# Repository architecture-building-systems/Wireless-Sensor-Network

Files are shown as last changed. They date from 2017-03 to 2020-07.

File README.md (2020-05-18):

# Wireless Sensor Network

## Introduction
This repository contains all files needed to reproduce the Wireless Sensor Network (WSN) used for the Data-Driven Building Retrofit Research of the [A/S Chair](http://www.systems.arch.ethz.ch/). 
The WSN is intended to be deployed in residential buildings to collect sensor data for building model calibration. The microcontroller boards are based on the Arduino framework. For wireless communication, XBee radio modules are used.

See the [Wiki](https://github.com/architecture-building-systems/Wireless-Sensor-Network/wiki) for documentation, instructions, and other resources.

## Structure of the WSN
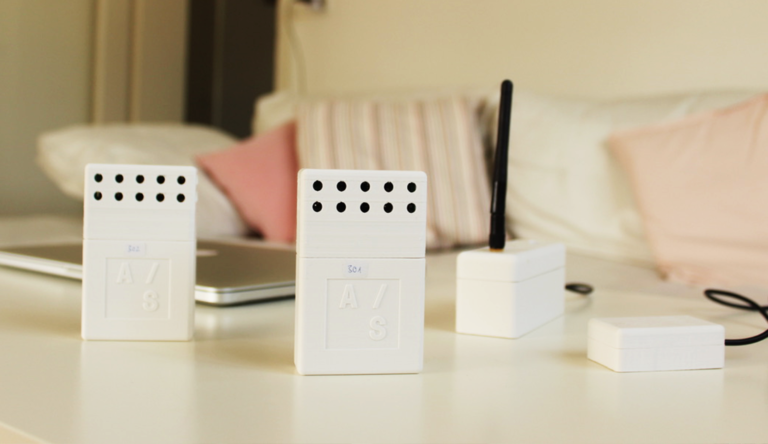
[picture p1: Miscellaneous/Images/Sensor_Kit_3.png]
Sensor-Kit
  
Sensor-Kit: (from left to right) two sensor nodes, gateway and router node

The WSN has a modular structure. The main components are the following:
* Gateway
* Router Node
* Sensor Node

On the sensor node, the sensor readings are performed and the data is relayed over router nodes to the gateway using the XBee network. The gateway forwards the data over cellular network to a web server, where the data is stored in a MySQL database. It is also possible to use a sensor node as data logger without any radio communication.

### Sensor Node
Sensor nodes consist of two parts: the main module and the sensor module. The sensor module interfaces the actual sensor(s). It reads out the sensor reading and transmits the result via the serial bus in a unified format to the main module. The main module interfaces the sensor module, radio transceiver, and the battery. It forwards the readings from the sensor module to the gateway. Both, the main module and the sensor module, can be programmed using the Arduino IDE.

#### Main Module
The main module is the same on all sensor nodes. It entails the following:
* Microcontroller (ATmega328p)
* Real-time clock (DS3231)
* Battery (2000mAh LiPo)
* SD-card socket
* XBee radio module (XB24CZ7WIT-004)
* Slide switch and LEDs for debugging
* Power jack for external power
* Connectors to sensor module

The tasks of the main module are:
* Scheduling (RTC or interrupt from sensor module)
* Interfacing the sensor module
* Interfacing XBee
* Interfacing SD-card
* Reading the charge state of the battery
* Switching between normal operation and debugging mode

#### Sensor Module
The sensor module interfaces the actual sensor(s). Each sensor or sensor configuration needs its own sensor module design.
The following sensor modules are available:
* Temperature and Humidity (SHT31)
* Luminosity (TSL2561)
* Pulse
* CO2 (S8)
* Heat Flux (gSKIN XO)
* Dual Temperature (DS18B20)
* Prototyping

There are two kinds of sensor modules: sensor modules for periodic measurements (fixed time interval) and sensor modules for event based measurements (interrupt driven). On the first power-up of the main module, the type of the sensor module is requested, in order to set the mode to periodic measurements or event based measurements. For periodic measurements, the main module is woken up by the RTC on the main module. It then turns on the power to the sensor module. After power-up of the sensor module, it reads out the sensor(s) and transmits the readings over the serial bus. Then the power to the sensor module is cut by the main module and the data is written to the SD-card and/or sent to the gateway via radio.
For event based measurements the sensor module is always powered on. The main module is woken up by an interrupt signal from the sensor module instead of the RTC. The data transfer is the same as for the periodic measurements. 

### Gateway
The gateway receives the data from the sensor nodes and relays the data to a web server via 3G cellular network. The gateway consists of Adafruit Feather 32u4 FONA and a XBee radio-module. The Adafruit Feather 32u4 FONA can be programmed using the Arduino framework. The gateway is powered via USB power supply and needs to be always powered on.

### Router Node
A router node consists of XBee-radio module and SparkFun XBee Explorer Regulated Board. The router node is powered by a wall adapter power supply. It always needs to be powered on.

## Publications
 * [Wireless sensor network for estimating building performance](https://sciencedirect.com/science/article/pii/S0926580519307472)
 * [An easily-deployable wireless sensor network for building energy performance assessment](https://www.sciencedirect.com/science/article/pii/S1876610217329077)
 
 ## Cite us


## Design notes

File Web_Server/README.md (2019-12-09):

# Webserver
Two tasks are assigned to the webserver: 
1. Inserting the measurement data into the database and 
2. Displaying the measured data. All scripts are written in PHP.

## Storing Measured Data
All the files for storing the measured data in the database are in the [/gateway2mysql/ directory](PHP/gateway2mysql/). The main file is [gateway2mysql.php](PHP/gateway2mysql/gateway2mysql.php), which is also called by the gateway. The data is attached as an URL-parameter.
Currently, battery warning messages and data from the heat flux sensors need to be treated separately, since these messages do not yet adhere to the standard formatting. 

## Displaying Data
Files for these tasks can be found in the [/vis/](PHP/vis/) directory. The main file is [isituprightnow_v4.php](PHP/vis/isituprightnow_v4.php). The site shows tables. The left hand side table gives an overview of the gateway activity. The gateway number is clickable and leads to an overview of the sensor nodes. The right hand side table gives an overview of all the sensor nodes of one gateway. The node id is clickable and links to a graph of the respective measured data.

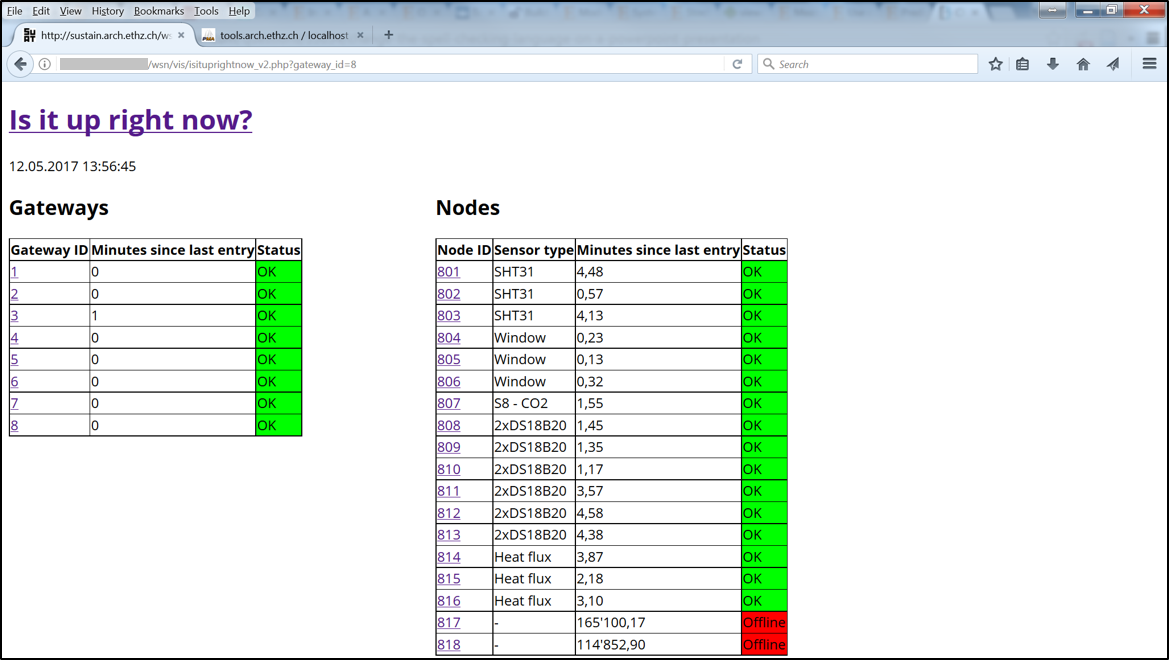
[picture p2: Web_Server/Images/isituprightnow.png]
Table
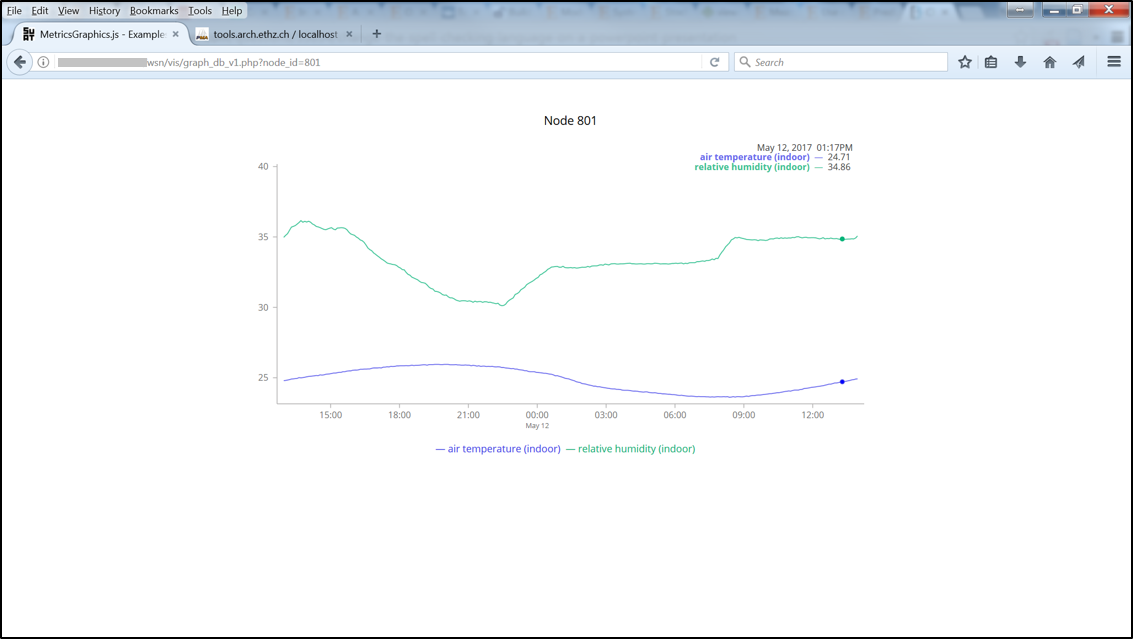
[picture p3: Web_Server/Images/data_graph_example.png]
Graph
 

## Setup
In order to setup the webserver the following needs to be done: 
* Import the MySQL database structure in phpMyAdmin using the SQL file in the [MySQL directory](MySQL).
* Copy the files from the folder [PHP](PHP) into the root directory of your webserver.
* Add the login credentials for the database to the [config file](PHP/config.php).
* Add the e-mail address of the admin to the [config file](PHP/config.php).
* Add the URL of your webserver to the Arduino [script for the gateway](../Gateway/Arduino). The URL should look something like this: yourdomainname.com/gateway2mysql/gateway2mysql.php

There are two main PHP scripts:
* [PHP/vis/isituprightnow_v4.php](PHP/vis/isituprightnow_v4.php) gives an overview of the status of sensor nodes.
* [PHP/gateway2mysql/gateway2mysql.php](PHP/gateway2mysql/gateway2mysql.php) is called by the gateways. It takes the payload message with the measured data, disaggregates it and inserts it in the database.

## A word of Caution
Some inputs might be properly sanitized. And database quere do not use prepared statements. Hence, there is some risk of cross-site scripting vulnerability. Thus, we strongly suggest to not expose the web-interface to the public and to only share it with trusted parties. Otherwise, one might risk damage or loss of all contents of the database.

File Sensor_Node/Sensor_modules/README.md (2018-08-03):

# Sensor Modules

We are currently revising all sensor modules.

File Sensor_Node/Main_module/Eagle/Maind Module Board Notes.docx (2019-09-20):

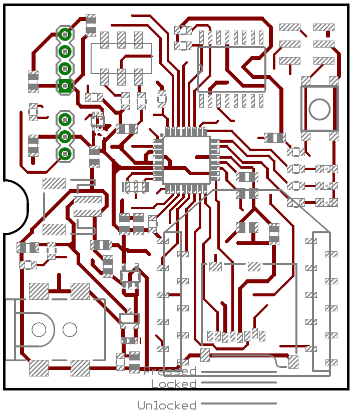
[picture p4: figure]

Board Notes

TOP

BOTTOM

Arduino ISP Connector:

MISO | | Top Right | VIN (3.3V)
SCK | | | GND
MOSI | Bot. Left | | RESET

Parts Assembly:

- Y1: Oscillator, orientation does not matter
- LEDs L1, L2, L3: Green marking towards East

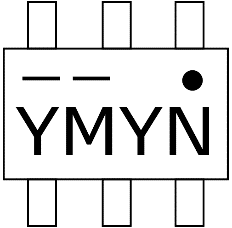
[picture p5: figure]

- U3: IC markings look like this when looking closely:
- D1: Diode, marking towards East

Sensor Module Connectors:

GND
to SM’s RXI
to SM’s TXO
Controlled SM Supply Voltage
Continuous supply voltage from SM
Continuous supply voltage towards SM
Wakeup interrupt from SM

DO NOT PLUG IN SUPPLY VOLTAGE JACK OF COMM. MODULE WHILE 3 PIN SENSOR MODULE CONNECTOR IS USED! (Because if sensor module is also externally powered, then there is a short between the two supply voltages through the “Continuous V from SM” or “Continuous V towards SM” pin)

For a periodic sensor module, only the 4 pin connector is needed. For an interrupting sensor module, the three pin connector is needed as well. Then the “Controlled SM Supply Voltage” pin does not have to be connected on the sensor module anymore, but it can be supplied through “Continuous supply voltage towards SM”, or if the sensor module has a constant power source, then the communication module can be supplied through “Continuous supply voltage from SM”.

Setup

- Program via Arduino ISP. In the Arduino IDE, the programmer that is selected must be “Arduino as ISP” and the program then upload using Sketch > Upload Using Programmer
- After assembling communication module: Burn bootloader via Arduino ISP (Tools > Burn Bootloader)
- If a XBee module is not found in XCTU, it is probably because it has been configured to be in sleep mode (SM = 1). To add the module in XCTU, you need to pull the sleep pin (= pin 9) to GND (= pin 10) while adding it and reading the parameters in XCTU.

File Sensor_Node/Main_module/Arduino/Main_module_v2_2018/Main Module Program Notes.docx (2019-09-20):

Program Notes

General

For periodic sensor modules, the communication module takes the first measurement 5 seconds after having been started.

The SD card is optional and can be inserted or left out without any additional configuration. The SD card can also be inserted when the communication module is already running. The SD card can be removed from a running communication module, however the tasks will draw a bit more energy from then on (reason unknown, seems to be something in the SD card library for Arduino) and the SD card cannot be reinserted (Unless the communication module is reset using the reset button).

Startup LED Indicators

At the start, the LEDs indicate successful initialization:

- LED 1 (bottom, red) turns on when the RTC has been initialized successfully
- LED 2 (middle, green) flashing while XBee is trying to join network, stays turned on when network successfully joined
- LED 3 (top, orange) turns on when SD card successfully initialized. (Or if no SD card is inserted the LED also just turns on)

After two seconds all the LEDs turn off.
After two more seconds, the sensor module is checked. LED 1 (bottom, red) lights up when the sensor module is asked for a measurement. Then either of the other two LEDs will light up for 1 second:

- LED 2 (middle, green) if the sensor module is an interrupting one, meaning we will not ask it periodically but it will interrupt the communication module when an event happens
- LED 3 (top, orange) if the sensor module is one that we wake up periodically to take a measurement.

If no LED lights up after LED 1 (bottom, red), then something with the sensor module or the communication is not ok.

Debug Mode

To enter debug mode, the slide switch must be on the east position when the communication module is started. Debug mode cannot be entered while the communication module is already running. Debug mode can be disabled while the communication module is running by putting it into the west position. In the debug mode, the LEDs indicate the status as follows:

For Periodic Sensor:
In the Debug mode, a measurement is taken, transmitted via XBee and written to the SD card (if inserted) every 10 seconds (actually every 10 seconds plus time it takes for the task). When exiting the debug mode, the configured parameters for “measurement every x minute” and “transmit/SD write every x times” will be applied.

- LED 1 (bottom, red) turns on when the RTC interrupt occurs
- LED 2 (middle, green) turns on when all data has been received from the sensor module
- LED 3 (top, orange) turns on when the data has been transmitted via XBee
- The LEDs turn off after 2 second when the SD card write has been successful (or if no SD card is inserted the LEDs will also just turn off after 1 second). If the SD write has caused an error, the LEDs will just stay turned on.

For Interrupting Sensor:

- LED 1 (bottom, red) turns on when the sensor module’s interrupt has woken up the communication module
- LED 2 (middle, green) turns on when all data has been received from the sensor module
- LED 3 (top, orange) turns on when the data has been transmitted via XBee
- The LEDs turn off after 2 second when the SD card write has been successful (or if no SD card is inserted the LEDs will also just turn off after 1 second). If the SD write has caused an error, the LEDs will just stay turned on.

Low Battery

When the configured low battery voltage is reached, one warning message is sent via XBee and then the module stays in sleep mode; it does not wake up or take measurements anymore to save battery.

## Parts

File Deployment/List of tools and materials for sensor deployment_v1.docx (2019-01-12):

List of Materials and Tools for Sensor Deployment

- Adhesives and fastener
  - Uhu Pattafix Deco adhesive pad
  - Tesa Power Strips, small
  - Tesa Power Strips, large
  - White electrical tape, narrow
  - White electrical tape, wide
  - Painters tape
  - Double sided tape, strong/outdoor
  - Universal duct tape
  - Heat conducting double sided tape
  - Cable ties, velcro ties
- Cleaning
  - Tesa adhesive removal
  - Acetone
  - Ajax windows cleaner
  - Glass scraper
  - Sand paper
  - Paper towels
  - Latex gloves
  - Rugs
  - Dusting brush & pan
  - Trash bag
- Tools
  - Knife
  - Screw drivers
  - Multimeter
- Electronics
  - Arduino ISP-Programmer
  - FTDI Programmer
  - Xbee Programmer
  - Camera
  - Thermal camera
  - Extension cords
  - Multi-plugs
  - Spare parts
- Documents
  - Information sheet for building owners
  - List of sensor location
  - Questionnaire
  - Pen
  - Clipboard
- Other
  - Trolley
  - Pipe insulation
- ____________________________________
- ____________________________________
- ____________________________________

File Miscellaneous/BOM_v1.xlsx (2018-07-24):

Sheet: Main Module - Xbee
Main Module - Xbee
Description | Pcs | Price | Total |  |  | Link | Remarks
Battery 2000mAh | 1 | 25.40 | 25.40 | USD | 35.36117121% | http://www.play-zone.ch/de/elektronik-kit-zubehoer/netzteile/akkus-charger-booster/polymer-lithium-ion-lipo-akku-2000mah.html
Xbee Series 2 | 1 | 18.19 | 18.19 | USD | 25.3236104% | https://www.digikey.ch/short/39m8w1
RTC DS3231 | 1 | 6.22 | 6.22 | USD | 8.659310429% | https://www.digikey.ch/short/39mzrv
microSD Socket | 1 | 3.95 | 3.95 | USD | 5.499079774% | https://www.sparkfun.com/products/127
Microcontroller ATmega328p | 1 | 3.58 | 3.58 | USD | 4.983976099% | https://www.digikey.ch/short/39mzf8
Female Pin Header Xbee | 2 | 1.48 | 2.96 | USD | 4.1208294% | https://www.digikey.ch/short/39m8d0
PCB | 1 | 2.00 | 2.00 | USD | 2.784344189% | https://www.jlcpcb.com
Power Jack | 1 | 1.84 | 1.84 | USD | 2.561596654% | https://www.digikey.ch/short/39mzfr
Molex 3 pin header | 1 | 1.03 | 1.03 | USD | 1.440898118% | http://www.digikey.ch/short/39m432
Molex 4 pin header | 1 | 0.84 | 0.84 | USD | 1.172208904% | http://www.digikey.ch/short/39m43r
Voltage Regulator | 1 | 0.77 | 0.77 | USD | 1.074756857% | https://www.digikey.ch/short/39mz1n
Capacitor 10uF | 8 | 0.09 | 0.76 | USD | 1.051368366% | https://www.digikey.ch/short/39m4c7
Battery Connector | 1 | 0.58 | 0.58 | USD | 0.807459815% | https://www.digikey.ch/short/3bwfbw
Debug Switch | 1 | 0.43 | 0.43 | USD | 0.6008614761% | https://www.digikey.ch/short/39mzvc
High side switch IC | 1 | 0.40 | 0.40 | USD | 0.5518570184% | https://www.digikey.ch/short/39mzvn
LED yellow | 1 | 0.39 | 0.39 | USD | 0.5415549449% | https://www.digikey.ch/short/39mz24
Resonator | 1 | 0.38 | 0.38 | USD | 0.5345940844% | https://www.digikey.ch/short/39mz18 | End of Life
LED red | 1 | 0.38 | 0.38 | USD | 0.5332019123% | https://www.digikey.ch/short/39mzvh
Mosfet | 1 | 0.33 | 0.33 | USD | 0.4622011355% | https://www.digikey.ch/short/39mmtz
LED green | 1 | 0.33 | 0.33 | USD | 0.4566324471% | https://www.digikey.ch/short/39mzvj
SPI Pin Header | 1 | 0.30 | 0.30 | USD | 0.4148672842% | https://www.digikey.ch/short/39mz0t
Schottky Diode | 1 | 0.27 | 0.27 | USD | 0.3758864656% | https://www.digikey.ch/short/39mzwn
Capacitor 0.1uF | 9 | 0.02 | 0.19 | USD | 0.2606146161% | https://www.digikey.ch/short/39mzwv
Reset Switch | 1 | 0.14 | 0.14 | USD | 0.1971315686% | https://www.digikey.ch/short/39mz1b
Resistor 10k | 5 | 0.01 | 0.05 | USD | 0.06403991636% | https://www.digikey.ch/short/jmv2r2
Resistor 4.7k | 2 | 0.01 | 0.03 | USD | 0.04176516284% | https://www.digikey.ch/short/39m4cz
Resistor 330 | 3 | 0.01 | 0.03 | USD | 0.03842394981% | https://www.digikey.ch/short/39m470
Resistor 10M | 2 | 0.01 | 0.02 | USD | 0.02561596654% | https://www.digikey.ch/short/39mzd2
Resistor 100k | 1 | 0.02 | 0.02 | USD | 0.02116101584% | https://www.digikey.ch/short/39mznv
Resistor 1M | 1 | 0.02 | 0.02 | USD | 0.02116101584% | https://www.digikey.ch/short/39mzd8
Resistor 2M | 1 | 0.01 | 0.01 | USD | 0.01781980281% | https://www.digikey.ch/short/39mzd9
Housing | 1 |  |  |  |  |  | 3D printed
Total |  |  | 71.83 | USD

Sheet: Sensor Module - Base
Sensor Module - Base
Description | Pcs | Price | Total |  |  | Link | Remarks
PCB | 1 | 2.00 | 2.00 | USD | 20.67371503% | https://www.jlcpcb.com
Microcontroller ATmega328p | 1 | 3.58 | 3.58 | USD | 37.0059499% | https://www.digikey.ch/short/39mzf8
Resonator | 1 | 0.38 | 0.38 | USD | 3.969353285% | https://www.digikey.ch/short/39mz18
LED red | 1 | 0.38 | 0.38 | USD | 3.959016427% | https://www.digikey.ch/short/39mzvh
LED yellow | 0 | 0.39 | 0.00 | USD | 0% | https://www.digikey.ch/short/39mz24 | Not populated
LED green | 0 | 0.33 | 0.00 | USD | 0% | https://www.digikey.ch/short/39mzvj | Not populated
Capacitor 0.1uF | 2 | 0.02 | 0.04 | USD | 0.4300132725% | https://www.digikey.ch/short/39mzwv
Resistor 330 | 1 | 0.01 | 0.01 | USD | 0.09509908912% | https://www.digikey.ch/short/39m470
Resistor 10k | 2 | 0.01 | 0.02 | USD | 0.1901981782% | https://www.digikey.ch/short/jmv2r2
SPI Pin Header | 1 | 0.30 | 0.30 | USD | 3.080383539% | https://www.digikey.ch/short/39mz0t
Debug Switch | 1 | 0.43 | 0.43 | USD | 4.461387702% | https://www.digikey.ch/short/39mzvc
Reset Switch | 1 | 0.14 | 0.14 | USD | 1.463699024% | https://www.digikey.ch/short/39mz1b
Molex Housing 3 pin | 1 | 0.36 | 0.36 | USD | 3.671651788% | https://www.digikey.ch/short/39m4f2
Molex Housing 4 pin | 1 | 0.37 | 0.37 | USD | 3.820502537% | https://www.digikey.ch/short/39m4fm
Cable pre-crimp | 4 | 0.42 | 1.66 | USD | 17.17903024% | https://www.digikey.ch/short/39m429
Total |  |  | 9.67 | USD

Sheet: Sensor Module - Heat Flux
Sensor Module - Heat Flux
Description | Pcs | Price | Total |  |  | Link
Heat flux sensor gSKIN-XO | 1 | 615.00 | 615.00 | USD | 98.45331917% | https://shop.greenteg.com/shop/building/robust-heat-flux-sensor-gskin-xo/
PCB | 1 | 2.00 | 2.00 | USD | 0.3201733957% | https://www.jlcpcb.com
Microcontroller PIC16F1825-I/ST | 1 | 1.37 | 1.37 | USD | 0.219318776% | https://www.digikey.ch/short/jmv210
Analog front end MCP3911 | 1 | 2.00 | 2.00 | USD | 0.3201733957% | https://www.digikey.ch/short/jmvf78
IC Switch TI 4066 | 1 | 0.47 | 0.47 | USD | 0.07524074798% | https://www.digikey.ch/short/jmvf1w
Diode Array BAV99 | 3 | 0.26 | 0.78 | USD | 0.1248676243% | https://www.digikey.ch/short/jmv2qq
Resistor 10k | 1 | 0.01 | 0.01 | USD | 0.001600866978% | https://www.digikey.ch/short/jmv2r2
Capacitor 100n | 6 | 0.02 | 0.12 | USD | 0.01921040374% | https://www.digikey.ch/short/39mzwv
Capacitor 1u | 2 | 0.13 | 0.26 | USD | 0.04162254144% | https://www.digikey.ch/short/jmv2z9
Resistor 0k | 1 | 0.10 | 0.10 | USD | 0.01600866978% | https://www.digikey.ch/short/jmv2w7
Ferrite Bead | 1 | 0.32 | 0.32 | USD | 0.05122774331% | https://www.digikey.ch/short/jmv2w5
Molex Housing 4 pin | 1 | 0.37 | 0.37 | USD | 0.05916804352% | https://www.digikey.ch/short/39m4fm
Cable pre-crimp | 4 | 0.42 | 1.66 | USD | 0.2660512849% | https://www.digikey.ch/short/39m429
Pin header, male, 5-pin | 1 | 0.20 | 0.20 | USD | 0.03201733957% | https://www.digikey.ch/short/jmvwjh
Total |  |  | 624.66 | USD

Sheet: Sensor Module - SHT31
Sensor Module - SHT31
Description | Pcs | Price | Total |  |  | Link
Sensor module base | 1 | 9.67 | 9.67 | USD | 38.69010387% | https://www.adafruit.com/product/2857
Temperature and humidity sensor SHT31 | 1 | 13.95 | 13.95 | USD | 55.79080568% | https://www.adafruit.com/product/2857
Pin header, female, 7-pin | 1 | 1.35 | 1.35 | USD | 5.399110227% | https://www.digikey.ch/short/jmvwb5
Resistor 10k | 1 | 0.01 | 0.01 | USD | 0.03679393636% | https://www.digikey.ch/short/jmv2r2
Capacitor 100n | 1 | 0.02 | 0.02 | USD | 0.0831862909% | https://www.digikey.ch/short/39mzwv
Total |  |  | 25.00 | USD

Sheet: Sensor Module - TSL2561
Sensor Module - TSL2561
Description | Pcs | Price | Total |  |  | Link | Remarks
Sensor module base | 1 | 9.67 | 9.67 | USD | 56.8928001% | https://www.adafruit.com/product/2857
Luminosity sensor TSL2561 | 1 | 5.95 | 5.95 | USD | 34.9915197% | https://www.adafruit.com/product/439 | End of life
Pin header, female, 6-pin | 1 | 1.35 | 1.35 | USD | 7.939252369% | https://www.digikey.ch/short/jmvwv2
Resistor 10k | 1 | 0.01 | 0.01 | USD | 0.05410453467% | https://www.digikey.ch/short/jmv2r2
Capacitor 100n | 1 | 0.02 | 0.02 | USD | 0.1223232958% | https://www.digikey.ch/short/39mzwv
Total |  |  | 17.00 | USD

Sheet: Sensor Module - DS18B20
Sensor Module - DS18B20
Description | Pcs | Price | Total |  |  | Link
Sensor module base | 1 | 9.67 | 9.67 | USD | 32.67828937% | https://www.adafruit.com/product/2857
Temperature sensor DS18B20 | 2 | 9.95 | 19.90 | USD | 67.22037338% | https://www.adafruit.com/product/381
Resistor 4.7k | 2 | 0.01 | 0.03 | USD | 0.1013372463% | https://www.digikey.ch/short/39m4cz
Total |  |  | 29.60 | USD

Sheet: Sensor Module - Pulse
Sensor Module - Pulse
Description | Pcs | Price | Total |  |  | Link | Remarks
Sensor module base | 1 | 9.67 | 9.67 | USD | 22.35172125% | https://www.adafruit.com/product/2857
Debouncer | 2 | 9.95 | 19.90 | USD | 45.97826499% | https://www.adafruit.com/product/381
Capacitor 0.1uF | 9 | 0.02 | 0.19 | USD | 0.4325191561% | https://www.digikey.ch/short/39mzwv
Debouncer IC MAX6816EUS+T | 1 | 3.41 | 3.41 | USD | 7.878687619%
Reed Switch | 1 | 7.18 | 7.18 | USD | 16.58914284% | https://www.digikey.ch/short/jmvd74 | For windows opening times
Light to voltage converter TSL257 | 1 | 2.93 | 2.93 | USD | 6.769664141% | https://www.digikey.ch/short/jmvd3p | For light pulses
2 wired cable |  |  |  |  |  |  | For electric pulses
Total |  |  | 43.28 | USD

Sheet: Sensor Module - S8
Sensor Module - S8
Description | Pcs | Price | Total |  |  | Link
Sensor module base | 1 | 9.67 | 9.67 | USD | 10.19817139% | https://www.adafruit.com/product/2857
CO2 Sensor S8 | 1 | 85.00 | 85.00 | USD | 89.6044879% | http://www.co2meter.com/collections/co2-sensors/products/s8-miniature-co2-sensor-1
Capacitor 0.1uF | 9 | 0.02 | 0.19 | USD | 0.1973407075% | https://www.digikey.ch/short/39mzwv
Total |  |  | 94.86 | USD

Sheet: Gateway
Gateway
Description | Pcs | Price | Total |  |  | Link | Remarks
PCB | 1 | 2.00 | 2.00 | USD | 1.7860715% | https://www.jlcpcb.com
Adafruit 32u4 FONA | 1 | 44.95 | 44.95 | USD | 40.14195696% | https://www.adafruit.com/product/3027
LED red | 1 | 0.38 | 0.38 | USD | 0.3420326923% | https://www.digikey.ch/short/39mzvh
LED yellow | 1 | 0.39 | 0.39 | USD | 0.3473909068% | https://www.digikey.ch/short/39mz24
LED green | 1 | 0.33 | 0.33 | USD | 0.292915726% | https://www.digikey.ch/short/39mzvj
Resistor 330 | 3 | 0.01 | 0.03 | USD | 0.0246477867% | https://www.digikey.ch/short/39m470
Xbee Series 2 | 1 | 18.19 | 18.19 | USD | 16.24432029% | https://www.digikey.ch/short/39m8w1
Pin header, female, Xbee | 2 | 1.48 | 2.96 | USD | 2.64338582% | https://www.digikey.ch/short/39m8d0
Pin header, female, 12pin | 1 | 0.98 | 0.98 | USD | 0.875175035% | https://www.digikey.ch/short/39m80b
Pin header, female, 12pin | 1 | 1.22 | 1.22 | USD | 1.089503615% | https://www.digikey.ch/short/39m80p
Battery, LiPo, 1000mAh | 1 | 15.20 | 15.20 | USD | 13.5741434% | http://www.play-zone.ch/de/elektronik-kit-zubehoer/netzteile/akkus-charger-booster/polymer-lithium-ion-lipo-akku-1000mah.html
Antenna | 1 | 7.03 | 7.03 | USD | 6.278041323% | http://www.play-zone.ch/de/gsm-antenne-2-4-5-8ghz.html
Antenna cable SMA to u.Fl | 1 | 3.95 | 3.95 | USD | 3.527491213% | https://www.digikey.ch/short/39m8v4
Power Supply | 1 | 14.37 | 14.37 | USD | 12.83292373% | https://www.digitec.ch/de/s1/product/samsung-eta-u90-reiseladegeraet-2a-micro-usb-tablet-stromversorgung-434009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
Housing | 1 |  |  |  | 0% |  | 3D-printed
Total |  |  | 111.98 | USD

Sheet: Sheet9
Hop Node
Description | Pcs | Price | Total |  |  | Link | Remarks
Xbee explorer regulated | 1 | 2.00 | 2.00 | USD | 7.955449483% | http://www.digikey.ch/short/39h71v
Xbee Series 2 | 1 | 18.19 | 18.19 | USD | 72.35481305% | https://www.digikey.ch/short/39m8w1
Power Supply | 1 | 4.95 | 4.95 | USD | 19.68973747% | http://www.pearl.ch/ch-a-PX3372-1021.shtml?query=ladeger%C3%A4t
Housing | 1 |  |  |  | 0% |  | 3D-printed
Total |  |  | 25.14 | USD

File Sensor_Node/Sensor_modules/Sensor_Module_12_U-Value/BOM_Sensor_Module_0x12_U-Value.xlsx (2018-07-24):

BOM_Sensor_Board_0x07_Heat_Flux_v2
Name | Identifier | Pieces | Price/Piece | Total | Link
ATMEGA328
Microcontroller ATmega328p | U2 | 1 | CHF 2.07 | CHF 2.07 | https://www.digikey.ch/short/39mzf8
8 MHz Resonator | Y1 | 1 | CHF 0.48 | CHF 0.48 | https://www.digikey.ch/short/39mz18
Reset-Button | S1 | 1 | CHF 0.18 | CHF 0.18 | https://www.digikey.ch/short/39mz1b
100nF-Capacitor 0805 | C1, C2, C3 | 3 | CHF 0.10 | CHF 0.30 | https://www.digikey.ch/short/39mzwv
10k-Resistor 0805 | R2 | 1 | CHF 0.10 | CHF 0.10 | https://www.digikey.ch/short/jmv2r2
2x DS18B20
10k-Resistor 0805 | R1, R7 | 2 | CHF 0.10 | CHF 0.20 | https://www.digikey.ch/short/jmv2r2
MAX38144 THERMOCOUPLE
MAX31855TASA+-ND | IC4 | 1 | CHF 4.57 | CHF 4.57 | https://www.digikey.ch/short/j5mmww
100nF-Capacitor 0805 | C9, C10 | 2 | CHF 0.10 | CHF 0.20 | https://www.digikey.ch/short/39mzwv
10k-Resistor 0805 | R10 | 1 | CHF 0.10 | CHF 0.10 | https://www.digikey.ch/short/jmv2r2
Ferrite-Core | FB1, FB2 | 2 | CHF 0.25 | CHF 0.50 | https://www.digikey.ch/short/j5mmnt
MCP3911 24-BIT ADC
MCP3911A0T-E/SSCT-ND | IC1 | 1 | CHF 2.00 | CHF 2.00 | https://www.digikey.ch/short/jmvf78
100nF-Capacitor 0805 | C4, C5, C6, C7, C8 | 5 | CHF 0.10 | CHF 0.50 | https://www.digikey.ch/short/39mzwv
10k-Resistor 0805 | R4, R5 | 2 | CHF 0.10 | CHF 0.20 | https://www.digikey.ch/short/jmv2r2
Diode Array BAV99 | D1 | 0 | CHF 0.25 | CHF 0.00 | https://www.digikey.ch/short/jmv2qq
Dide array (second source) | D1 | 1 | CHF 0.14 | CHF 0.14 | https://www.digikey.ch/short/j5mmwt
IC Switch TI 4066 | IC2 | 1 | CHF 0.50 | CHF 0.50 | https://www.digikey.ch/short/jmvf1w
GND/VCC plane connection
Resistor 0k | R6 | 1 | CHF 0.10 | CHF 0.10 | https://www.digikey.ch/short/jmv2w7
Ferrite Bead | L1 | 1 | CHF 0.32 | CHF 0.32 | https://www.digikey.ch/short/jmv2w5
Communication Module connector
AMP 4pin connector | J1 | 1 | CHF 0.70 | CHF 0.70 | https://www.digikey.ch/short/j5mmnq
Programming Connector
SPI Pin Header | J4 | 1 | CHF 0.43 | CHF 0.93 | https://www.digikey.ch/short/39mz0t
Debug LED
LED rot | LED | 1 | CHF 0.38 | CHF 0.38 | https://www.digikey.ch/short/j5mmnw
Resistor 330 | R3 | 1 | CHF 0.10 | CHF 0.10 | https://www.digikey.ch/short/39m470
Total price: | CHF 14.57

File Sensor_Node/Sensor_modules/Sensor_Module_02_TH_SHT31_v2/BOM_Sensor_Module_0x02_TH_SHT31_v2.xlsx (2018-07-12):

BOM_Sensor_Board_0x02_Temperature_Humidity_SHT31_v2
Name | Identifier | Pieces | Price/Piece | Total | Link
ATMEGA328
Microcontroller ATmega328p | U2 | 1 | CHF 2.07 | CHF 2.07 | https://www.digikey.ch/short/39mzf8
8 MHz Resonator | Y1 | 1 | CHF 0.48 | CHF 0.48 | https://www.digikey.ch/short/39mz18
Reset-Button | S1 | 1 | CHF 0.18 | CHF 0.18 | https://www.digikey.ch/short/39mz1b
100nF-Capacitor 0805 | C1, C2, C3 | 3 | CHF 0.10 | CHF 0.30 | https://www.digikey.ch/short/39mzwv
10k-Resistor 0805 | R2 | 1 | CHF 0.10 | CHF 0.10 | https://www.digikey.ch/short/jmv2r2
Temperature Sensor SHT31
SHT31 | U1 | 1 | CHF 8.11 | CHF 8.11 | https://www.digikey.ch/product-detail/de/sensirion-ag/SHT31-DIS-B/1649-1011-1-ND/5872294
100nF-Capacitor 0805 | C4 | 1 | CHF 0.10 | CHF 0.10 | https://www.digikey.ch/short/39mzwv
10k-Resistor 0805 | R4 | 1 | CHF 0.10 | CHF 0.10 | https://www.digikey.ch/short/jmv2r2
100k-Resistor 0805 | R5 | 1 | CHF 0.10 | CHF 0.10 | https://www.digikey.ch/short/39mznv
Communication Module connector
AMP 4pin connector | J1 | 1 | CHF 0.70 | CHF 0.70 | https://www.digikey.ch/product-detail/en/te-connectivity-amp-connectors/147721-3/A108812CT-ND/4031444
Programming Connector
SPI Pin Header | J4 | 1 | CHF 0.43 | CHF 0.43 | https://www.digikey.ch/short/39mz0t
Debug Mode
LED rot | LED | 1 | CHF 0.38 | CHF 0.38 | https://www.digikey.ch/product-detail/de/lite-on-inc/LTST-C170CKT/160-1176-1-ND/269248
10k-Resistor 0805 | R1 | 1 | CHF 0.10 | CHF 0.10 | https://www.digikey.ch/short/jmv2r2
330-Resistor 0805 | R3 | 1 | CHF 0.10 | CHF 0.10 | https://www.digikey.ch/short/39m470
Debug Switch | S3 | 1 | CHF 0.48 | CHF 0.48 | https://www.digikey.ch/short/39mzvc
Total price: | CHF 13.73

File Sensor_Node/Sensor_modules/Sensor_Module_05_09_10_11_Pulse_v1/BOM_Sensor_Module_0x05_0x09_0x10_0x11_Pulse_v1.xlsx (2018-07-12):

BOM_Sensor_Board_0x05_0x09_0x10_0x11_Pulse_v1
Name | Identifier | Pieces | Price/Piece | Total | Link
ATMEGA328
Microcontroller ATmega328p | U2 | 1 | CHF 2.07 | CHF 2.07 | https://www.digikey.ch/short/39mzf8
8 MHz Resonator | Y1 | 1 | CHF 0.48 | CHF 0.48 | https://www.digikey.ch/short/39mz18
Reset-Button | S1 | 1 | CHF 0.18 | CHF 0.18 | https://www.digikey.ch/short/39mz1b
100nF-Capacitor 0805 | C1, C2, C3 | 3 | CHF 0.10 | CHF 0.30 | https://www.digikey.ch/short/39mzwv
10k-Resistor 0805 | R2 | 1 | CHF 0.10 | CHF 0.10 | https://www.digikey.ch/short/jmv2r2
Communication Module connector
AMP 4pin connector | SV3 | 1 | CHF 0.70 | CHF 0.70 | https://www.digikey.ch/product-detail/en/te-connectivity-amp-connectors/147721-3/A108812CT-ND/4031444
Programming Connector
SPI Pin Header | SV6 | 1 | CHF 0.43 | CHF 0.43 | https://www.digikey.ch/short/39mz0t
Interrupt to CommBoard connector
AMP 3pin connector | SV2 | 1 | CHF 0.79 | CHF 0.79 | https://www.digikey.ch/product-detail/en/harwin-inc/M20-7910342R/952-3196-1-ND/6559309
Digital Input 1
MAX6816 | U3 | 1 | CHF 3.41 | CHF 3.41 | https://www.digikey.ch/product-detail/de/maxim-integrated/MAX6816EUS-T/MAX6816EUS-TCT-ND/774155
100nF-Capacitor 0805 | C4 | 1 | CHF 0.10 | CHF 0.10 | https://www.digikey.ch/short/39mzwv
Digital Input 2
10k-Resistor 0805 | R4, R5 | 2 | CHF 0.10 | CHF 0.20 | https://www.digikey.ch/short/jmv2r2
Debug Mode
LED rot | LED | 1 | CHF 0.38 | CHF 0.38 | https://www.digikey.ch/product-detail/de/lite-on-inc/LTST-C170CKT/160-1176-1-ND/269248
10k-Resistor 0805 | R1 | 1 | CHF 0.10 | CHF 0.10 | https://www.digikey.ch/short/jmv2r2
330-Resistor 0805 | R3 | 1 | CHF 0.10 | CHF 0.10 | https://www.digikey.ch/short/39m470
Debug Switch | S3 | 1 | CHF 0.48 | CHF 0.48 | https://www.digikey.ch/short/39mzvc
Total price: | CHF 9.82

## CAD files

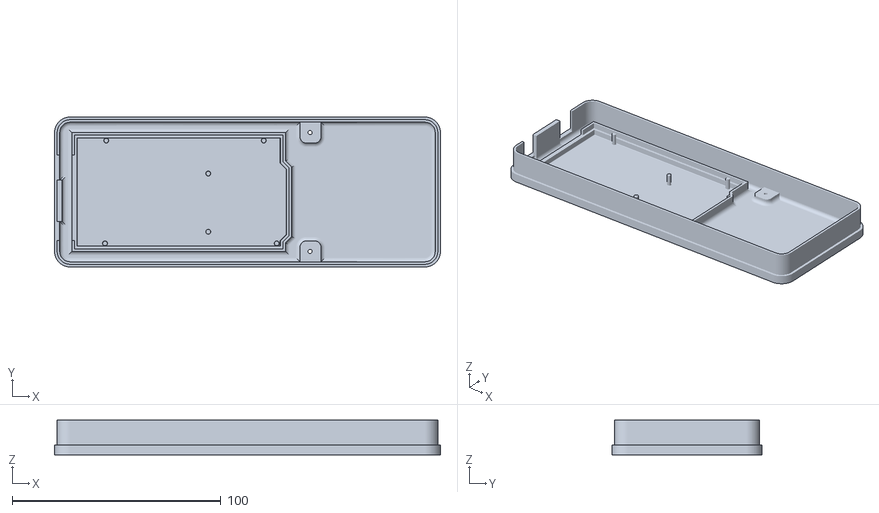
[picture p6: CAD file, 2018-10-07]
Gateway/CAD/Gateway_Mega/Gateway_Mega_Housing_v1.1_bottom.stl
185.0 x 71.9 x 16.6

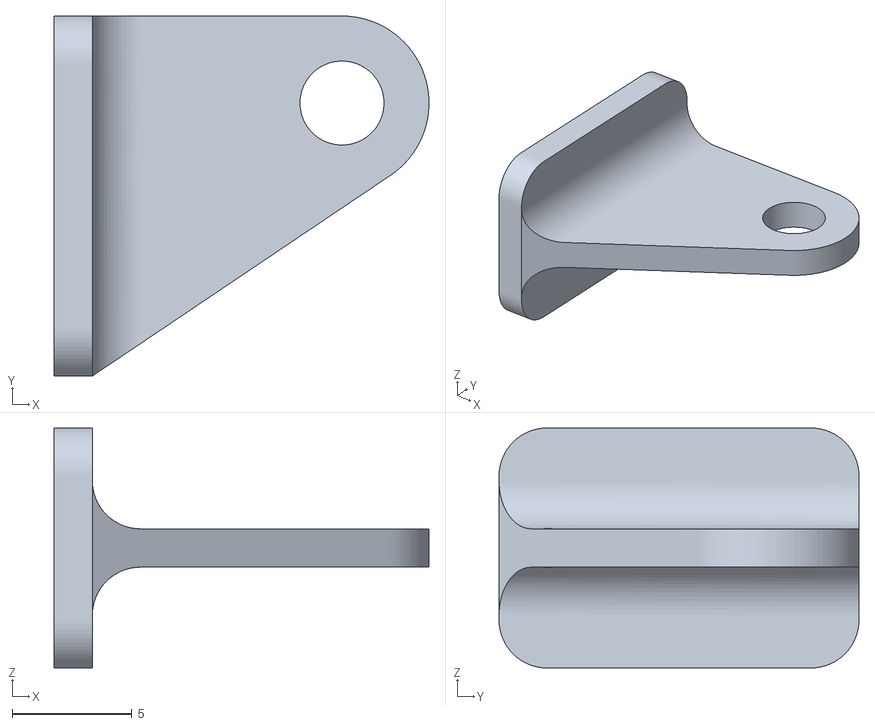
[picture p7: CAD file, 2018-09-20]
Gateway/Gateway_Feather/CAD/Gateway_housing_v7_antenna_holder.stl
15.6 x 15.0 x 10.0

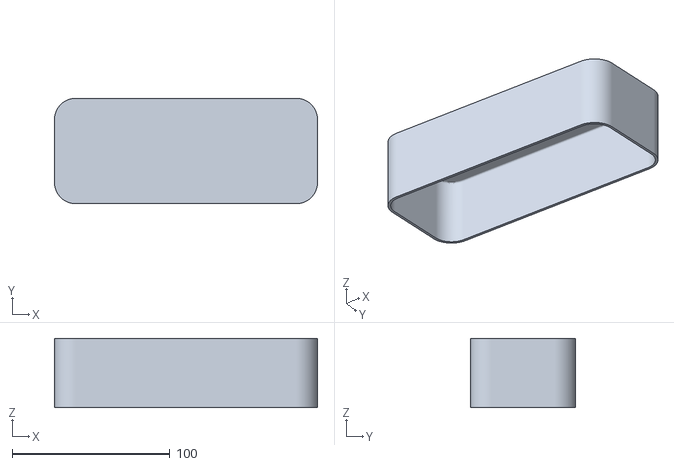
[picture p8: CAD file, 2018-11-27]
Gateway/Gateway_Mega/CAD/gateway_mega_housing_v2_top.prt.stl
166.8 x 66.8 x 44.0

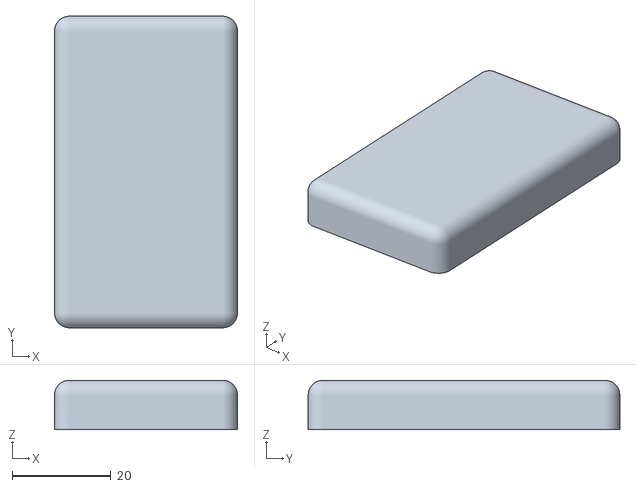
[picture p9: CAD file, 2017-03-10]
Router_Node/CAD/Router-Node_v4_top.stl
37.0 x 63.0 x 10.0

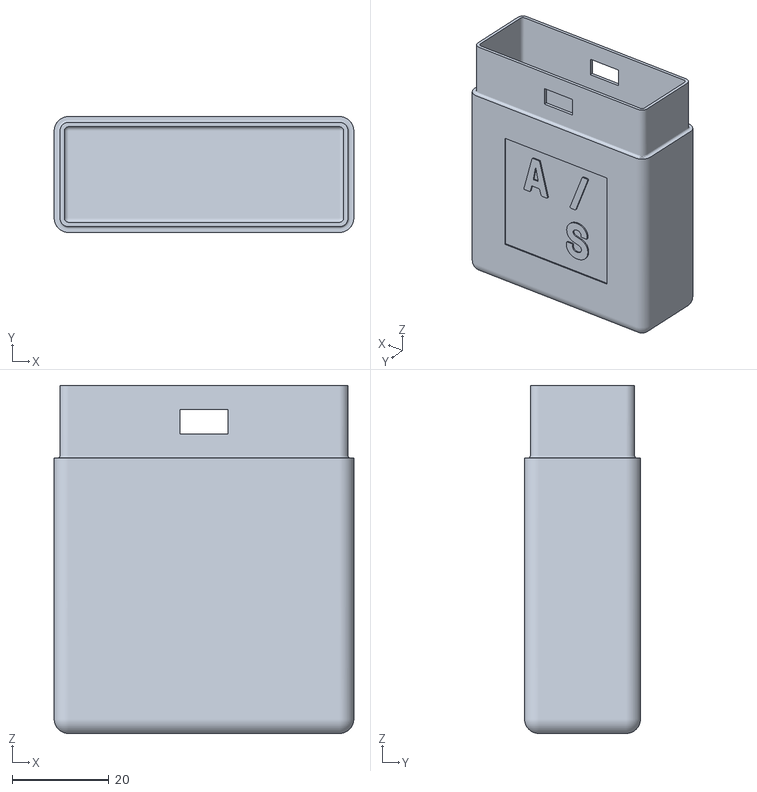
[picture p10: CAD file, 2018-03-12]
Sensor_Node/CAD/sensor_node_housing_v10.1_bottom.stl
62.0 x 24.0 x 72.0

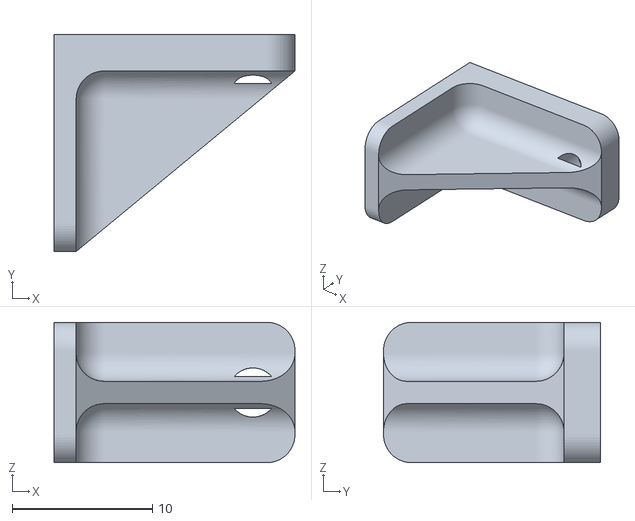
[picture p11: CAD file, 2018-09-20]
Gateway/Gateway_Feather/CAD/Gateway_housing_v7_magnet_holder_bottom.stl
17.2 x 15.5 x 10.0

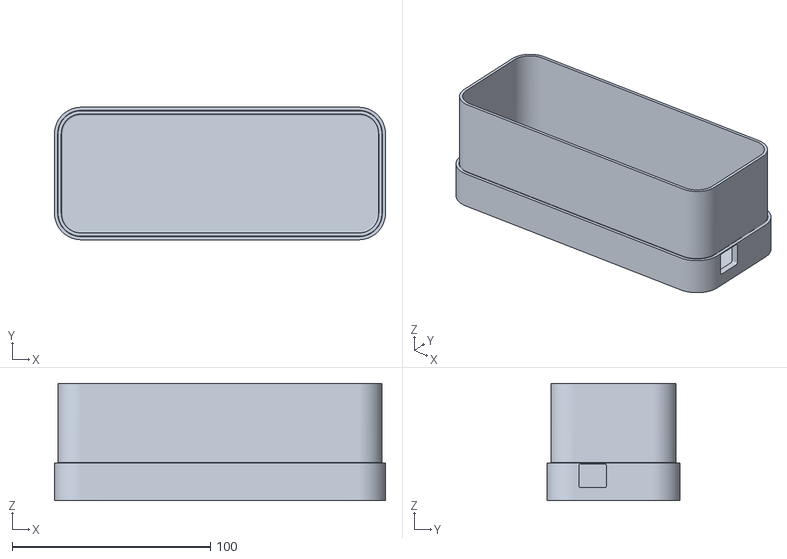
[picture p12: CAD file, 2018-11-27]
Gateway/Gateway_Mega/CAD/gateway_mega_housing_v2_bottom.prt.stl
166.8 x 66.8 x 59.0

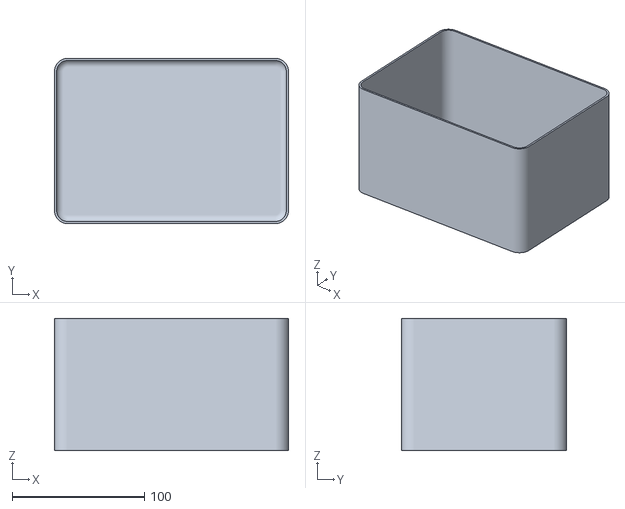
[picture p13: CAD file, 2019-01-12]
Miscellaneous/CAD/tape_container_v2.stl
177.0 x 125.0 x 100.0

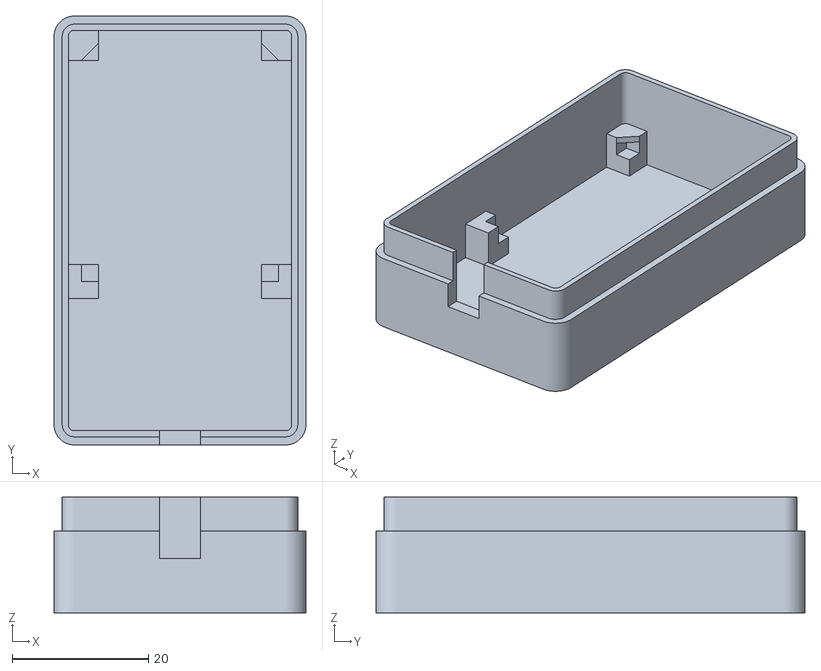
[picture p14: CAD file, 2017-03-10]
Router_Node/CAD/Router-Node_v4_bottom.stl
37.0 x 63.0 x 17.0

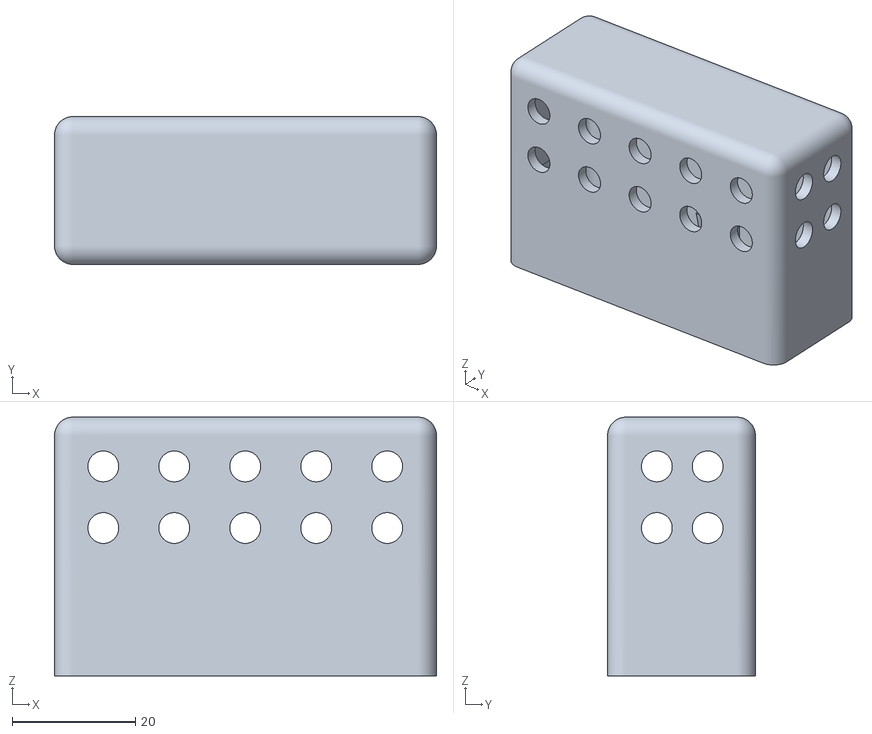
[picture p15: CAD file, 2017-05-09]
Sensor_Node/CAD/sensor_node_housing_v10_top_vent.stl
62.0 x 24.0 x 42.0

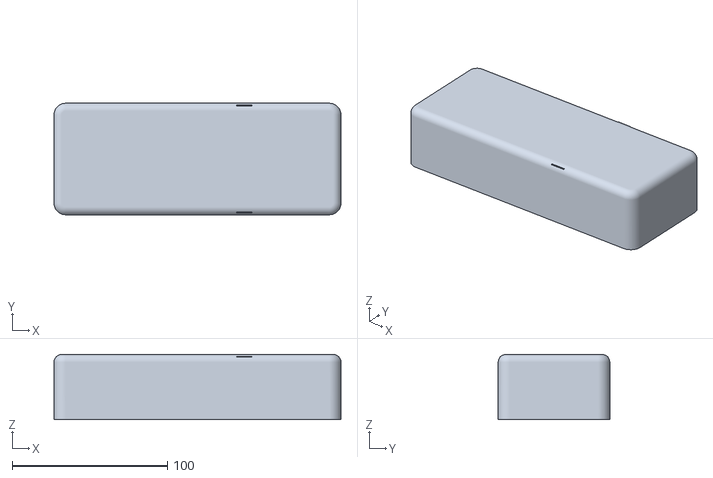
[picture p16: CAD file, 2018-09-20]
Gateway/CAD/Gateway_Mega/Gateway_Mega_Housing_v1.1_top.stl
185.0 x 71.9 x 42.0

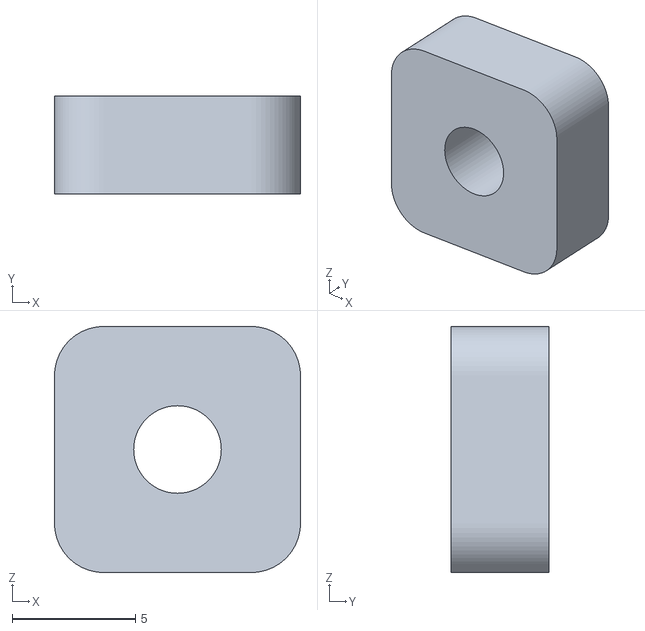
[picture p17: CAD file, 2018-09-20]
Gateway/Gateway_Feather/CAD/Gateway_housing_v7_magnet_holder_top.stl
10.0 x 4.00 x 10.0

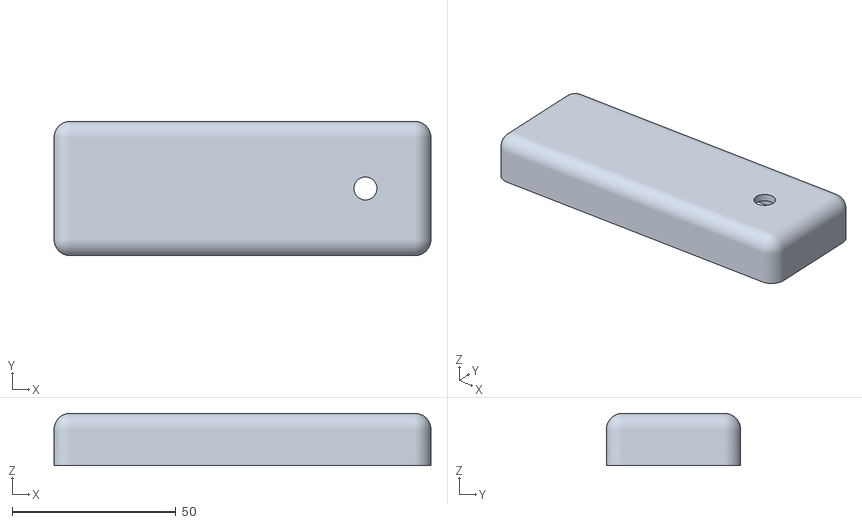
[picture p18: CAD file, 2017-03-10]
Gateway/Gateway_Feather/CAD/Gateway_housing_top_v6.stl
115.0 x 41.0 x 16.0

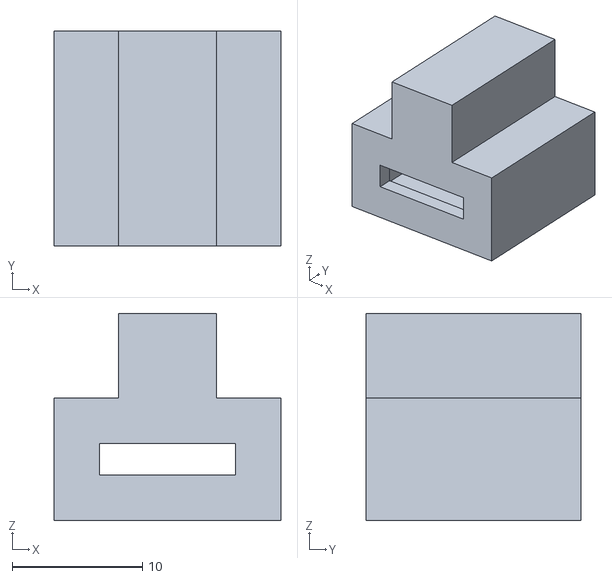
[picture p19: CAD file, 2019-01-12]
Miscellaneous/CAD/Reed_switch_transport_lock_v1.11.stl
17.4 x 16.5 x 15.9

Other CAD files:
Sensor_Node/CAD/sensor_node_housing_v10_top_cable_2v2.stl
Sensor_Node/CAD/sensor_node_housing_v10_top_cable_1.stl
Gateway/Gateway_Feather/CAD/Gateway_housing_bottom_v6.stl
Miscellaneous/CAD/cable_reel_v4.1_bottom.stl
Gateway/CAD/Gateway_Mega/Gateway_Mega_Housing_v1.prt
Gateway/CAD/Gateway_Mega/Gateway_Mega_Housing_v1_bottom.stl
Gateway/CAD/Gateway_Mega/Gateway_Mega_Housing_v1_top.stl
Gateway/Gateway_Feather/CAD/Gateway_housing_v6.prt
Gateway/Gateway_Feather/CAD/Gateway_housing_v7.prt
Gateway/Gateway_Mega/CAD/archive/Gateway_Mega_Housing_v1.prt
Gateway/Gateway_Mega/CAD/archive/Gateway_Mega_Housing_v1_bottom.stl
Gateway/Gateway_Mega/CAD/archive/Gateway_Mega_Housing_v1_top.stl
Gateway/Gateway_Mega/CAD/gateway_mega_housing_v2.prt
Miscellaneous/CAD/Reed_switch_transport_lock_v1.1.stl
Miscellaneous/CAD/Reed_switch_transport_lock_v1.10.stl
Miscellaneous/CAD/Reed_switch_transport_lock_v1.prt
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

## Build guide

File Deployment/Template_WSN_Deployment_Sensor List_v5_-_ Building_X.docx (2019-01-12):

WSN Deployment – Sensor List

Building Nr.

Date
Arrival time
Start house tour
Start installation
Finish installation
Departure time

Electricity meter reading
Electricity meter reading
Electricity meter reading
Electricity meter reading
Gas meter reading
Oil meter reading

Node ID | Type | Location

Comments

Check list

- Note arrival time
- Introduction to measurements with building owner
- Plug in gateway
- Sign data privacy statement
- Note house tour time
- Note start installation time
- Read Electricity Meter
- Read Gas Meter
- Read Oil Meter
- Check sensor data online (online status, sensor module type, validity of values)
- Note finish installation time
- Note Departure time

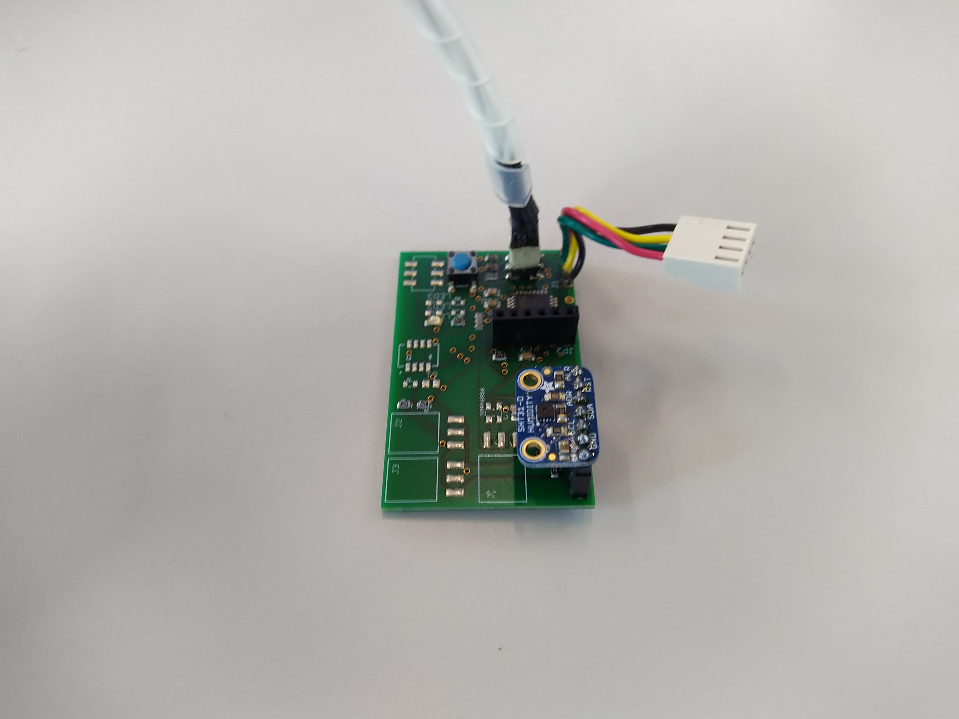
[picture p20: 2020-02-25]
Miscellaneous/Images/instructions/sensor_module_with_isp_programmer.jpg

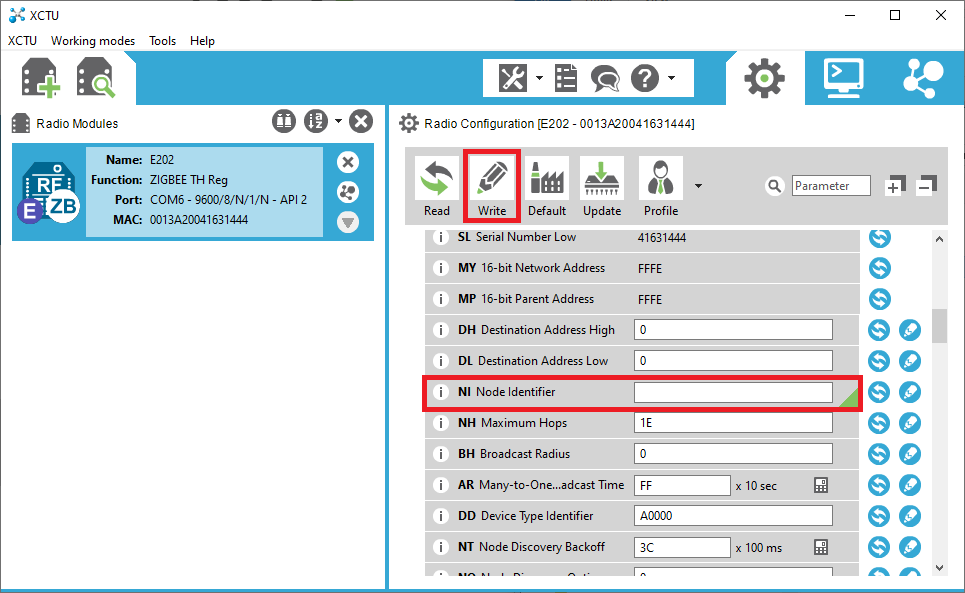
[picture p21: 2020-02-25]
Miscellaneous/Images/instructions/screenshot_x-ctu_add_node_identifier.png

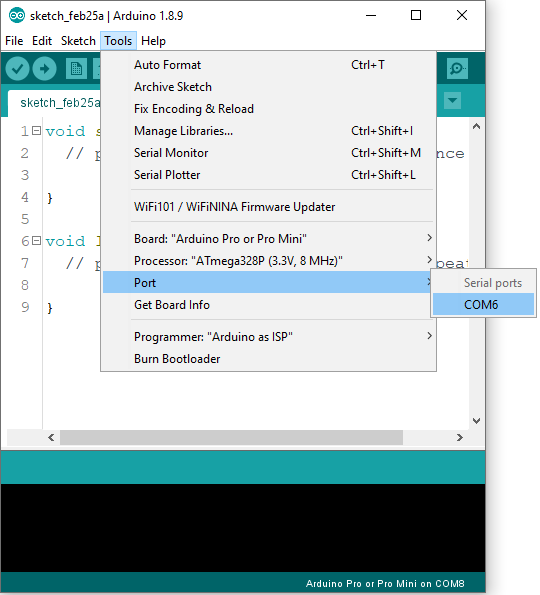
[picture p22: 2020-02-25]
Miscellaneous/Images/instructions/arduino_ide_select_port_arduino_pro_mini.png

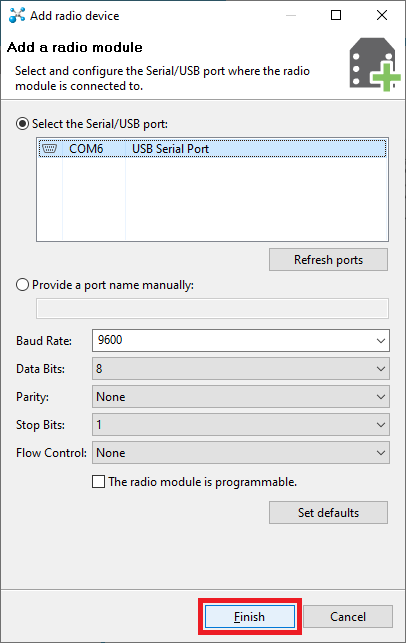
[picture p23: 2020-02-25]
Miscellaneous/Images/instructions/screenshot_x-ctu_add_radio_module.png

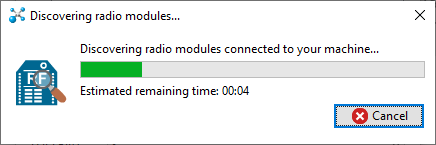
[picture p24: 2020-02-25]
Miscellaneous/Images/instructions/screenshot_x-ctu_add_radio_module_waiting.png

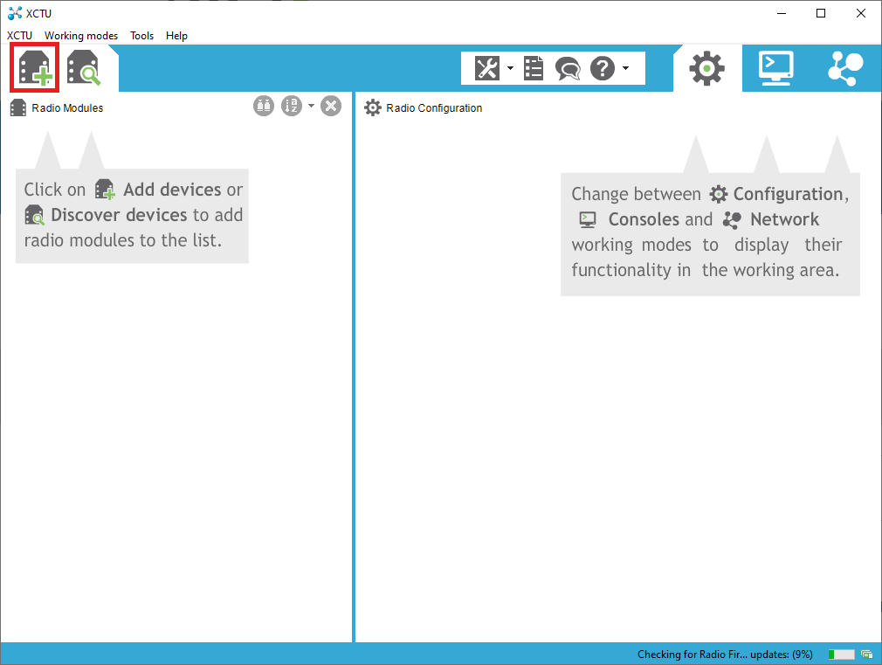
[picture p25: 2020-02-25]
Miscellaneous/Images/instructions/screenshot_x-ctu_start.png

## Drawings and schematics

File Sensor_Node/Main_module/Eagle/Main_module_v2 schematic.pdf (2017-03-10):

A

1 | 2 | 3 | 4 | 5 | 6 | 7 | 8

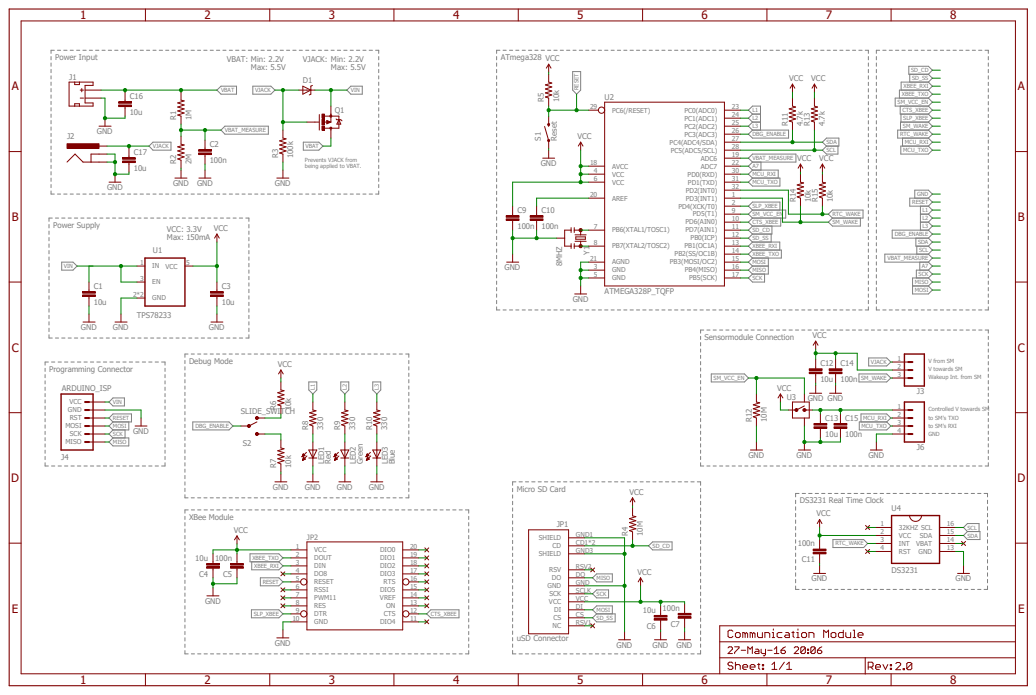
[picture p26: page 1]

VBAT_MEASURE
GND GND ¹⁰⁰k
Prevents VJACK from
being applied to VBAT.

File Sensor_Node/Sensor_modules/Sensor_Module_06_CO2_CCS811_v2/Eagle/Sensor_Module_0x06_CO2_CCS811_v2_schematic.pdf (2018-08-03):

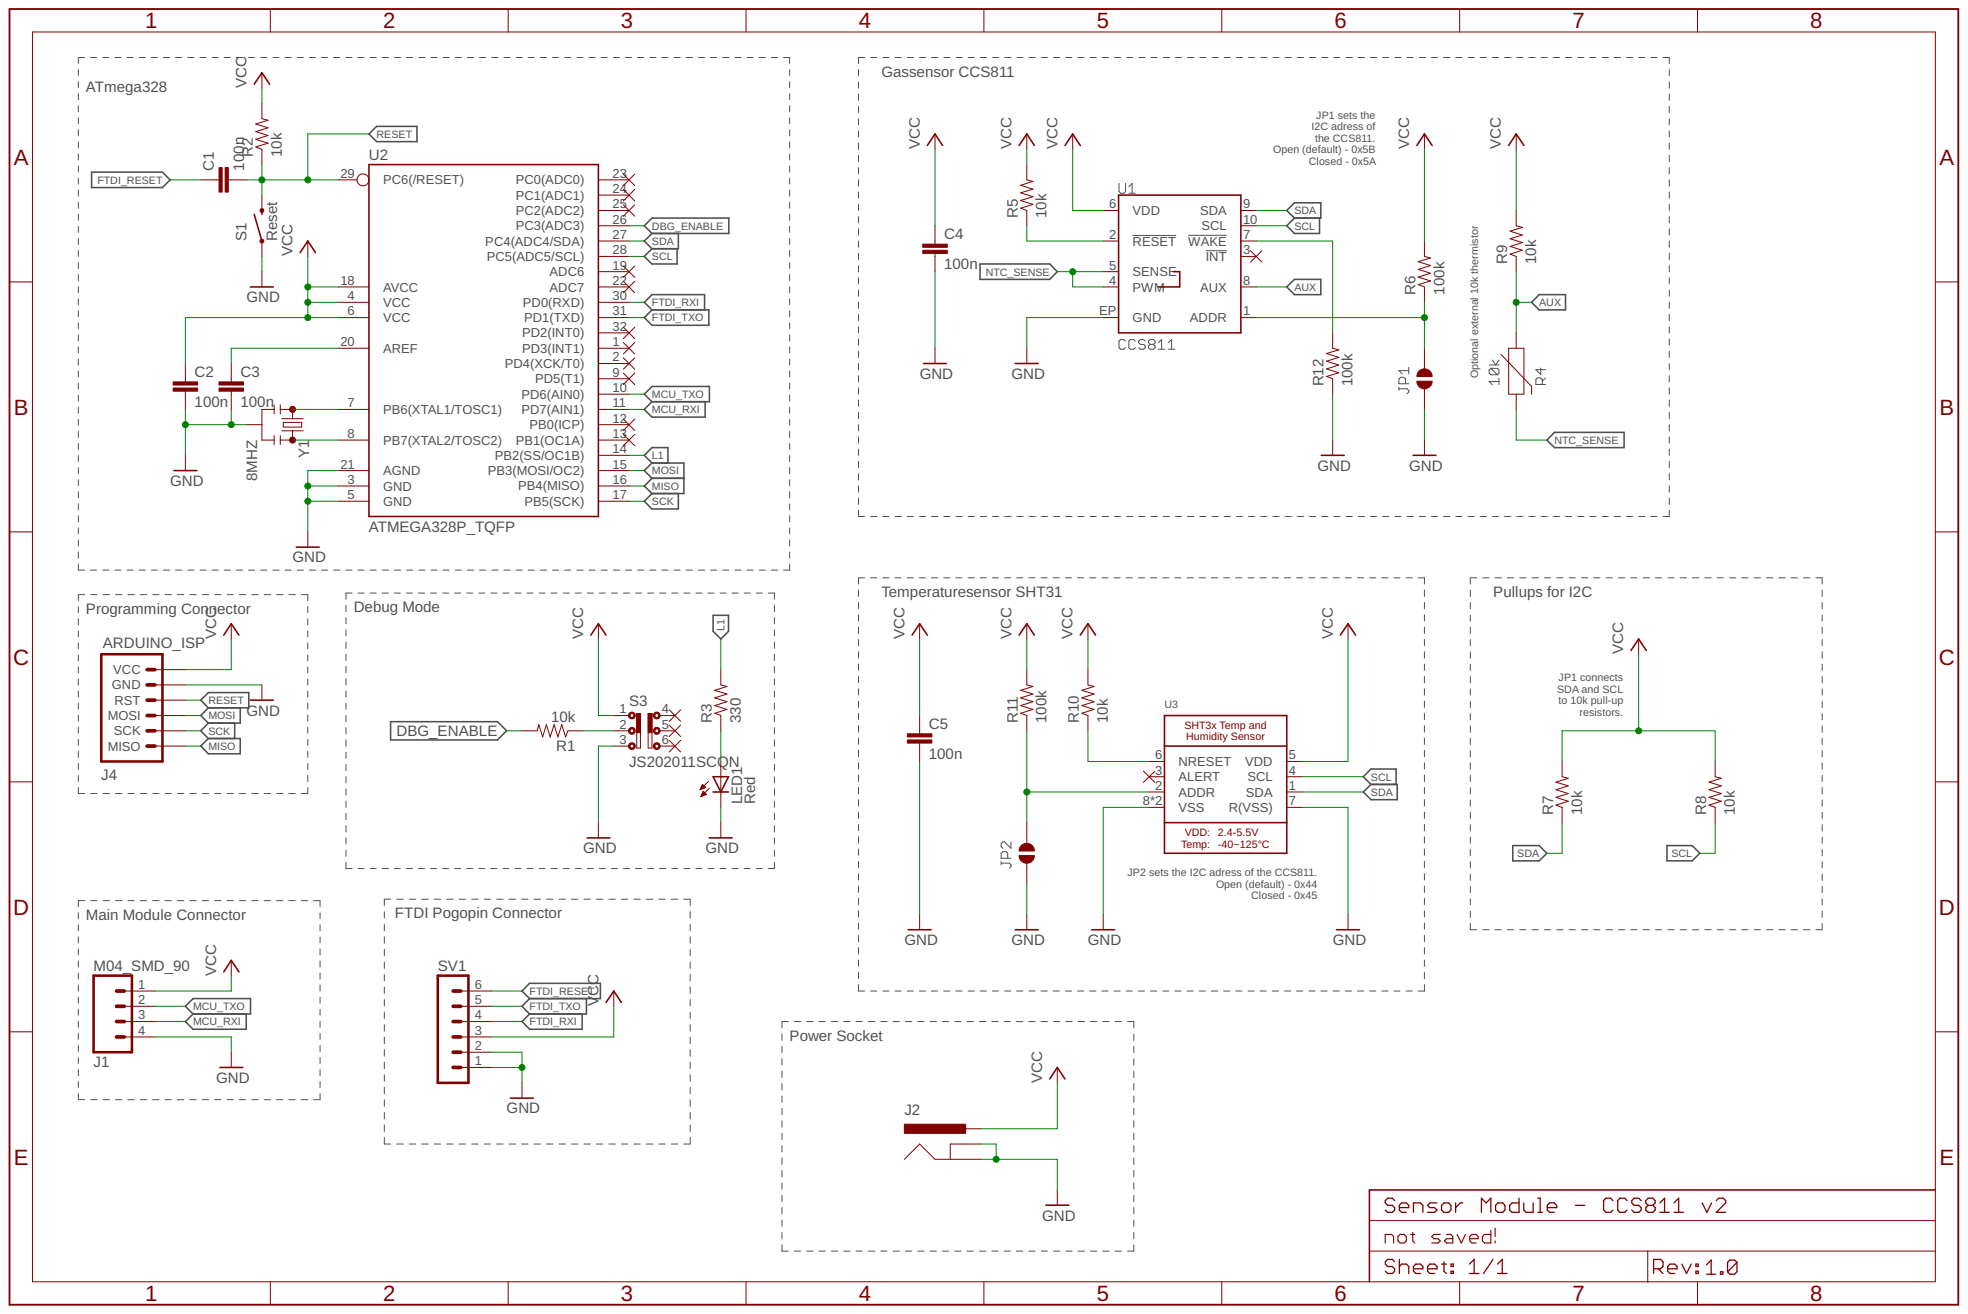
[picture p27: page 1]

the CCS811. Open (default) - 0x5B Closed - 0x5A

100k VCC GND GND GND

VCC
SCK MOSI RST GND

JP1 connects SDA and SCL

SHT3x Temp and Humidity Sensor

JP2 sets the I2C adress of the CCS811. Open (default) - 0x44 Closed - 0x45

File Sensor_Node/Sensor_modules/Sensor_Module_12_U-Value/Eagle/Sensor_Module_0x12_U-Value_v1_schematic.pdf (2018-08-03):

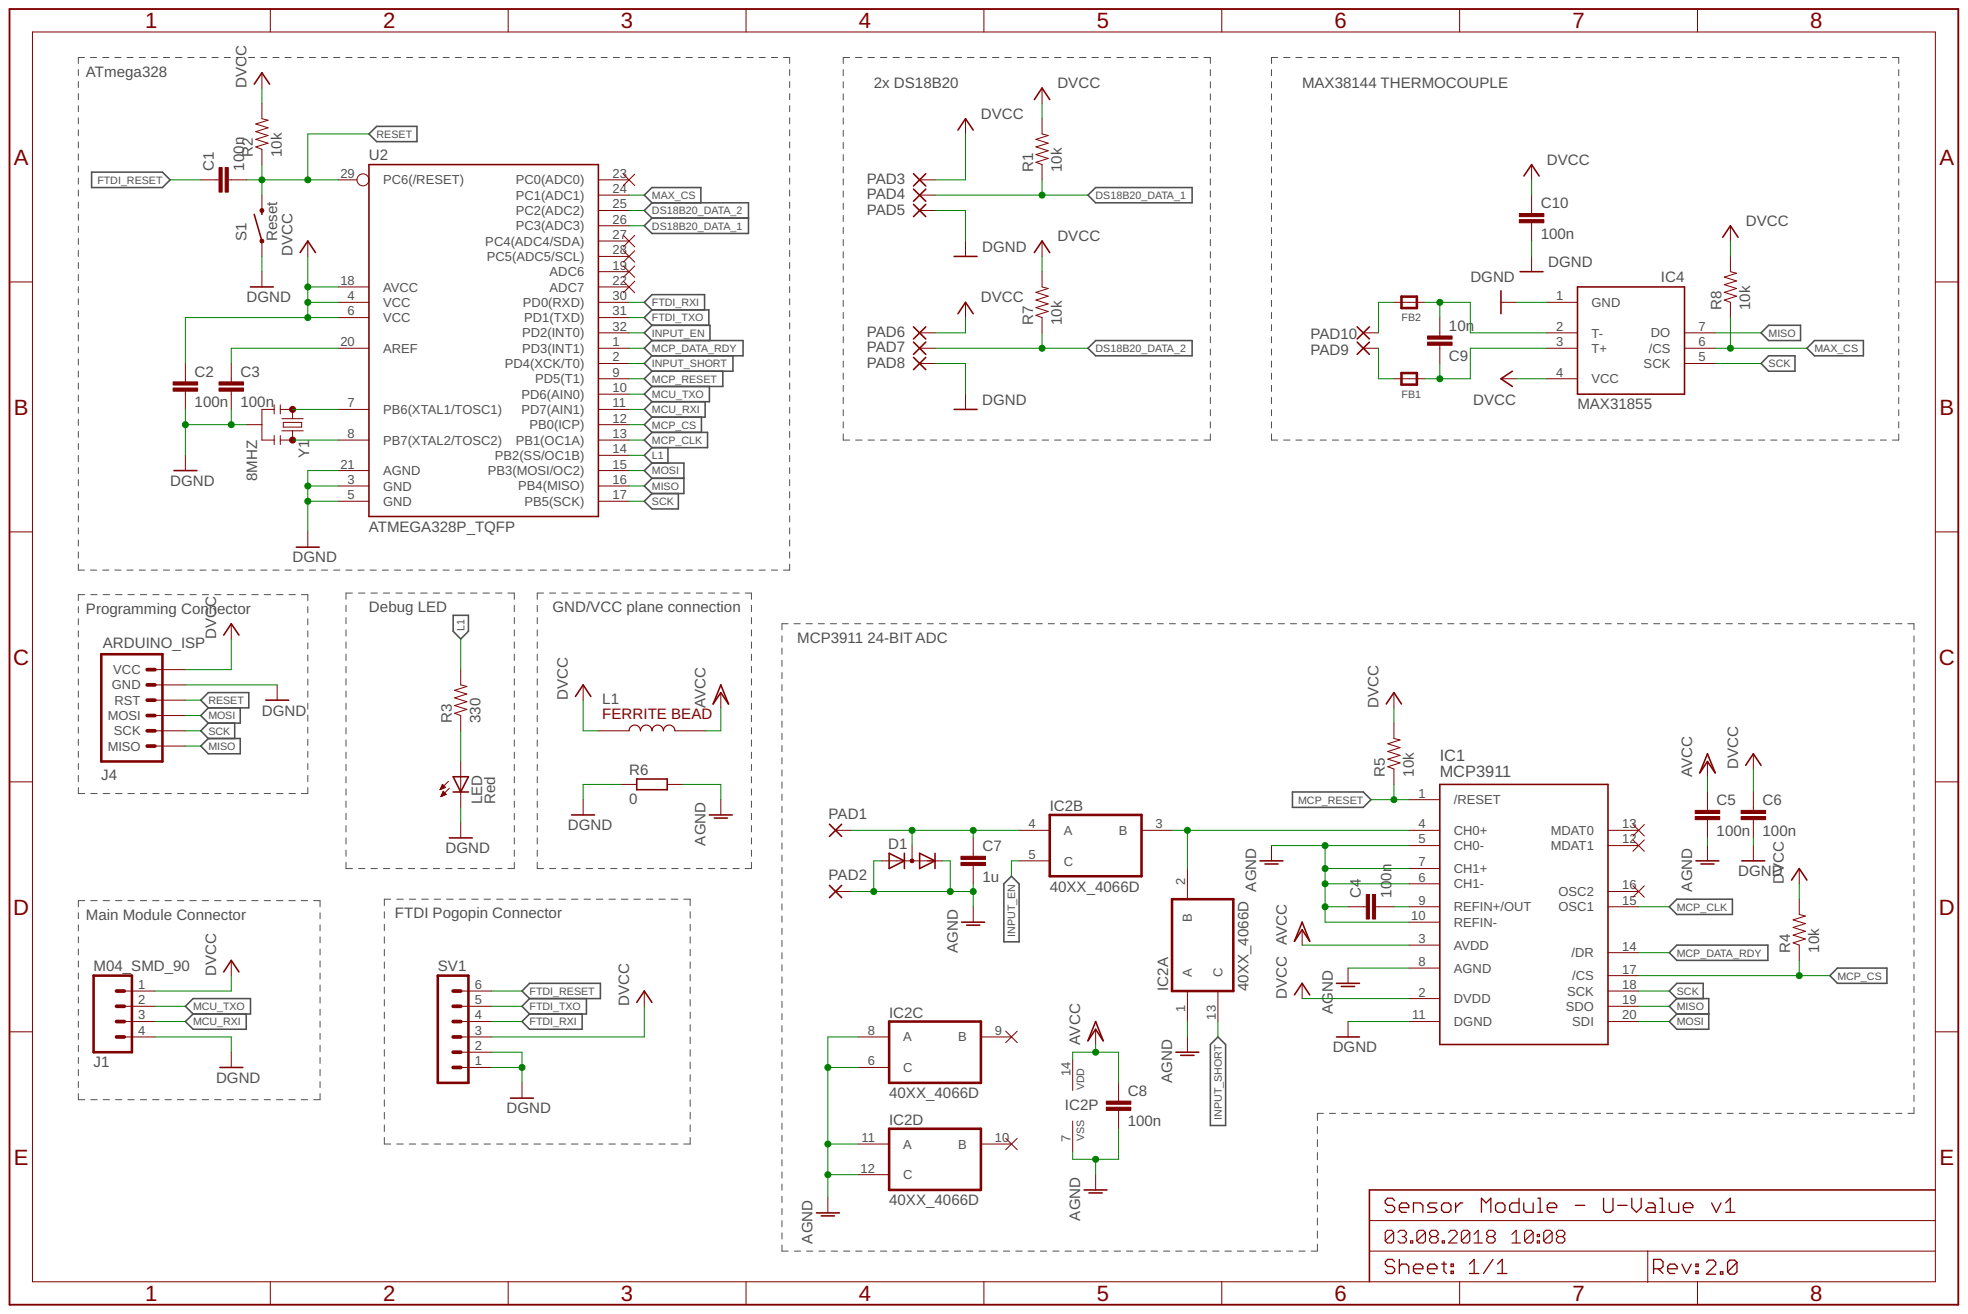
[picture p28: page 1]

VCC
SCK MOSI RST GND

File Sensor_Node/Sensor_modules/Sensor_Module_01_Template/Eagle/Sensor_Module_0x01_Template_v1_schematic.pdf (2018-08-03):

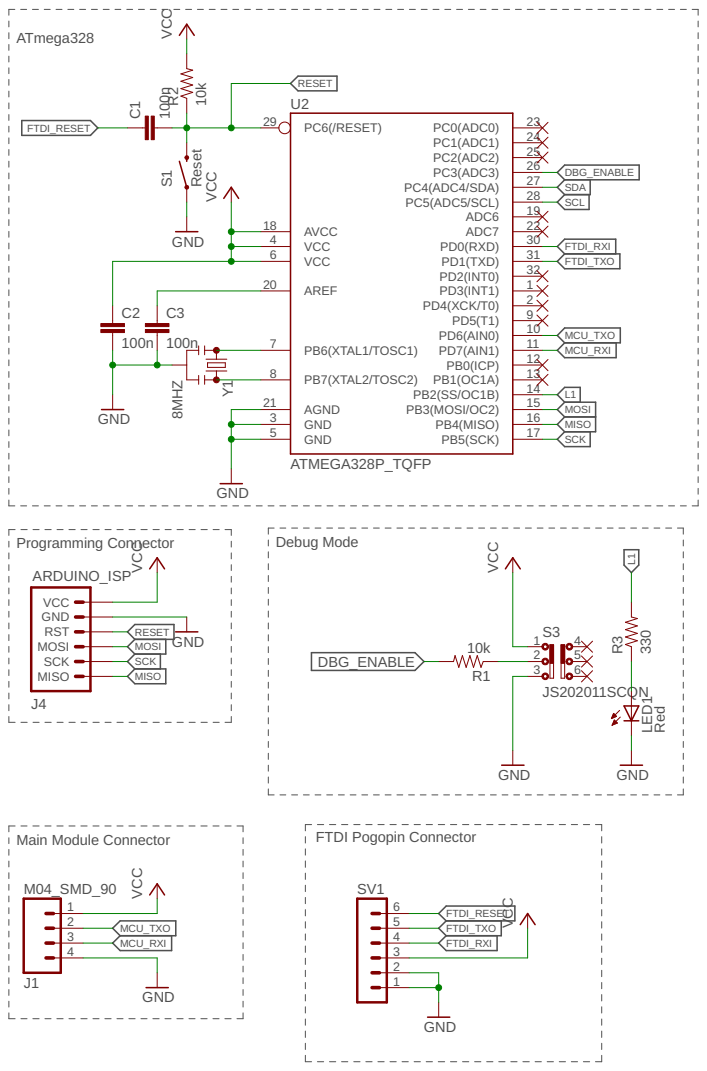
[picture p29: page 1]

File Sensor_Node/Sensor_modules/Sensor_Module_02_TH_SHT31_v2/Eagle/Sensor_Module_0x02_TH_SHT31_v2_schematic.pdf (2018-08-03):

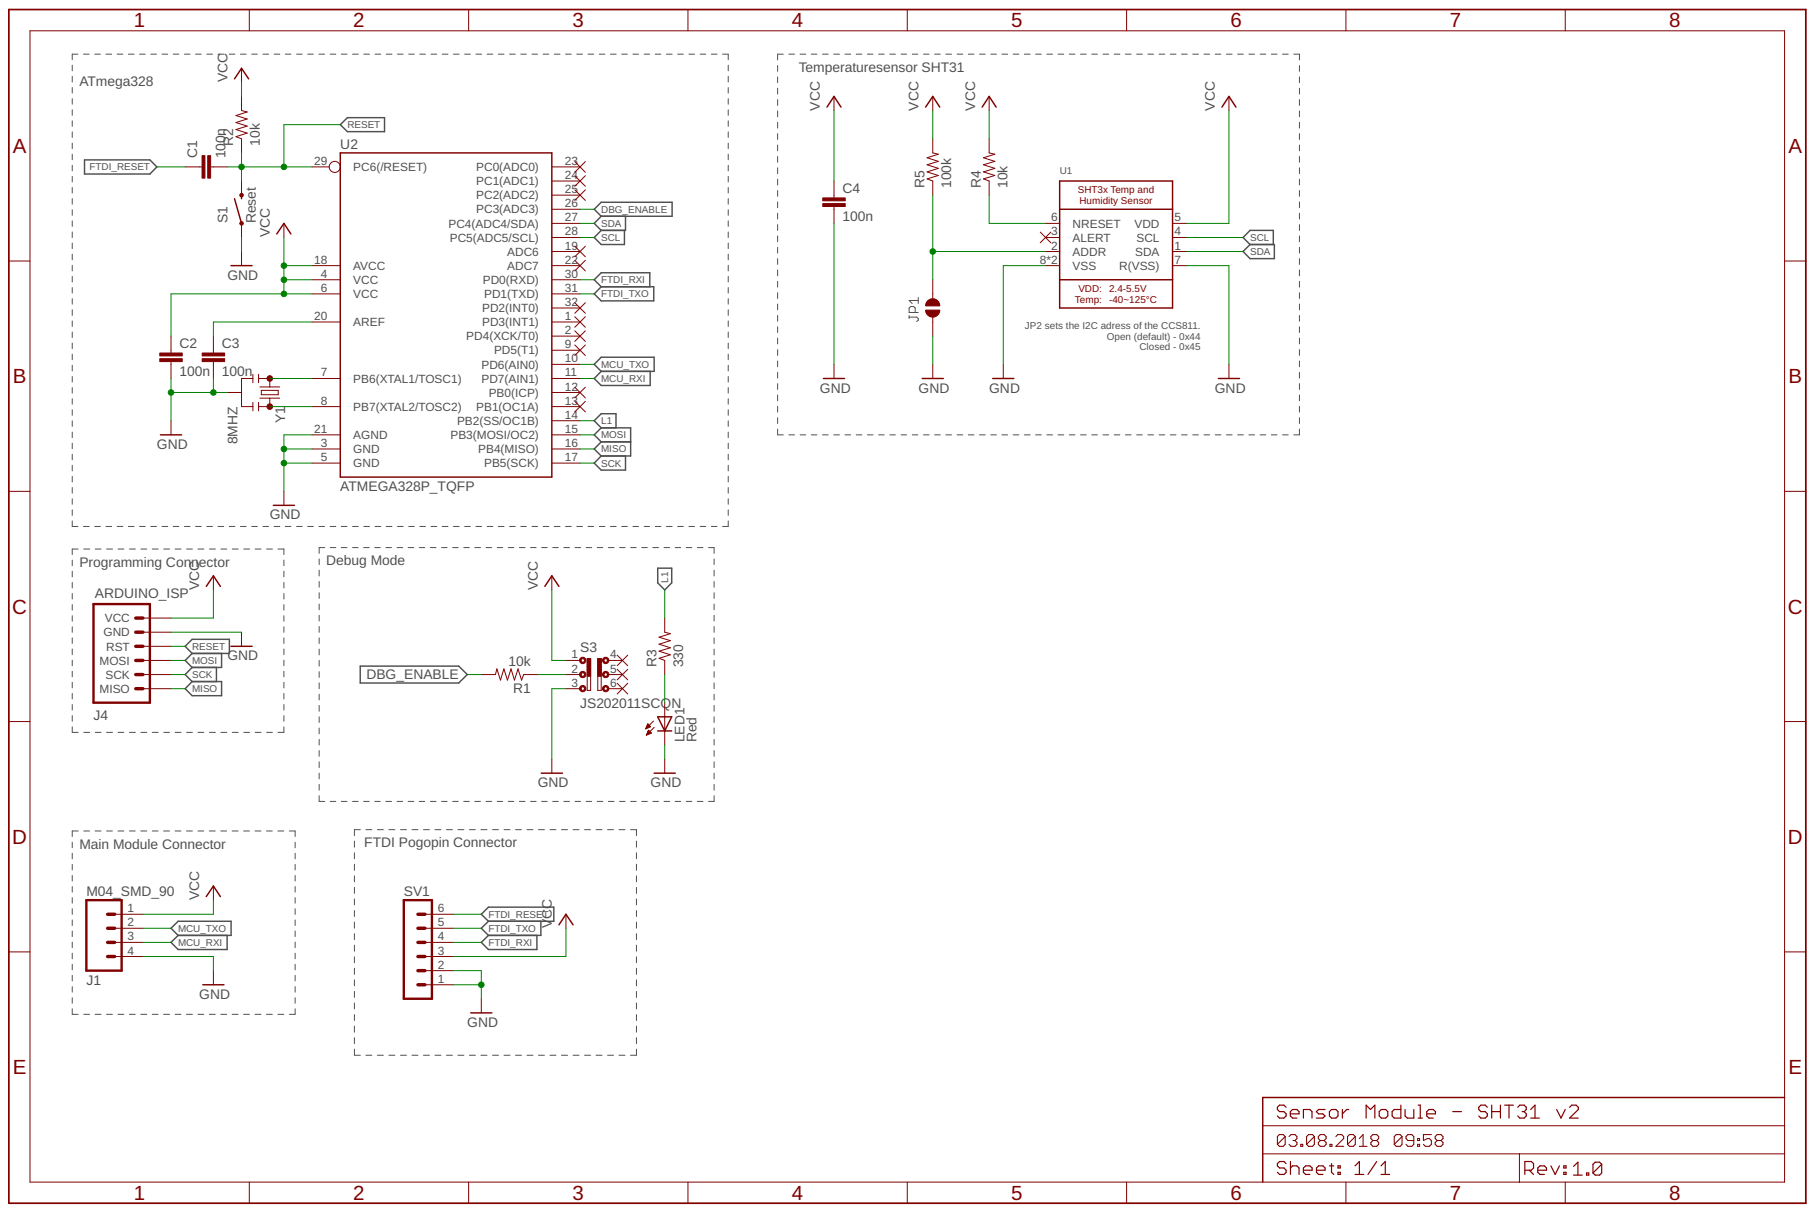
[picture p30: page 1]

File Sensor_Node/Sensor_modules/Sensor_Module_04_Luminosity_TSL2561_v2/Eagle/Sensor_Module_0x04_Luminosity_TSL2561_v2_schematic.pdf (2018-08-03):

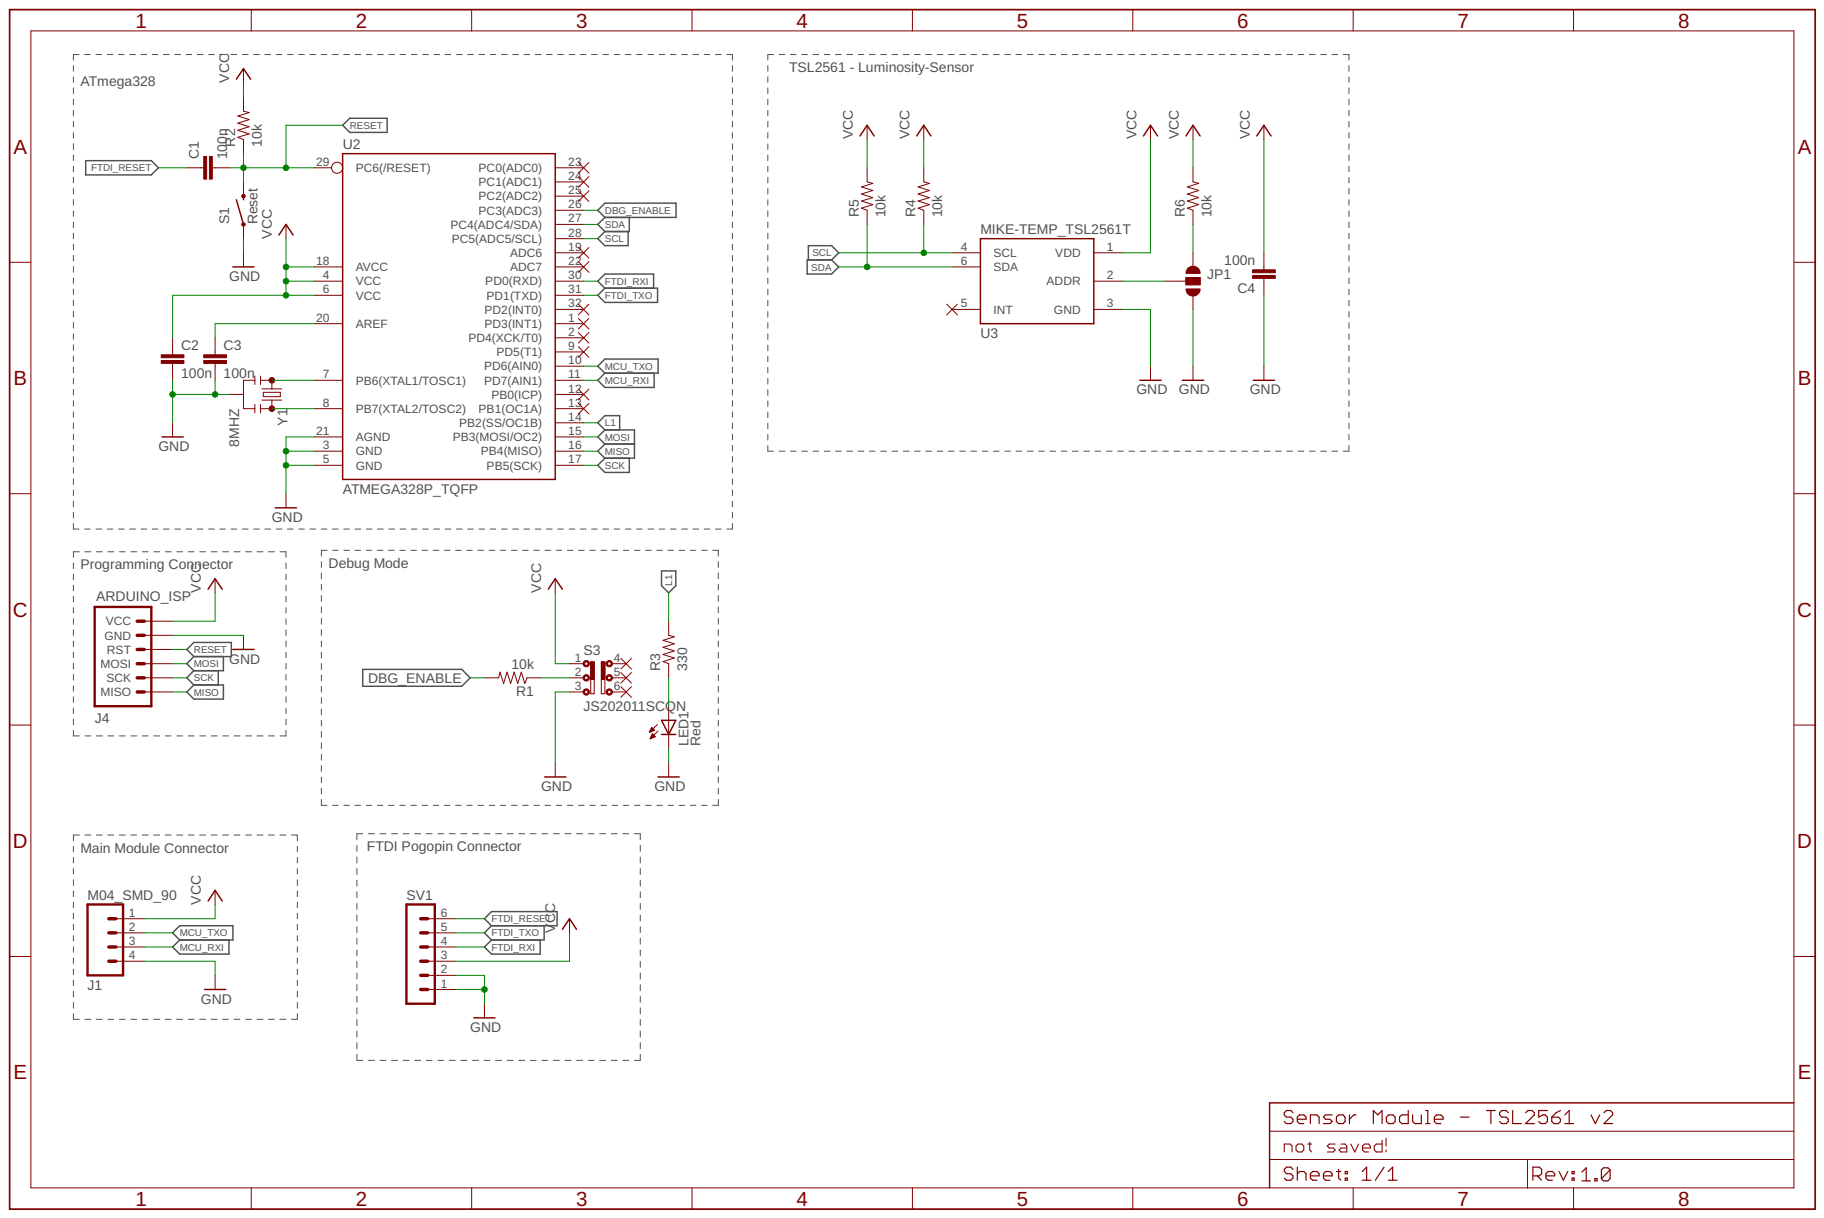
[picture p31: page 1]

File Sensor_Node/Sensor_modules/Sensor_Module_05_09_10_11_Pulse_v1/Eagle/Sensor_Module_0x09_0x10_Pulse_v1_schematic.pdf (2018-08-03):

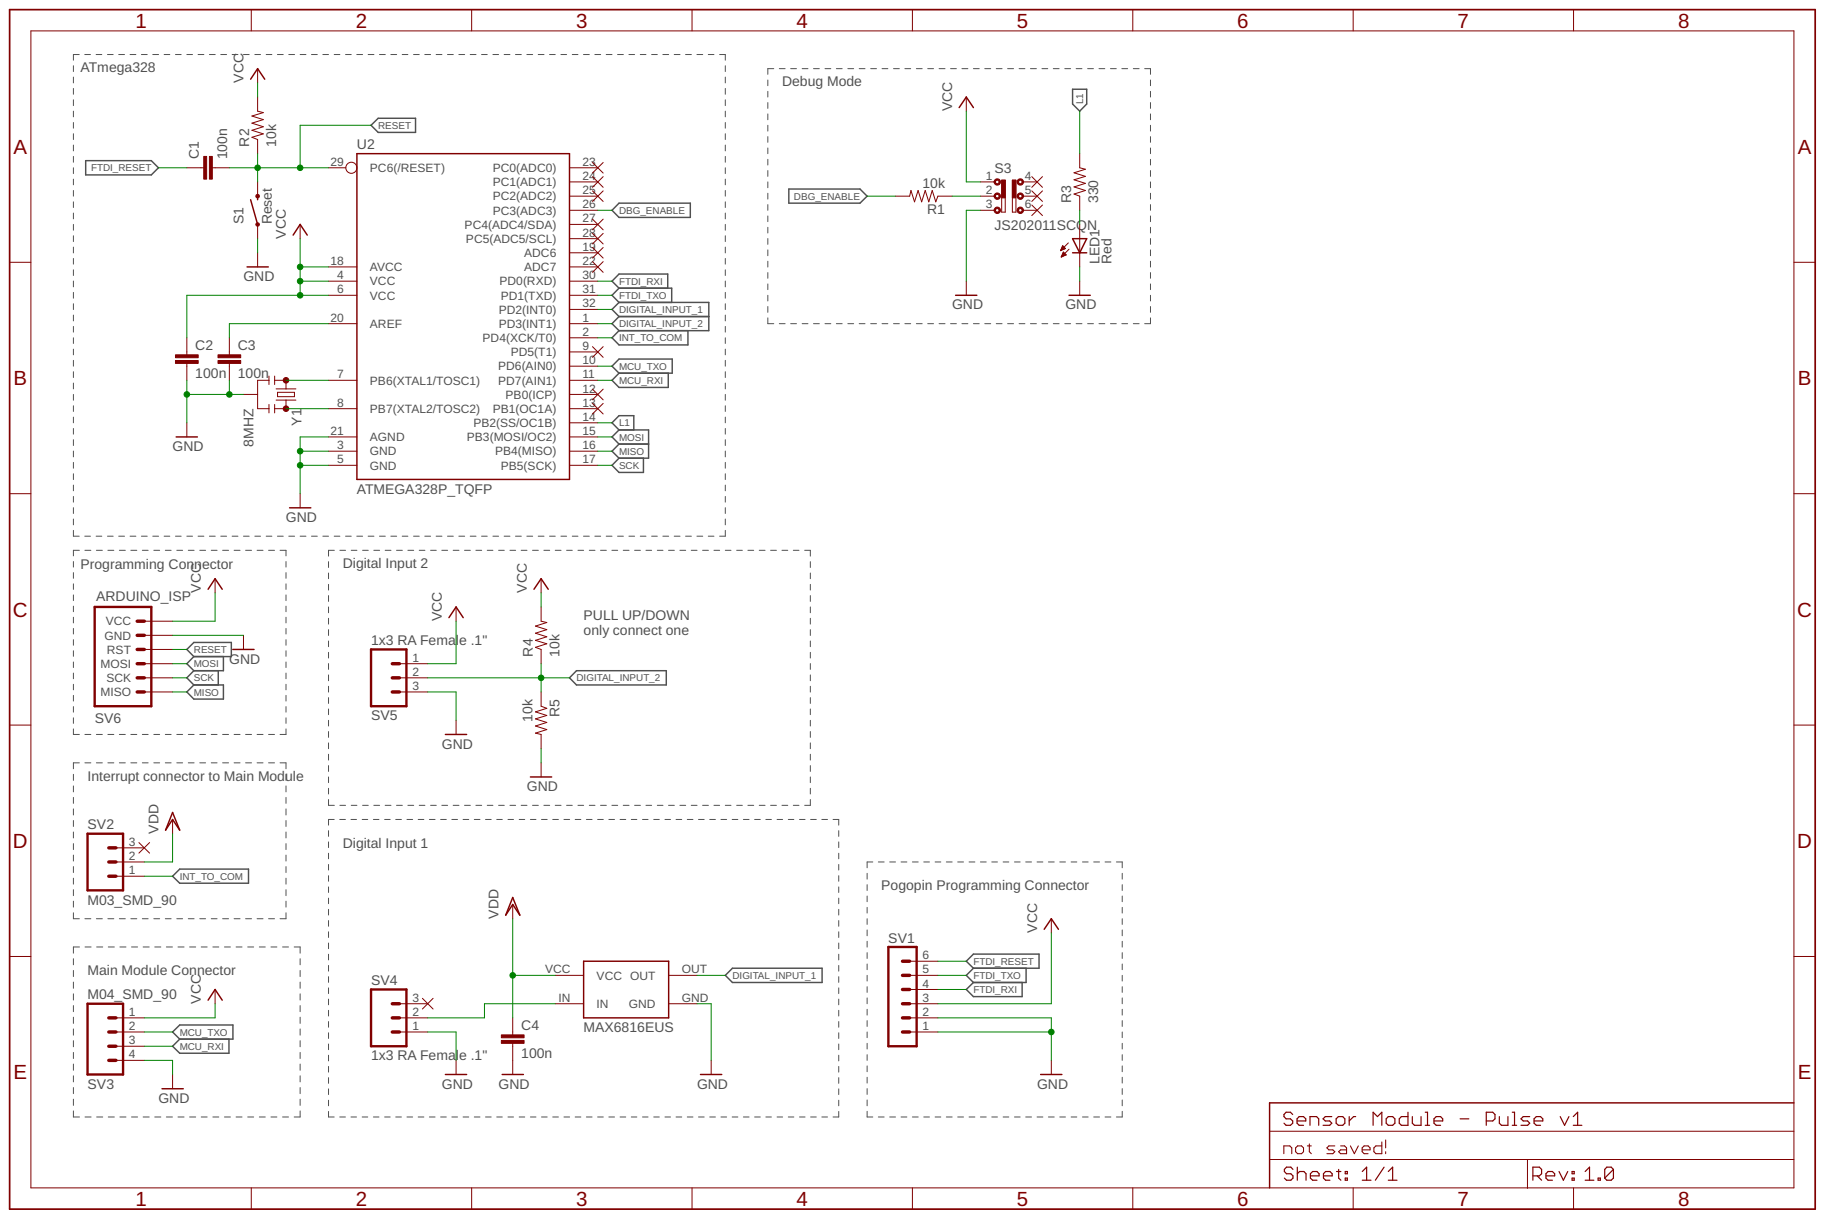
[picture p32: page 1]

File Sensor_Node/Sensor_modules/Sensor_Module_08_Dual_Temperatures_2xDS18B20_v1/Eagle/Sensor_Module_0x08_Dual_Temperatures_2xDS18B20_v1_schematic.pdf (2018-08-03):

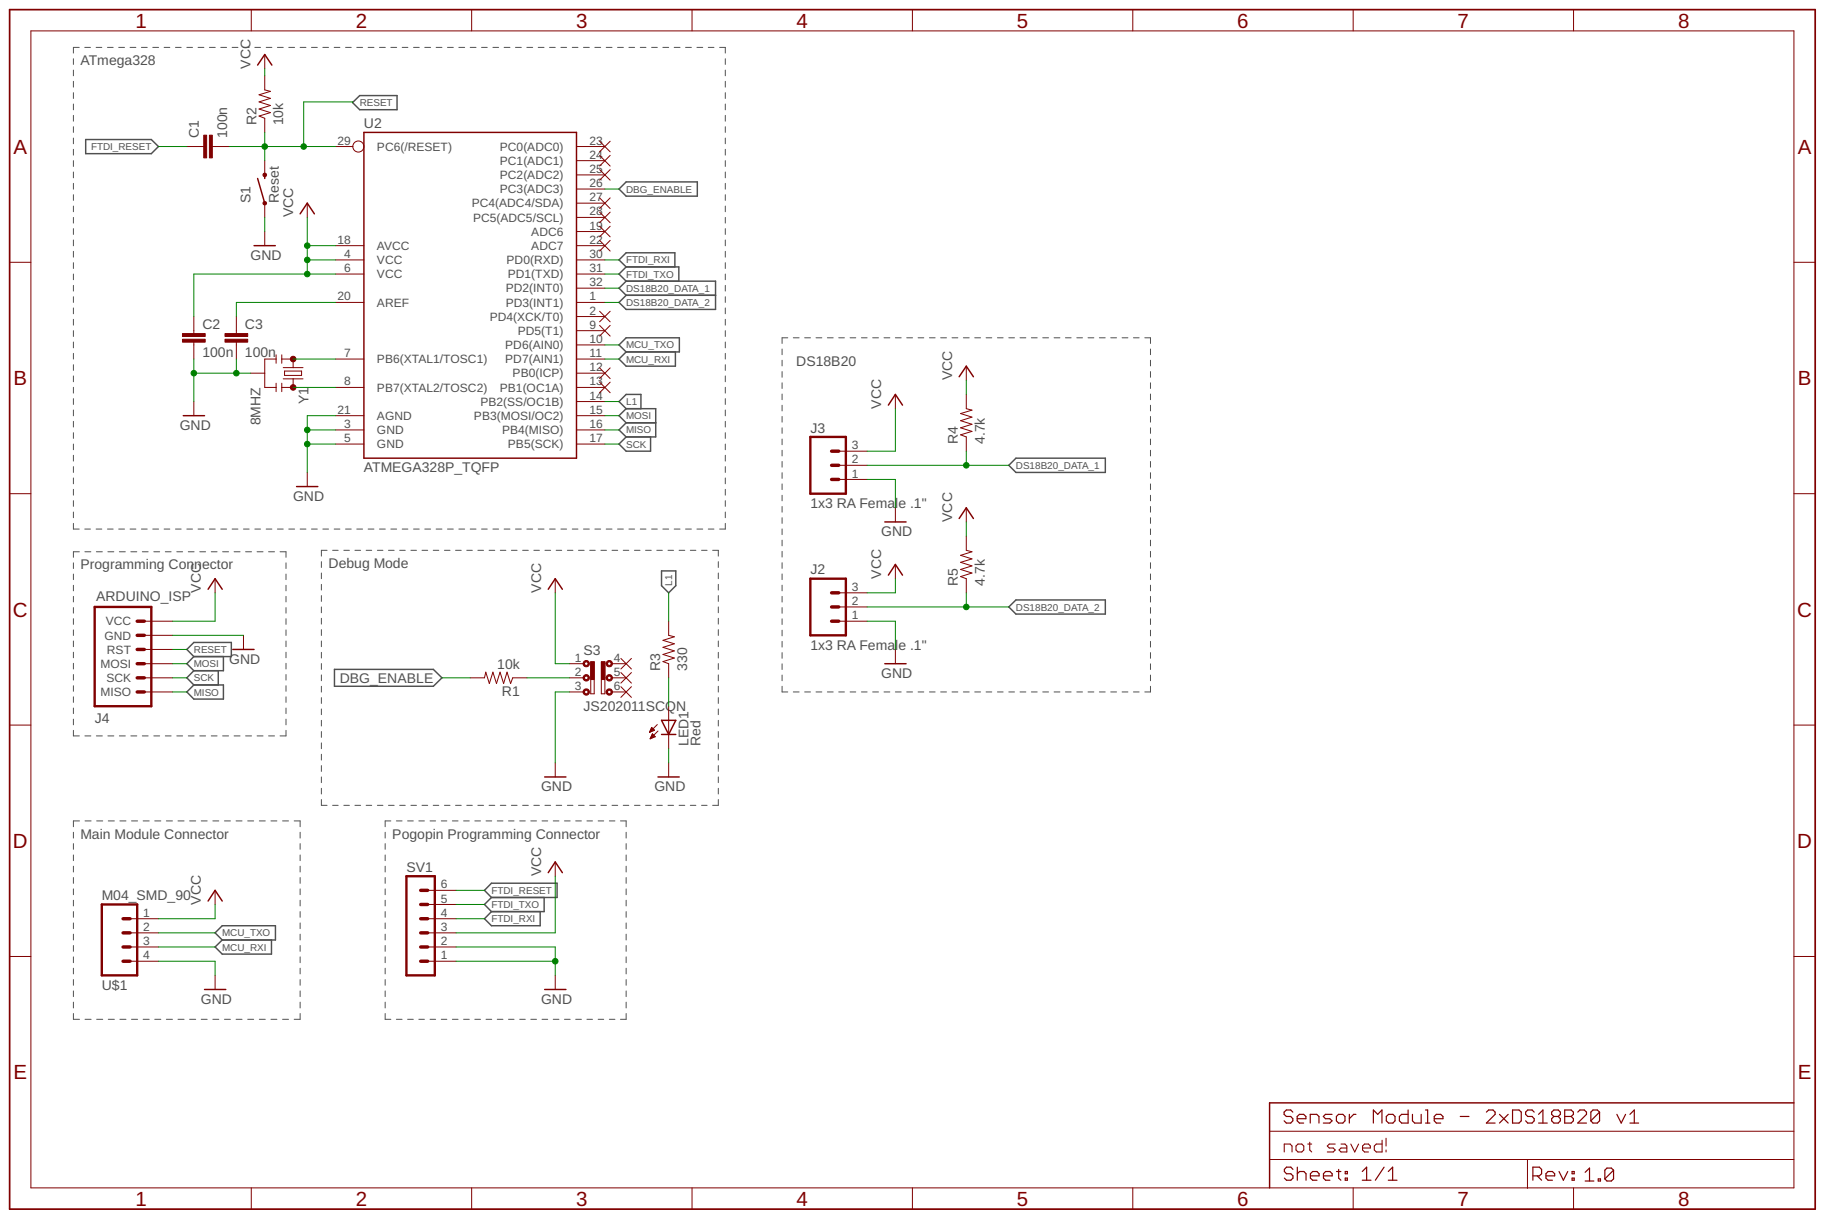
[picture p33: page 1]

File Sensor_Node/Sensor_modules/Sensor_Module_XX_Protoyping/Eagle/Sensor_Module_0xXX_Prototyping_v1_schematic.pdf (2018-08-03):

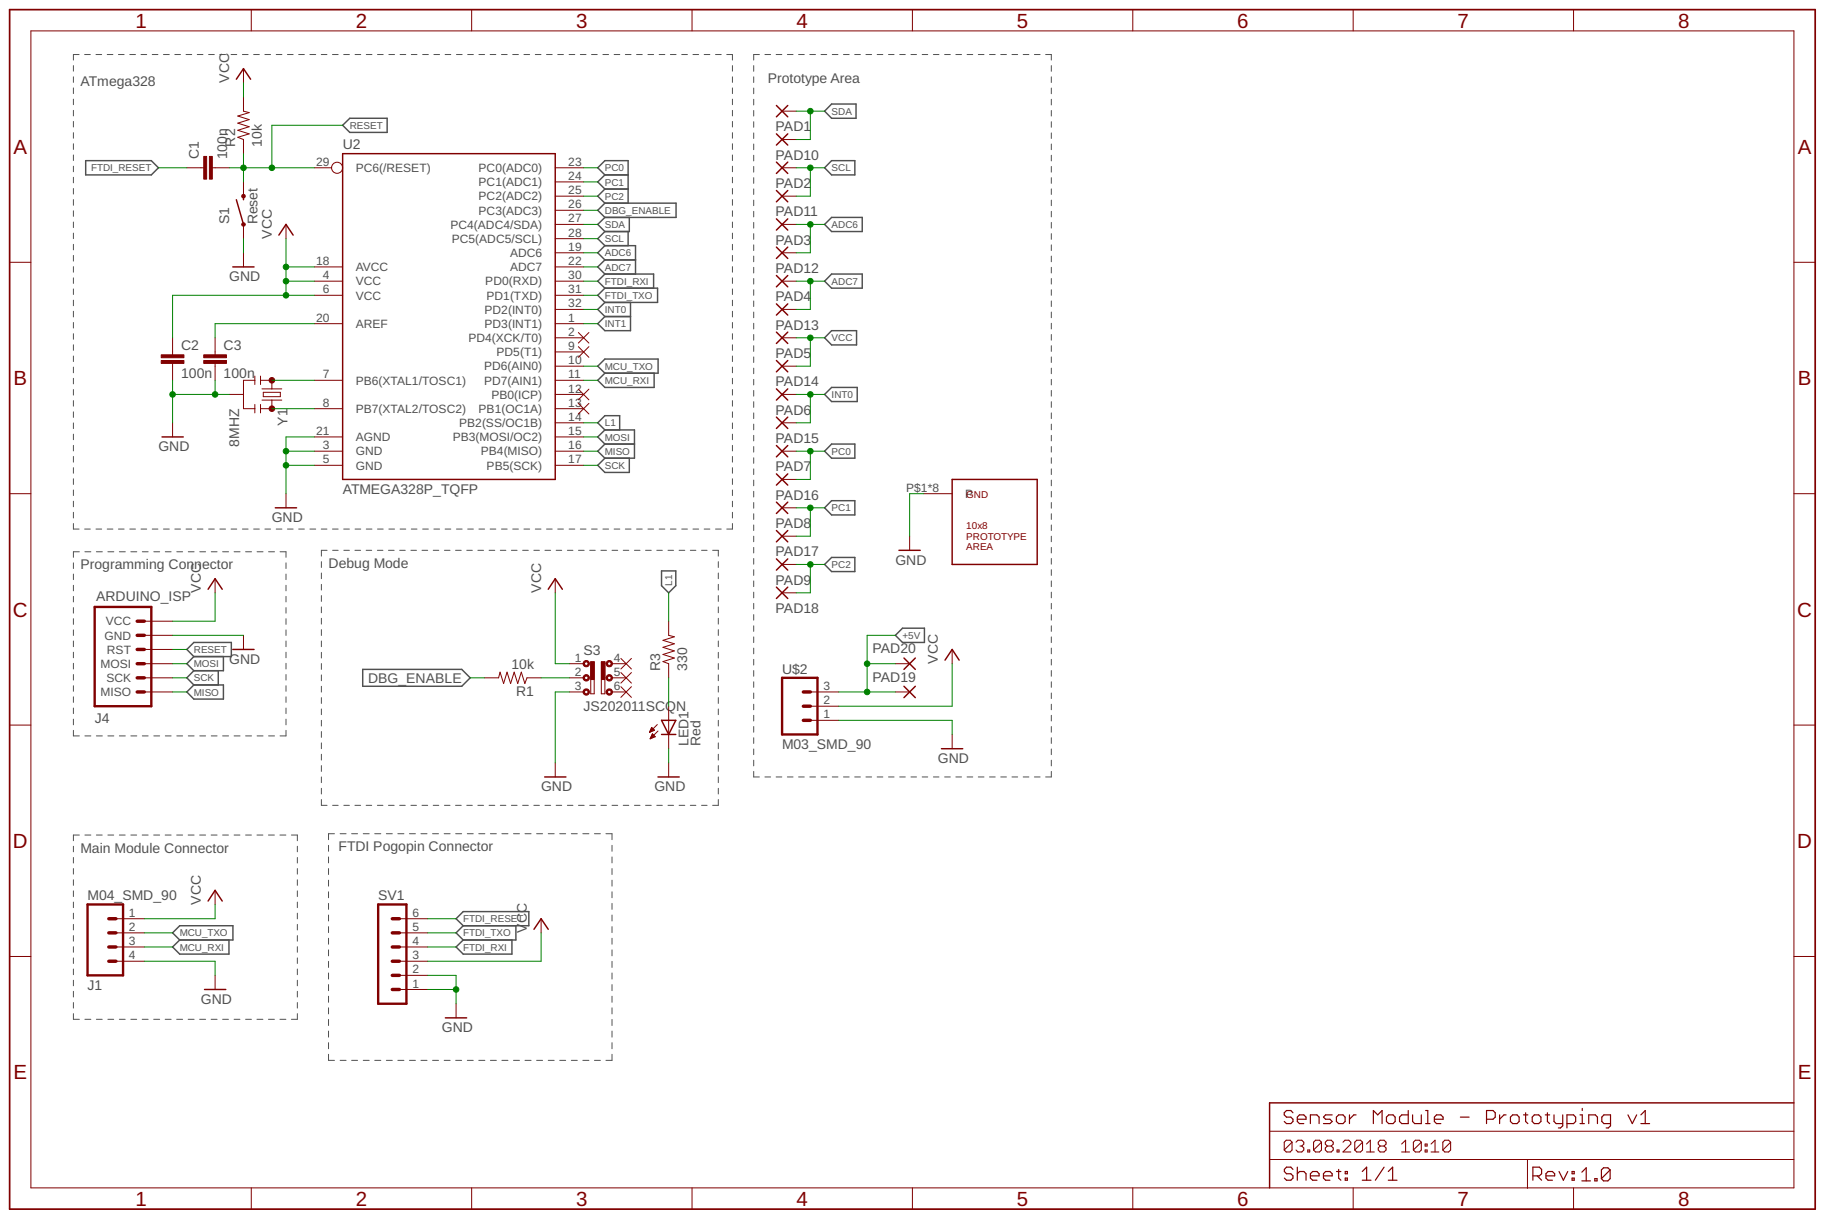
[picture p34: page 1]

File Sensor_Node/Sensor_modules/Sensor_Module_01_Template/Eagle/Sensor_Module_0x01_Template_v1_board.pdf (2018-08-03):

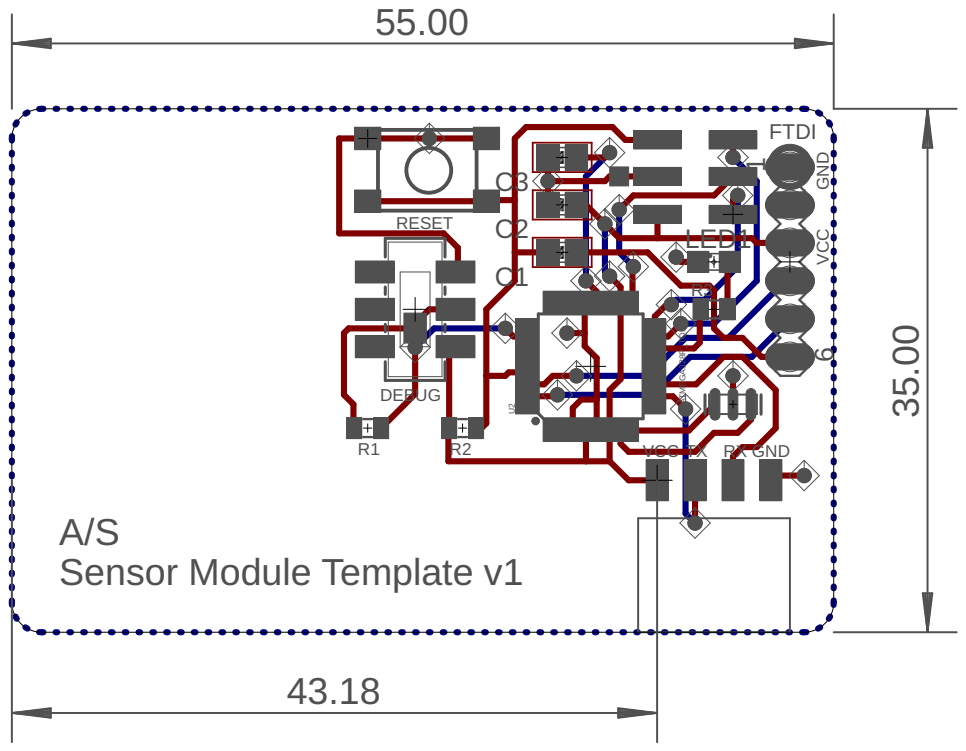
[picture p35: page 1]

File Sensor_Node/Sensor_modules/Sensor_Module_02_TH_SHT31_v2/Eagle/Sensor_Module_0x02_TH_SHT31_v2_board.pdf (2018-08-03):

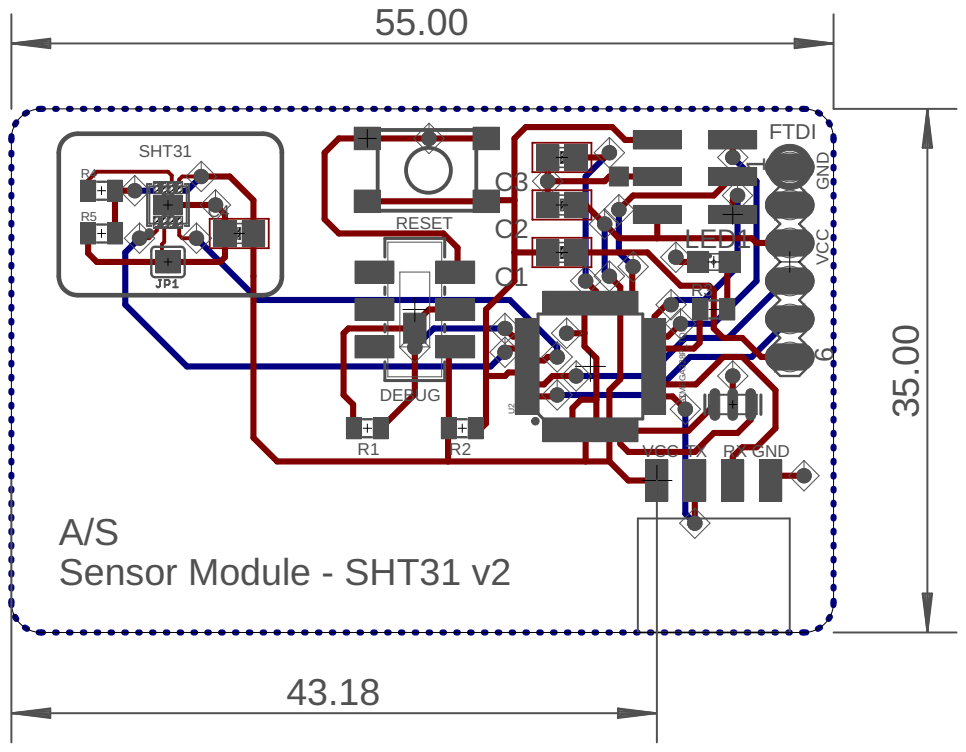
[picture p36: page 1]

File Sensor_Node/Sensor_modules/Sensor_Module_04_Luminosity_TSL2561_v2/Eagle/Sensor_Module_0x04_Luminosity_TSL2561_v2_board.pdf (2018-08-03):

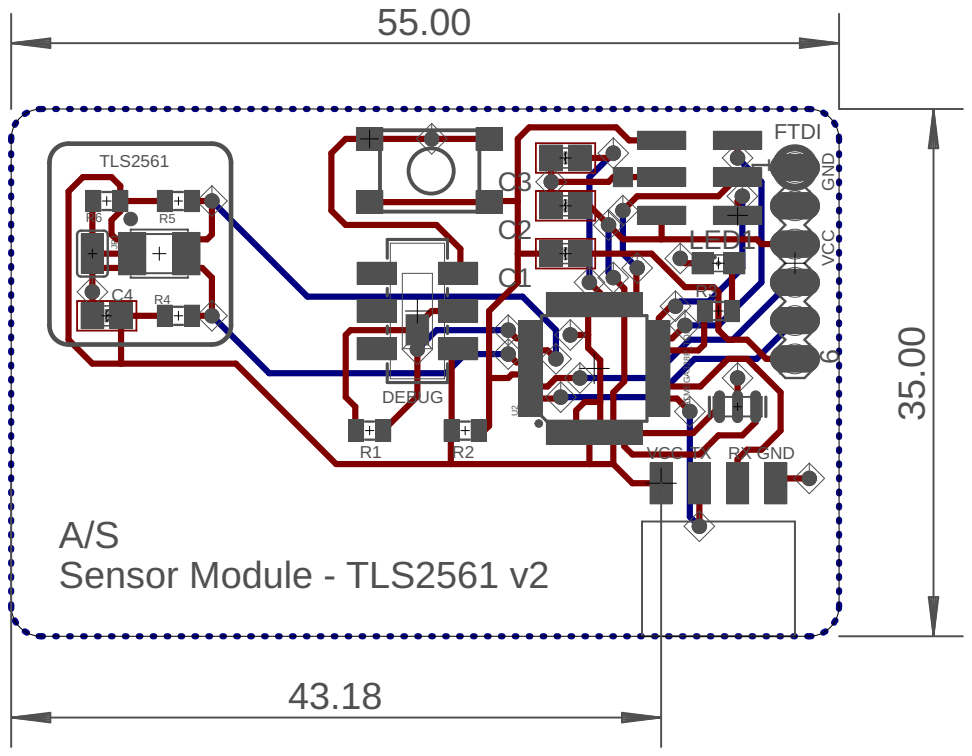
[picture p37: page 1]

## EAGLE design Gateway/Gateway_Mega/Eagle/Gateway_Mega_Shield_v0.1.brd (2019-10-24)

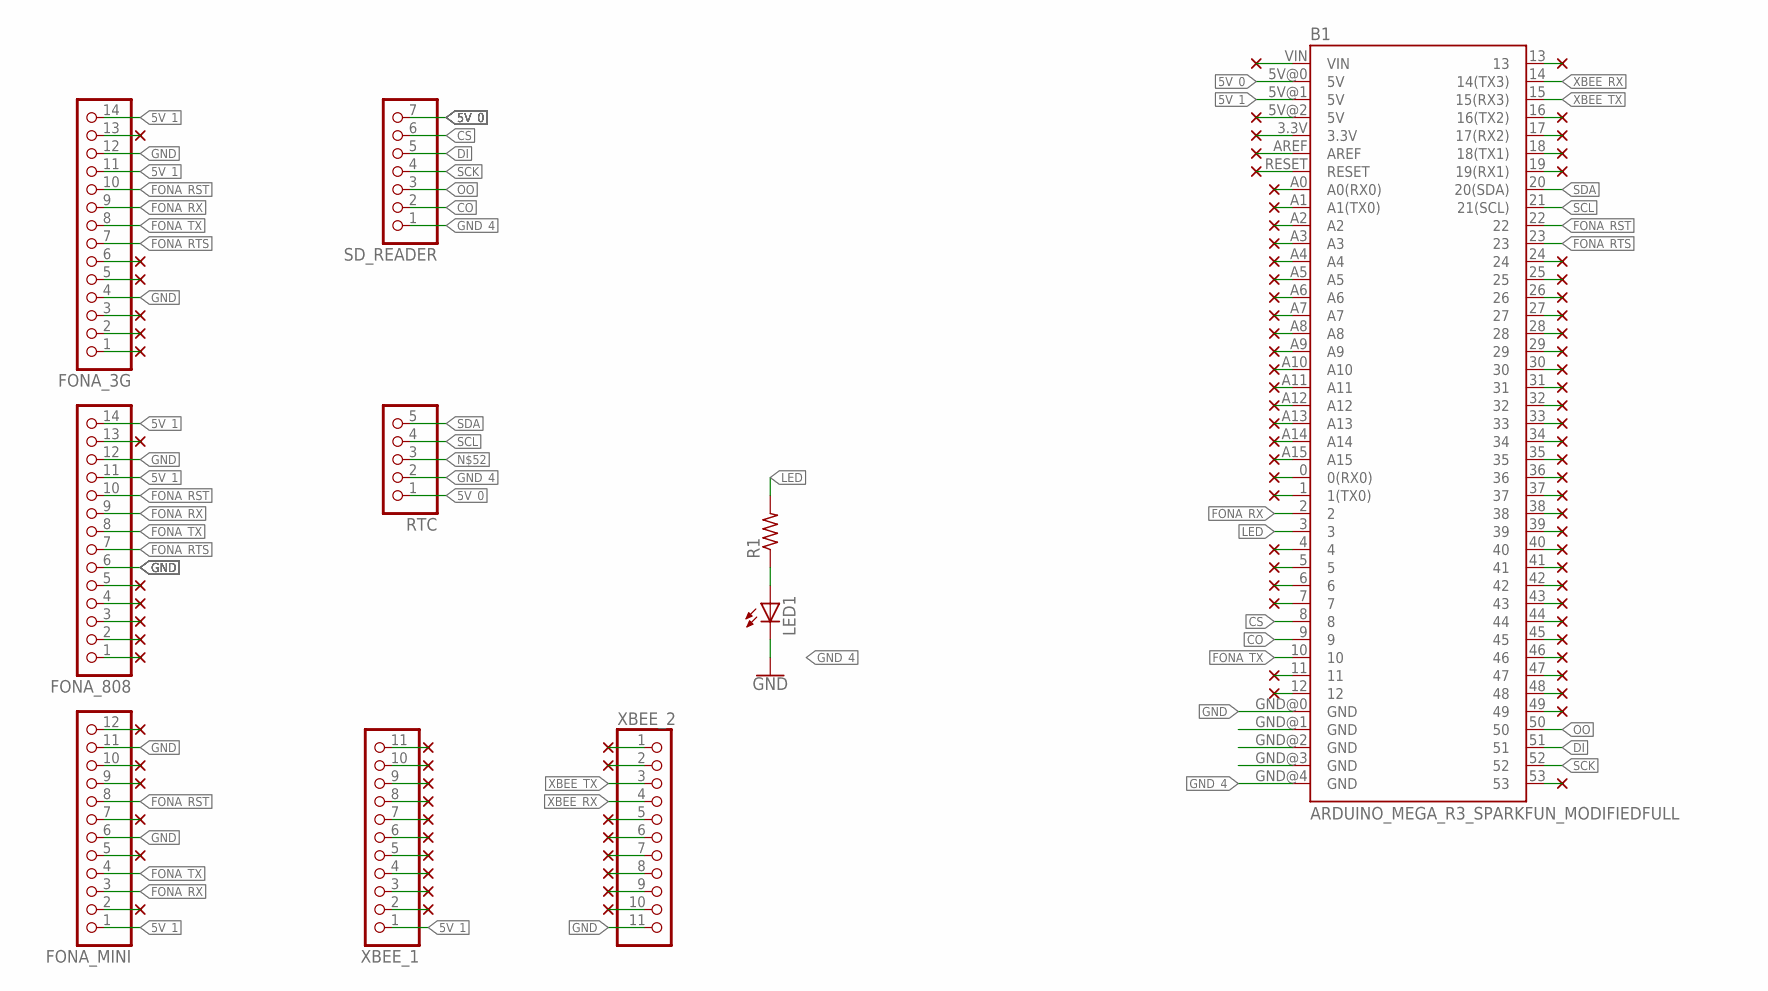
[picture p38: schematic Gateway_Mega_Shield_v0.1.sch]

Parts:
B1: ARDUINO_MEGA_R3_SPARKFUN_MODIFIEDFULL; ARDUINO_MEGA_SPARKFUN_MODIFIED
FONA_3G, FONA_808: PINHD-1X14; 1X14
FONA_MINI: PINHD-1X12; 1X12
LED1: LED5MM
R1: R-US_0207/10; 0207/10
RTC: PINHD-1X5; 1X05
SD_READER: PINHD-1X7; 1X07
XBEE_1, XBEE_2: PINHD-1X11; 1X11

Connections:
5V_0: B1.5V@0 (5V), RTC.1, SD_READER.7
5V_1: B1.5V@1 (5V), FONA_3G.11, FONA_3G.14, FONA_808.11, FONA_808.14, FONA_MINI.1, XBEE_1.1
CO: B1.9, SD_READER.2
CS: B1.8, SD_READER.6
DI: B1.51, SD_READER.5
FONA_RST: B1.22, FONA_3G.10, FONA_808.10, FONA_MINI.8
FONA_RTS: B1.23, FONA_3G.7, FONA_808.7
FONA_RX: B1.2, FONA_3G.9, FONA_808.9, FONA_MINI.3
FONA_TX: B1.10, FONA_3G.8, FONA_808.8, FONA_MINI.4
GND: B1.GND@0 (GND), FONA_3G.4, FONA_3G.12, FONA_808.6, FONA_808.12, FONA_MINI.6, FONA_MINI.11, XBEE_2.11
GND_4: B1.GND@4 (GND), LED1.K (C), RTC.2, SD_READER.1
LED: B1.3, R1.2
unnamed: LED1.A, R1.1
OO: B1.50, SD_READER.3
SCK: B1.52, SD_READER.4
SCL: B1.21 (21(SCL)), RTC.4
SDA: B1.20 (20(SDA)), RTC.5
XBEE_RX: B1.14 (14(TX3)), XBEE_2.4
XBEE_TX: B1.15 (15(RX3)), XBEE_2.3

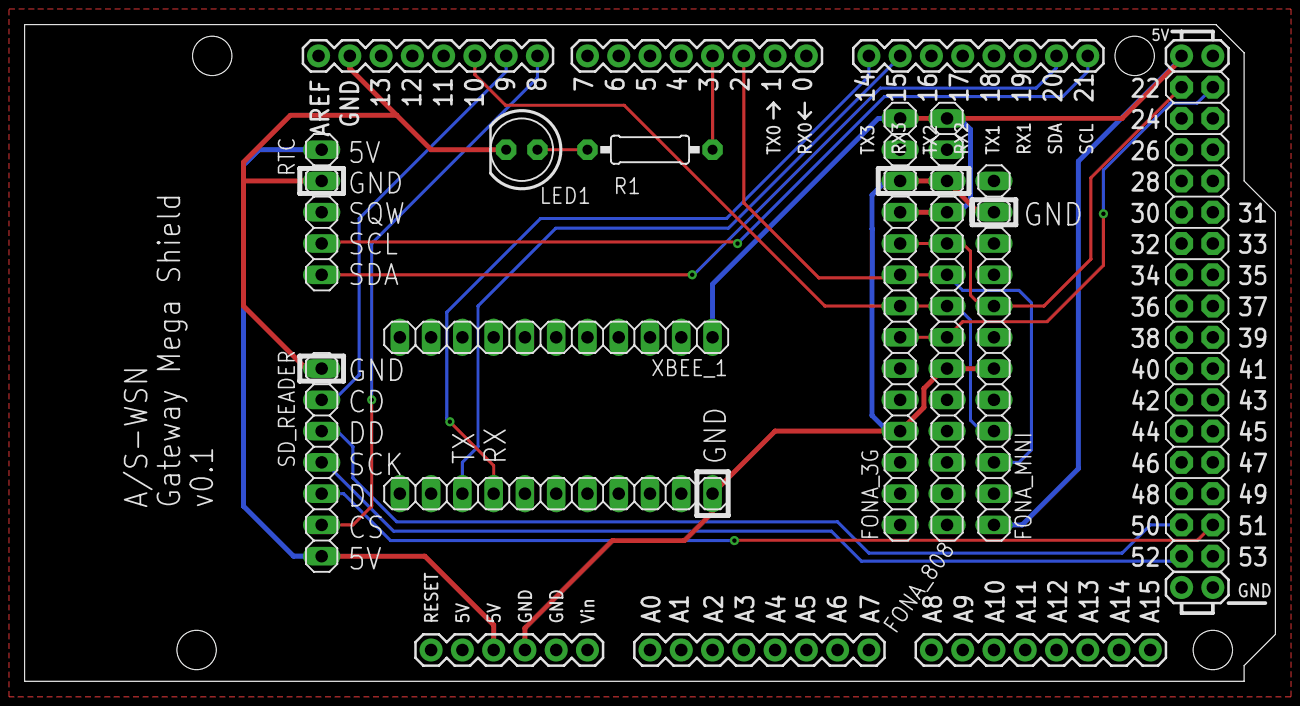
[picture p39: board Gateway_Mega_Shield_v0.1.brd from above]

Board: 2 copper layers, 101.6 x 53.3 mm, 10 parts (0 on the bottom side), 19 nets.

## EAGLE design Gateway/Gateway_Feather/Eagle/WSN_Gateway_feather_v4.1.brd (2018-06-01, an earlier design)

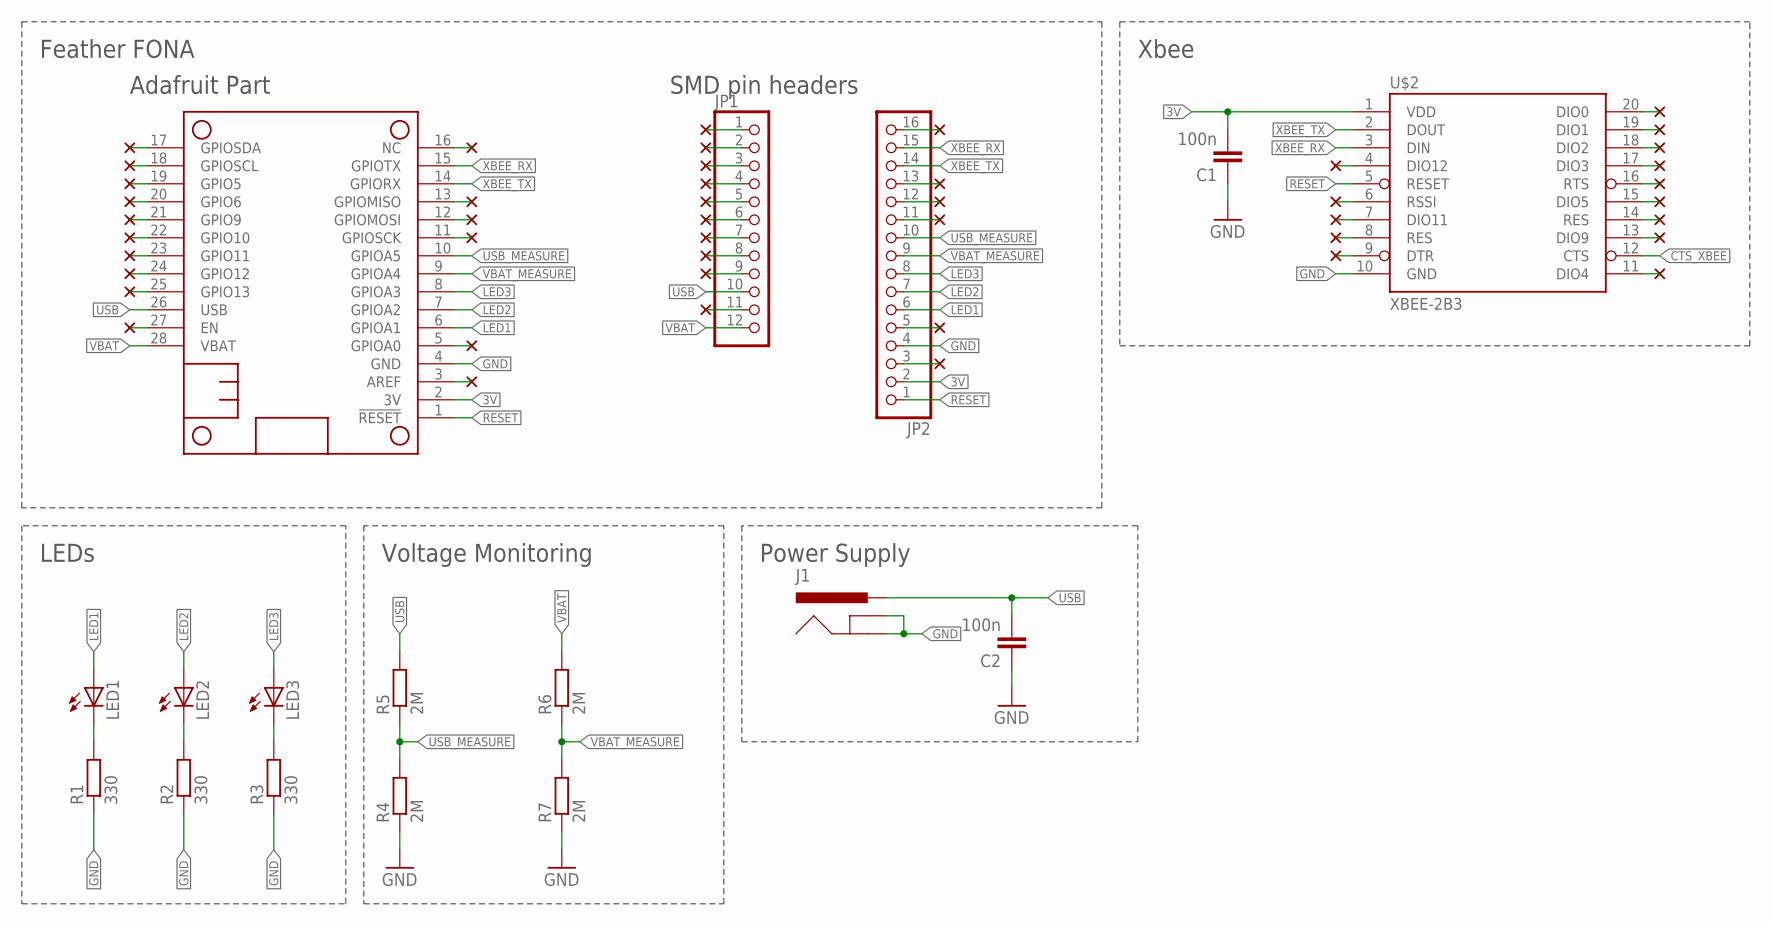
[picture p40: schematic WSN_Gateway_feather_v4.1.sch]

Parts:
C1, C2: 100n; C0805
J1: 5.5x2.1mm Barrel; POWER_JACK_SMD
JP1: PINHD-1X121X12_SMT; 1X12_SMT
JP2: PINHD-1X161X16_SMT; 1X16_SMT
LED1, LED2, LED3: LEDCHIPLED_0805; CHIPLED_0805
MS1: FEATHERWING_NODIM_NOHOLES; FEATHERWING_DIM_2
R1, R2, R3: 330; R0805
R4, R5, R6, R7: 2M; R0805
U$2: XBEE-2B3; XBEE-SMD

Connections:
3V: C1.2, JP2.2, MS1.2 (3V), U$2.1 (VDD)
CTS_XBEE: U$2.12 (CTS)
GND: C1.1, C2.1, J1.GND (GNDBREAK), J1.P$4 (GND), JP2.4, MS1.4 (GND), R1.1, R2.1, R3.1, R4.1, R7.1, U$2.10 (GND)
LED1: JP2.6, LED1.A, MS1.6 (GPIOA1)
LED2: JP2.7, LED2.A, MS1.7 (GPIOA2)
LED3: JP2.8, LED3.A, MS1.8 (GPIOA3)
unnamed: LED1.C, R1.2
unnamed: LED2.C, R2.2
unnamed: LED3.C, R3.2
RESET: JP2.1, MS1.1 (!RESET), U$2.5 (RESET)
USB: C2.2, J1.VIN0 (PWR), J1.VIN1 (PWR), JP1.10, MS1.26 (USB), R5.2
USB_MEASURE: JP2.10, MS1.10 (GPIOA5), R4.2, R5.1
VBAT: JP1.12, MS1.28 (VBAT), R6.2
VBAT_MEASURE: JP2.9, MS1.9 (GPIOA4), R6.1, R7.2
XBEE_RX: JP2.15, MS1.15 (GPIOTX), U$2.3 (DIN)
XBEE_TX: JP2.14, MS1.14 (GPIORX), U$2.2 (DOUT)

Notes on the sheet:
Xbee
Feather FONA
LEDs
Power Supply
Voltage Monitoring
Adafruit Part
SMD pin headers

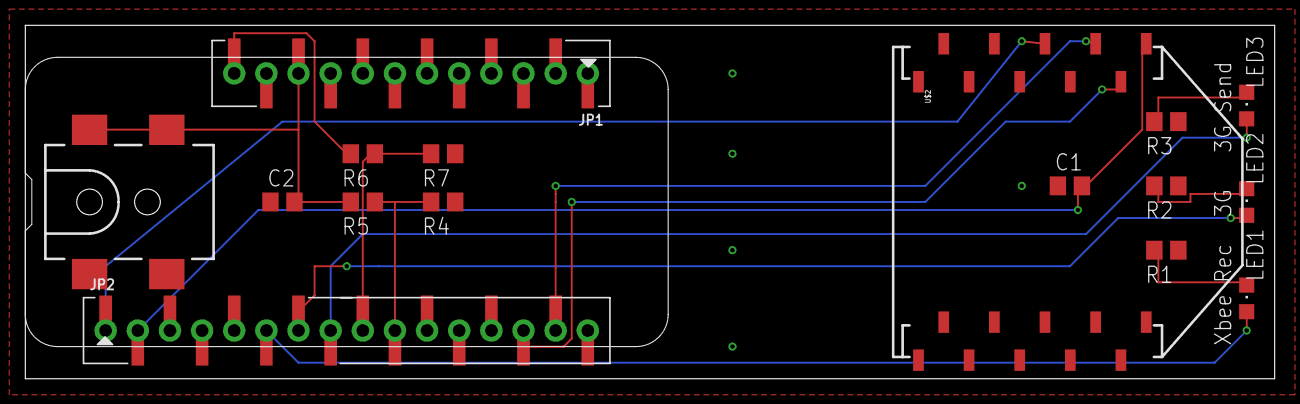
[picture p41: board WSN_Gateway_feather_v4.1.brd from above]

Board: 2 copper layers, 98.7 x 27.9 mm, 17 parts (0 on the bottom side), 15 nets.

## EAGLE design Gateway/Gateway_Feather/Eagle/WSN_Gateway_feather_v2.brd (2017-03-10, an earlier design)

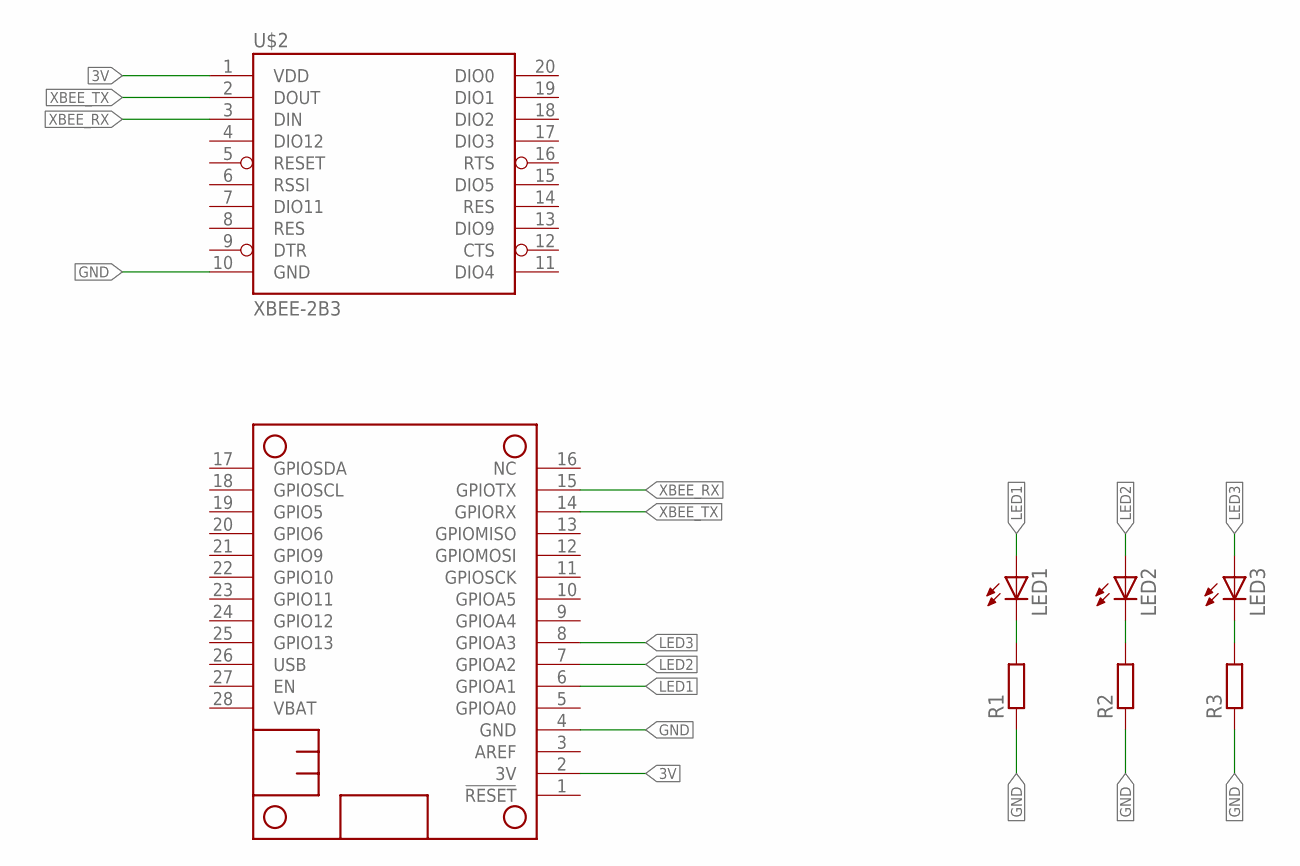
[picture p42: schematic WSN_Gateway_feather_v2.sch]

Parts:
LED1, LED2, LED3: LEDCHIPLED_0805; CHIPLED_0805
MS1: FEATHERWING_NODIM_NOHOLES; FEATHERWING_DIM_2
R1, R2, R3: R-EU_R0805; R0805
U$2: XBEE-2B3; XBEE-SMD

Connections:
3V: MS1.2 (3V), U$2.1 (VDD)
GND: MS1.4 (GND), R1.1, R2.1, R3.1, U$2.10 (GND)
LED1: LED1.A, MS1.6 (GPIOA1)
LED2: LED2.A, MS1.7 (GPIOA2)
LED3: LED3.A, MS1.8 (GPIOA3)
unnamed: LED1.C, R1.2
unnamed: LED2.C, R2.2
unnamed: LED3.C, R3.2
XBEE_RX: MS1.15 (GPIOTX), U$2.3 (DIN)
XBEE_TX: MS1.14 (GPIORX), U$2.2 (DOUT)

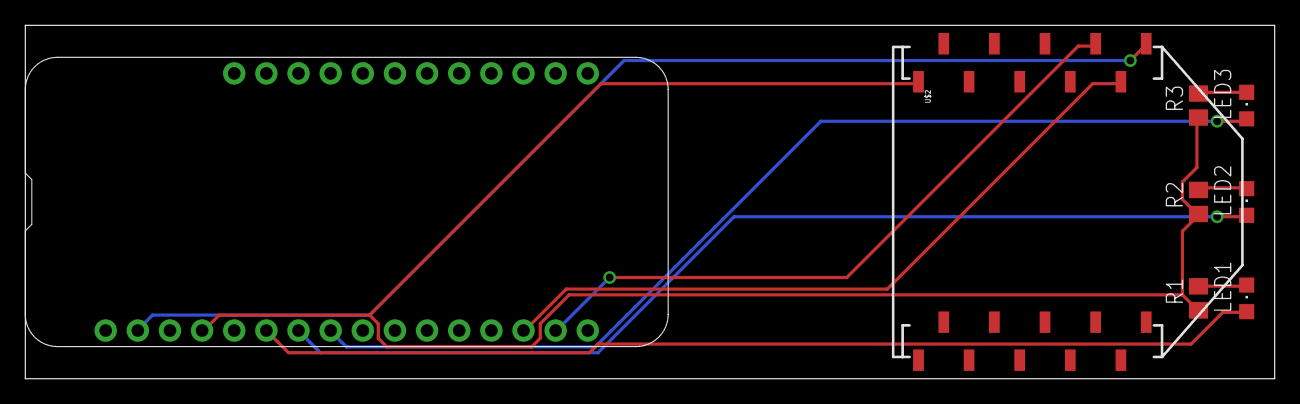
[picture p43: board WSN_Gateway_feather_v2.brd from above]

Board: 2 copper layers, 98.7 x 27.9 mm, 8 parts (0 on the bottom side), 10 nets.

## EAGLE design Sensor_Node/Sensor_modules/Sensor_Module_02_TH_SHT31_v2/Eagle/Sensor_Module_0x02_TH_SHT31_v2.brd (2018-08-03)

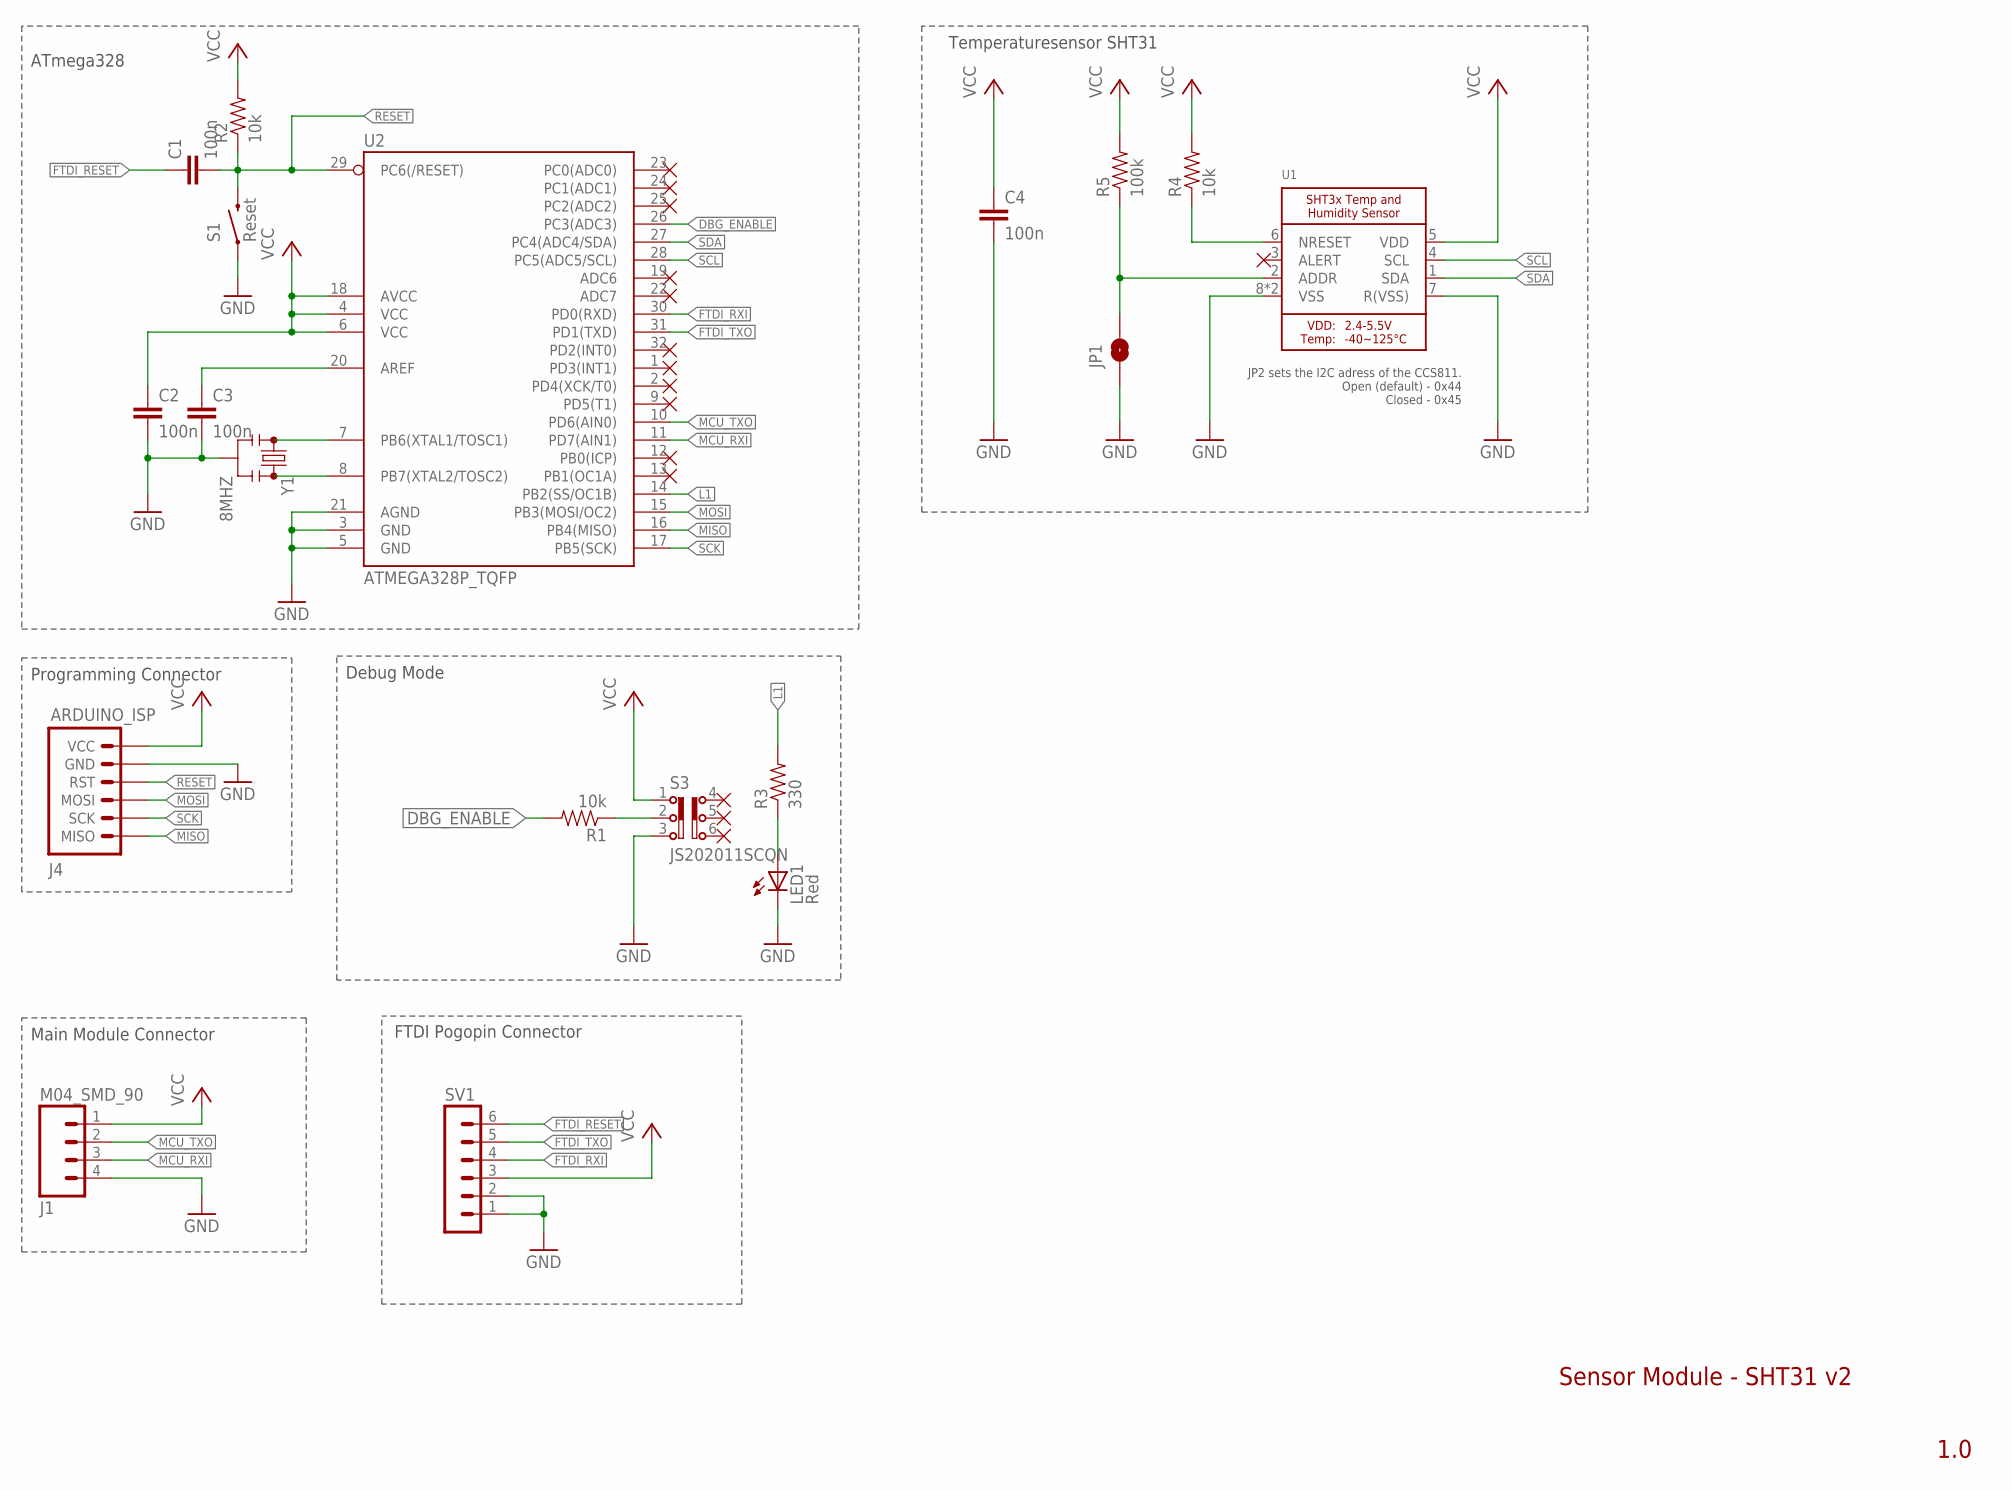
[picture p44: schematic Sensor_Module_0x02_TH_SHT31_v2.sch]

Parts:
C1, C2, C3, C4: 100n; C0805
J1: M04_SMD_90
J4: ARDUINO_ISP; M-2X3
JP1: SPARKFUN-JUMPERS_JUMPER-SMT_2_NO_SILK; SPARKFUN-JUMPERS_SMT-JUMPER_2_NO_SILK
LED1: Red; SML0805
R1, R2, R4: 10k; 0805
R3: 330; 0805
R5: 100k; 0805
S1: Reset; M-PUSHBUTTON-SMD
S3: JS202011SCQN
SV1: MA06-1
U1: MICROBUILDER_SHT3X
U2: ATMEGA328P_TQFP; TQFP32-08
Y1: 8MHZ; RESONATOR-SMD

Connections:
DBG_ENABLE: R1.2, U2.26 (PC3(ADC3))
FTDI_RESET: C1.1, SV1.6
FTDI_RXI: SV1.4, U2.30 (PD0(RXD))
FTDI_TXO: SV1.5, U2.31 (PD1(TXD))
GND: C2.2, C3.2, C4.2, J1.4, J4.P$5 (GND), JP1.1, LED1.C, S1.1 (LEFT), S1.2 (LEFT), S3.3, SV1.1, SV1.2, U1.7 (R(VSS)), U1.8 (VSS), U1.THERMAL (VSS), U2.3 (GND), U2.5 (GND), U2.21 (AGND), Y1.2
L1: R3.2, U2.14 (PB2(SS/OC1B))
MCU_RXI: J1.3, U2.11 (PD7(AIN1))
MCU_TXO: J1.2, U2.10 (PD6(AIN0))
MISO: J4.P$1 (MISO), U2.16 (PB4(MISO))
MOSI: J4.P$3 (MOSI), U2.15 (PB3(MOSI/OC2))
unnamed: U2.8 (PB7(XTAL2/TOSC2)), Y1.3
unnamed: U2.7 (PB6(XTAL1/TOSC1)), Y1.1
unnamed: R1.1, S3.2
unnamed: R4.1, U1.6 (NRESET)
unnamed: JP1.2, R5.1, U1.2 (ADDR)
unnamed: C3.1, U2.20 (AREF)
unnamed: LED1.A, R3.1
RESET: C1.2, J4.P$4 (RST), R2.1, S1.3 (RIGHT), S1.4 (RIGHT), U2.29 (PC6(/RESET))
SCK: J4.P$2 (SCK), U2.17 (PB5(SCK))
SCL: U1.4 (SCL), U2.28 (PC5(ADC5/SCL))
SDA: U1.1 (SDA), U2.27 (PC4(ADC4/SDA))
VCC: C2.1, C4.1, J1.1, J4.P$6 (VCC), R2.2, R4.2, R5.2, S3.1, SV1.3, U1.5 (VDD), U2.4 (VCC), U2.6 (VCC), U2.18 (AVCC)

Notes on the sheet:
Debug Mode
Programming Connector
ATmega328
Main Module Connector
Sensor Module - SHT31 v2
1.0
FTDI Pogopin Connector
JP2 sets the I2C adress of the CCS811. Open (default) - 0x44 Closed - 0x45
Temperaturesensor SHT31

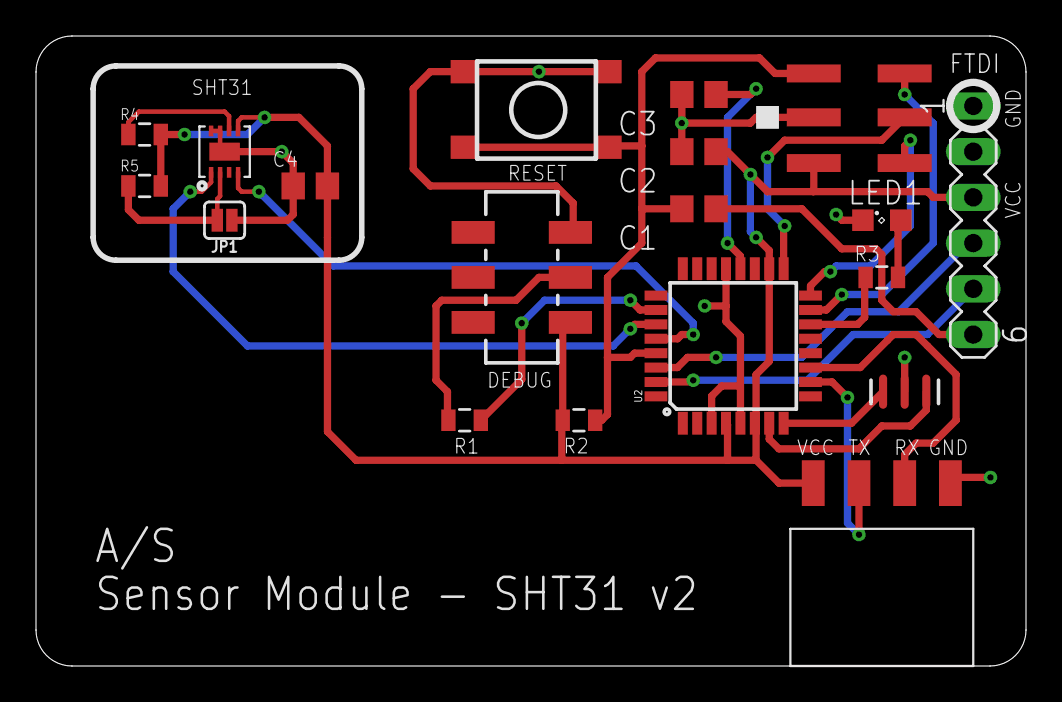
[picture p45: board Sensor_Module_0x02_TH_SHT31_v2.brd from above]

Board: 2 copper layers, 55.0 x 35.0 mm, 19 parts (0 on the bottom side), 22 nets.

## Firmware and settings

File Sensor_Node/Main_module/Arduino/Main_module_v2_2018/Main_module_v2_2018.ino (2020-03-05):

// To configure:

static const uint16_t C_MEASUREMENT_EVERY_X_MIN = 5; // Every how many minutes a measurement is taken from the sensor module
static const uint16_t C_SD_XBEE_EVERY_X = 1; // Every how many measurements a XBEE transmit and SD card write is made

static const float LOW_BATTERY_WARNING_LEVEL = 3.4; // V

// Coordinator XBee Address:
#define UPLINK_SH 0x13A200

//#define UPLINK_SL 0x  // C0
//#define UPLINK_SL 0x41046BD5  // C100
//#define UPLINK_SL 0x41628F9C  // C200
//#define UPLINK_SL 0x415ABDD9  // C300
#define UPLINK_SL 0x41046775  // C400
//#define UPLINK_SL 0x41631484  // C500
//#define UPLINK_SL 0x41628FF0  // C600
//#define UPLINK_SL 0x41628FA9  // C700
//#define UPLINK_SL 0x41628FFD  // C800



// Network ID (XBee PAN ID of Corrdinator): unsigned int 32 bit
//static const uint32_t PAN_ID = 0x01;   // C0
//static const uint32_t PAN_ID = 0x100;  // C100
//static const uint32_t PAN_ID = 0x200;  // C200
//static const uint32_t PAN_ID = 0x300;  // C300
static const uint32_t PAN_ID = 0x400;  // C400
//static const uint32_t PAN_ID = 0x500;  // C500
//static const uint32_t PAN_ID = 0x600;  // C600
//static const uint32_t PAN_ID = 0x700;  // C700
//static const uint32_t PAN_ID = 0x800;  // C800

// This communication module's ID. Allowed range: [0,65535] (unsigned 16 bit integer)
static const uint16_t THIS_CM_ID = 417;





/********************************
   END OF CONFIGURATION
 ********************************/

uint16_t wakeup_counter = 0;
uint8_t measurement_counter = 0;

static const uint8_t FRAMESTART_BYTE = 0xAA; // ANYTHING OTHER THAN 0xBB
uint8_t* total_xbee_payload;
uint8_t total_xbee_payload_size;
uint8_t SMtype = 0; // Will be set once the sensor module tells us
uint8_t sizeofSMdata = 0; // Will be set to number of bytes of the SM payload once the sensor module
uint16_t MEASUREMENT_EVERY_X_MIN = 1;
uint16_t SD_XBEE_EVERY_X = 1;


static const uint8_t xbee_header_bytes = 4; // uint16_t NodeID, uint8_t n_measurements, uint8_t SM_type

// Pin numbers
static const uint8_t P_L1 = 14; // LED 1
static const uint8_t P_L2 = 15; // LED 2
static const uint8_t P_L3 = 16;// LED 3
static const uint8_t P_DBG_ENABLE = 17; // Input, Debug Slide Switch
static const uint8_t P_SDA = 18; // SDA pin for I2C
static const uint8_t P_SCL = 19; // SDL pin for I2C
static const uint8_t P_VBAT_MEASURE = 20; // Input, pin for measureing battery voltage over voltage divider
static const uint8_t P_A7 = 21; // Unused
static const uint8_t P_MCU_RXI = 0;
static const uint8_t P_MCU_TXO = 1;
static const uint8_t P_RTC_WAKE = 2; // Interrupt from RTC
static const uint8_t P_SM_WAKE = 3; // Interrupt from interrupting sensor module
static const uint8_t P_SLP_XBEE = 4;  // Output, put XBee module to sleep
static const uint8_t P_SM_VCC_EN = 5; // Output, enable controlled supply voltage to SM
static const uint8_t P_CTS_XBEE = 6; // Input, XBee's clear to send pin
static const uint8_t P_SD_CD = 7; // Input, detect whether SD card is inserted
static const uint8_t P_SD_SS = 8; // Output, slave select pin for SD card SPI
static const uint8_t P_XBEE_RXI = 9; // Serial communication RXI pin for Xbee
static const uint8_t P_XBEE_TXO = 10; // Serial communication TXO pin for Xbee
static const uint8_t P_MOSI = 11; // SPI MOSI pin
static const uint8_t P_MISO = 12; // SPI MISO pin
static const uint8_t P_SCK = 13; // SPI SCK pin


#include <avr/interrupt.h>
#include <avr/power.h>
#include <avr/sleep.h>
#include <avr/io.h>

#include "Wire.h"
#define DS3231_I2C_ADDRESS 0x68

#include <SD.h>
#include <SPI.h>
File root;
File myFile;

#include <XBee.h>

XBee xbee = XBee();
XBeeAddress64 addr64 = XBeeAddress64(UPLINK_SH, UPLINK_SL); // SH + SL Address of receiving XBee
ZBTxRequest zbTx;
ZBTxStatusResponse txStatus = ZBTxStatusResponse();

#include <SoftwareSerial.h>
SoftwareSerial xbeeSoftSerial(P_XBEE_TXO, P_XBEE_RXI);

volatile bool wakeUpInterrupt_flag_RTC = false;
volatile bool wakeUpInterrupt_flag_SM = false;
volatile bool sd_card_is_initialized = false;
volatile bool ignore_rtc_interrupt = false;
volatile bool ignore_sm_interrupt = false;

bool debug_mode_enabled = false;
bool debug_mode_has_been_switched_off  = false;
bool low_battery_level_detected = false;
bool first_time = true;


void setup()
{
  pinMode(P_SM_VCC_EN, OUTPUT);
  digitalWrite(P_SM_VCC_EN, LOW);

  pinMode(P_L1, OUTPUT);
  digitalWrite(P_L1, LOW);
  pinMode(P_L2, OUTPUT);
  digitalWrite(P_L2, LOW);
  pinMode(P_L3, OUTPUT);
  digitalWrite(P_L3, LOW);
  pinMode(P_DBG_ENABLE, INPUT);
  pinMode(P_SD_CD, INPUT);

  // Initialize RTC 
  Wire.begin();
  setupDS3231(true);
  setDS3231time(01, 49, 23, 7, 01, 01, 10); // DS3231 seconds, minutes, hours, day, date, month, year
  pinMode(P_RTC_WAKE, INPUT_PULLUP); // Pin for Wakeup from RTC

  digitalWrite(P_L1, HIGH); // Indicate RTC initialized ok


  // For sleep mode: Shut down things we do not need:
  ACSR = (1 << ACD); //Disable the analog comparator

  // Sensor Module setup
  setupSerialToSM();
  pinMode(P_SM_WAKE, INPUT_PULLUP);

  // Start XBee
  pinMode(P_CTS_XBEE, INPUT);
  pinMode(P_SLP_XBEE, OUTPUT);
  digitalWrite(P_SLP_XBEE, LOW);

  xbeeSoftSerial.begin(9600);
  xbee.setSerial(xbeeSoftSerial);

  // Wait until XBee is ready after starting up:
  while (digitalRead(P_CTS_XBEE) == 1) {}

  // XBee configuration
  uint8_t SM_value = 0x01;
  setATCommandToValue('S', 'M', &SM_value, sizeof(SM_value));
  sendATCommand('W', 'R');
  sendATCommand('A', 'C');
  // The SM configuration does not work

  // Convert PAN ID from little endian (what arudino uses) to big endian (what XBee wants)
  uint32_t b0, b1, b2, b3;
  b0 = (PAN_ID & 0x000000FF) << 24u;
  b1 = (PAN_ID & 0x0000FF00) << 8u;
  b2 = (PAN_ID & 0x00FF0000) >> 8u;
  b3 = (PAN_ID & 0xFF000000) >> 24u;

  uint32_t big_endian_pan_id = b0 | b1 | b2 | b3;

  setATCommandToValue('I', 'D', (uint8_t*)&big_endian_pan_id, sizeof(big_endian_pan_id));

  sendATCommand('W', 'R');
  sendATCommand('A', 'C');

  // Wait until XBee network joined
  uint8_t AI_value = 0xFF;
  while (AI_value != 0x00)
  {
    // "AI" AT command returns network status. 0x00 means successfully joined.
    AI_value = getSingleByteATCmdValue('A', 'I');

    digitalWrite(P_L2, HIGH); // blinking led indicates trying to join XBee network
    delay(150);
    digitalWrite(P_L2, LOW);
    delay(350);
  }

  digitalWrite(P_L2, HIGH); // Indicate Xbee network joined ok

  // Initialize SD card with slave-select pin
  sdSetup();
  digitalWrite(P_L3, HIGH); // Indicate SD initialized ok


  delay(2000); // Time to let the user see the status LEDs.

  // If debug mode is enable we measure and send more often
  if (digitalRead(P_DBG_ENABLE) == LOW) // Switch on east side = LOW
  {
    debug_mode_enabled = true;
    MEASUREMENT_EVERY_X_MIN = 1;
    SD_XBEE_EVERY_X = 1;
  }
  else
  {
    debug_mode_enabled = false;
    MEASUREMENT_EVERY_X_MIN = C_MEASUREMENT_EVERY_X_MIN;
    SD_XBEE_EVERY_X = C_SD_XBEE_EVERY_X;
  }

  digitalWrite(P_L1, LOW);
  digitalWrite(P_L2, LOW);
  digitalWrite(P_L3, LOW);

  // Make first RTC interruppt occur shortly afterwards seconds
  setDS3231time(59, 49, 23, 7, 01, 01, 10); // DS3231 seconds, minutes, hours, day, date, month, year
  // Clear interrupt flag in RTC IC: Clear A2F and A1F bits by setting them to 0
  Wire.beginTransmission(DS3231_I2C_ADDRESS);
  Wire.write(0x0F); // write to register (0Fh)
  Wire.write(0b10001000);
  Wire.endTransmission();


  wakeUpInterrupt_flag_RTC = false;
  wakeUpInterrupt_flag_SM = false;
}

void loop()
{
  // START EXTENDED SETUP
  // This first_time part is not in the setup() because it somehow did not work then.
  if (first_time == true && wakeUpInterrupt_flag_RTC  == true)
  {
    // The first time the RTC interrupt happens, we are still kind of in the setup phase (not programmed very nicely...)
    // Meaning that only now do we learn whether the sensor module is a periodic one or an interrupting one
    first_time = false;

    digitalWrite(P_L1, HIGH); // Indicate start acquiring sensor measurement

    // Take sensor module measurement
    turnOnSensorModule();
    delay(100); // Give some time for SM to start if it was not turned on
    Serial.write(0xBB); // If it is an interrupting sensor module it will respond to this and if it is a periodic one it will respond with its measurement, which will begin with the FRAMESTART_BYTE

    bool checksum_ok = readSensorModuleData();
    turnOffSensorModule();

    // From ignore_rtc_interrupt we can now tell what kind of sensor module we have
    if (ignore_rtc_interrupt == false)
    {
      // LED 3 indicates periodic sensor module
      digitalWrite(P_L3, HIGH);
      delay(1000);
      digitalWrite(P_L3, LOW);
    }
    else
    {
      // Sensor module is one which will interrupt the communication module
      digitalWrite(P_L2, HIGH);
      delay(1000);
      digitalWrite(P_L2, LOW);
    }
    digitalWrite(P_L1, LOW);

    wakeup_counter = 0;
    measurement_counter = 0;

    // Disable interrupt flag in RTC IC: Clear A2F and A1F bits by setting them to 0
    Wire.beginTransmission(DS3231_I2C_ADDRESS);
    Wire.write(0x0F); // write to register (0Fh)
    Wire.write(0b10001000);
    Wire.endTransmission();

    // Make next RTC interruppt occur in 5 seconds afterwards seconds
    setDS3231time(55, 49, 23, 7, 01, 01, 10); // DS3231 seconds, minutes, hours, day, date, month, year
    // Clear interrupt flag in RTC IC: Clear A2F and A1F bits by setting them to 0
    Wire.beginTransmission(DS3231_I2C_ADDRESS);
    Wire.write(0x0F); // write to register (0Fh)
    Wire.write(0b10001000);
    Wire.endTransmission();


    wakeUpInterrupt_flag_RTC = false;
  }
  // END OF EXTENDED SETUP


  // The usual RTC interrupt when using a periodic sensor module will trigger this:
  if (wakeUpInterrupt_flag_RTC == true && ignore_rtc_interrupt == false)
  {
    if (debug_mode_enabled == true)
    {
      // First check if slide switch still selects debug mode
      if (digitalRead(P_DBG_ENABLE) == HIGH)
      {
        // Debug has been disabled by the user
        debug_mode_enabled = false;
        debug_mode_has_been_switched_off = true;
        MEASUREMENT_EVERY_X_MIN = C_MEASUREMENT_EVERY_X_MIN;
        SD_XBEE_EVERY_X = C_SD_XBEE_EVERY_X;
      }
      else
      {
        digitalWrite(P_L1, HIGH);
      }
    }


    wakeup_counter++;

    // Take measurement if it is time
    if (wakeup_counter >= MEASUREMENT_EVERY_X_MIN)
    {
      // Check battery level
      float currentBatteryVoltage = measureVBat();
      if (low_battery_level_detected == false && currentBatteryVoltage < LOW_BATTERY_WARNING_LEVEL && currentBatteryVoltage > 1) // > 1 check because if it is supplied through the power jack, then VBat is zero. So I use 1V here, because with 1V at VBat the system would not be running.
      {
        digitalWrite(P_SLP_XBEE, LOW); // Wake XBee up
        // Wait until XBee is ready after waking up:
        while (digitalRead(P_CTS_XBEE) == 1) {}
        xbee_transmit_lowbatterywarning(currentBatteryVoltage);
        digitalWrite(P_SLP_XBEE, HIGH); // Xbee sleep
        low_battery_level_detected = true; // So that only the first time will the warning be transmitted
        ignore_rtc_interrupt = true; // Do not wake up ever again to safe the battery
        ignore_sm_interrupt = true;
      }

      // Take sensor module measurement
      turnOnSensorModule();

      bool checksum_ok = readSensorModuleData();
      //      if (checksum_ok)

      turnOffSensorModule();

      if (debug_mode_enabled == true)
      {
        digitalWrite(P_L2, HIGH);
      }

      wakeup_counter = 0;
      measurement_counter++;
    }

    // Transmit and SD write accumulated measurements if it is time
    if (measurement_counter >= SD_XBEE_EVERY_X)
    {
      // Do SD write and XBEE transmit

      digitalWrite(P_SLP_XBEE, LOW); // Wake XBee up
      // Wait until XBee is ready after waking up:
      while (digitalRead(P_CTS_XBEE) == 1) {}

      xbee_transmit_data();

      digitalWrite(P_SLP_XBEE, HIGH); // Xbee sleep


      if (debug_mode_enabled == true)
      {
        digitalWrite(P_L3, HIGH);
      }


      sdWrite();

      measurement_counter = 0;
    }

    if (debug_mode_enabled == true)
    {
      delay(2000);
      digitalWrite(P_L1, LOW);
      digitalWrite(P_L2, LOW);
      digitalWrite(P_L3, LOW);
    }

    if (debug_mode_enabled == true)
    {
      // If we are in debug mode we want an interrupt every 10 seconds instead of every minute.
      setDS3231time(50, 49, 23, 7, 01, 01, 10); // DS3231 seconds, minutes, hours, day, date, month, year
    }

    // Disable interrupt flag in RTC IC: Clear A2F and A1F bits by setting them to 0
    Wire.beginTransmission(DS3231_I2C_ADDRESS);
    Wire.write(0x0F); // write to register (0Fh)
    Wire.write(0b10001000);
    Wire.endTransmission();


    wakeUpInterrupt_flag_RTC = false;
  }


  // The usual interrupt from the sensor module when using an interrupting sensor module will trigger this:
  if (wakeUpInterrupt_flag_SM == true && ignore_sm_interrupt == false)
  {
    // transmit at every event
    SD_XBEE_EVERY_X = 1;
    startSerialToSM();

    // Check battery level
    float currentBatteryVoltage = measureVBat();
    if (low_battery_level_detected == false && currentBatteryVoltage < LOW_BATTERY_WARNING_LEVEL && currentBatteryVoltage > 1)
    {
      digitalWrite(P_SLP_XBEE, LOW); // Wake XBee up
      // Wait until XBee is ready after waking up:
      while (digitalRead(P_CTS_XBEE) == 1) {}
      xbee_transmit_lowbatterywarning(currentBatteryVoltage);
      digitalWrite(P_SLP_XBEE, HIGH); // Xbee sleep
      low_battery_level_detected = true; // So that only the first time will the warning be transmitted
      ignore_rtc_interrupt = true; // Do not wake up ever again to safe the battery
      ignore_sm_interrupt = true;
    }


    if (debug_mode_enabled == true)
    {
      // First check if slide switch still selects debug mode
      if (digitalRead(P_DBG_ENABLE) == HIGH)
      {
        debug_mode_enabled = false;
        debug_mode_has_been_switched_off = true;
      }
      else
      {
        digitalWrite(P_L1, HIGH);
      }
    }

    turnOnSensorModule();
    startSerialToSM();
    readSensorModuleData();
    turnOffSensorModule();   // Addition by Mario to code from Marc
    
    if (debug_mode_enabled == true)
    {
      digitalWrite(P_L2, HIGH);
    }

    digitalWrite(P_SLP_XBEE, LOW); // Wake XBee up
    // Wait until XBee is ready after waking up:
    while (digitalRead(P_CTS_XBEE) == 1) {}

    xbee_transmit_data();
    digitalWrite(P_SLP_XBEE, HIGH); // Xbee sleep

    if (debug_mode_enabled == true)
    {
      digitalWrite(P_L3, HIGH);
    }


    sdWrite();


    if (debug_mode_enabled == true)
    {
      delay(2000);
      digitalWrite(P_L1, LOW);
      digitalWrite(P_L2, LOW);
      digitalWrite(P_L3, LOW);
    }


    wakeUpInterrupt_flag_SM = false;
  }


  goToSleep();
}







/*****************************
   Sensor Module related functions
*/

void turnOnSensorModule()
{
  startSerialToSM();

  delay(3); // Small delay necessary somehow

  // Enable voltage to sensor module
  digitalWrite(P_SM_VCC_EN, HIGH);
}

void turnOffSensorModule()
{
  // Disable voltage to sensor module
  digitalWrite(P_SM_VCC_EN, LOW);

  endSerialToSM();
}

// return: true if checksum ok, false if checksum wrong
bool readSensorModuleData()
{

  uint8_t sumForChecksum = 0x00;


  // Wait for frame start byte
  uint8_t readByte = 0x00;
  while (readByte != FRAMESTART_BYTE)
  {
    while (!Serial.available()) {}
    readByte = Serial.read();

    // The sensor module is an interrupt based one and not one that we use periodically, so return. WWe will note this and not try to ask it with the RTC interrupt anymore.
    if (readByte == 0xBB)
    {
      ignore_rtc_interrupt = true;
      return false;
    }
  }


  sumForChecksum += FRAMESTART_BYTE;

  // Next byte indicates type of sensormodule
  while (!Serial.available()) {}
  uint8_t SMtypebyte = Serial.read();
  sumForChecksum += SMtypebyte;

  // Next byte indicates length of data
  while (!Serial.available()) {}
  uint8_t SMsizebyte = Serial.read();
  sumForChecksum += SMsizebyte;


  // If sensor module type has changed, or if it is the first time we read from sensor module. Or if the debug mode was disabled we need to cahnge the size of the memory for the payload too
  if (SMtypebyte != SMtype || debug_mode_has_been_switched_off == true)
  {
    debug_mode_has_been_switched_off = false;

    if (SMtype != 0 || debug_mode_has_been_switched_off == true)
    {
      // The sensor module was actually changed or debug mode has been switched off
      // Throw out data measured but not yet transmitted of old SM for sake of simplicity
      free(total_xbee_payload);
      wakeup_counter = 0;
      measurement_counter = 0;
    }

    sizeofSMdata = SMsizebyte;
    SMtype = SMtypebyte;

    // Allocate space for accumulating required number of measurements before transmit is done
    total_xbee_payload_size = (xbee_header_bytes + sizeofSMdata * SD_XBEE_EVERY_X);
    total_xbee_payload = (uint8_t*) malloc(total_xbee_payload_size);


    // Fill in the header
    total_xbee_payload[0] = 0x00FF & THIS_CM_ID;
    total_xbee_payload[1] = (0xFF00 & THIS_CM_ID)>>8;  // >>8 is a fix from original code (Mario/Marc)
    total_xbee_payload[2] = SD_XBEE_EVERY_X; // How many measurements are in this packet
    total_xbee_payload[3] = SMtype;
  }


  // Wait until payload arrived plus checksum byte
  while (Serial.available() < sizeofSMdata + 1) {}

  // Read the payload
  for (int k = 0; k < sizeofSMdata; k++)
  {
    uint8_t inByte = (uint8_t) Serial.read();
    sumForChecksum += inByte;
    (total_xbee_payload + xbee_header_bytes + measurement_counter * SMsizebyte)[k] = inByte; // " xbee_header_bytes + (measurement_counter-1)*SMsizebyte" provides offset, for second, third etc measurements
  }


  // Read checksum byte
  uint8_t checksumbyte = Serial.read();


  // Confirm that checksum is ok
  if (uint8_t (checksumbyte + sumForChecksum) == 0xFF)
  {
    return true;
  }
  else
  {
    return false;
  }
}

void setupSerialToSM()
{
  pinMode(P_MCU_TXO, OUTPUT);
  digitalWrite(P_MCU_TXO, LOW);
  pinMode(P_MCU_RXI, OUTPUT);
  digitalWrite(P_MCU_RXI, LOW);
}

void startSerialToSM()
{
  Serial.begin(9600);
}

void endSerialToSM()
{
  // End serial connection to sensor module
  // If Serial.end() is not called, the MCU_TXO pin stays at high voltage level
  Serial.end();

  // Pins low
  pinMode(P_MCU_TXO, OUTPUT);
  digitalWrite(P_MCU_TXO, LOW);
  pinMode(P_MCU_RXI, OUTPUT);
  digitalWrite(P_MCU_RXI, LOW);
}

void serialFlush()
{
  while (Serial.available() > 0) {
    char t = Serial.read();
  }
}

/*****************************
   XBee
*/
void xbee_transmit_data()
{
  zbTx = ZBTxRequest(addr64, total_xbee_payload, total_xbee_payload_size);


  //  uint8_t dummy[3] = {10,5,1};
  //  zbTx = ZBTxRequest(addr64, dummy, 3);

  bool message_acked = false;
  while (message_acked == false)
  {
    message_acked = true; // TODO
    xbee.send(zbTx);

    // flash TX indicator
    //Serial.println("SENT.");
    //digitalWrite(13, HIGH);
    //delay(20);
    //digitalWrite(13, LOW);

    // after sending a tx request, we expect a status response
    // wait up to half second for the status response
    if (xbee.readPacket(500)) {
      // got a response!

      // should be a znet tx status
      if (xbee.getResponse().getApiId() == ZB_TX_STATUS_RESPONSE) {
        xbee.getResponse().getZBTxStatusResponse(txStatus);

        // get the delivery status, the fifth byte
        if (txStatus.getDeliveryStatus() == SUCCESS) {
          // success.  time to celebrate
          //Serial.println("SUCCESS.");
          //flashLed(statusLed, 5, 50);
          message_acked = true;

        } else {
          // the remote XBee did not receive our packet. is it powered on?
          //Serial.println("FAILURE - RECEIVER DID NOT RECEIVE IT");
          //flashLed(errorLed, 3, 500);
          message_acked = false;

        }
      }
    } else if (xbee.getResponse().isError()) {
      //nss.print("Error reading packet.  Error code: ");
      //nss.println(xbee.getResponse().getErrorCode());
    } else {
      // local XBee did not provide a timely TX Status Response -- should not happen
      //Serial.println("FAILURE - FROM OUR MODULE.");
      //flashLed(errorLed, 2, 50);
    }
  }
}
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

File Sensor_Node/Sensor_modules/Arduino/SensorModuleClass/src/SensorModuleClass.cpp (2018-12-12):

/*
  CommClass
*/


#include "SensorModuleClass.h"
#include "Arduino.h"
#include <stdio.h>
#include <avr/wdt.h> 

SensorModuleClass::SensorModuleClass(){
    payload.payload1= 0;
    payload.payload2= 0;
    payload.payload3= 0;
    payload.payload4= 0;
    payload.payload5= 0;
}
    

void SensorModuleClass::set_sensor_module_type(byte sensor_module_type) {
    sensor_module_type_byte = sensor_module_type;
}

void SensorModuleClass::set_payload(float float1, float float2, float float3, float float4, float float5) {
    payload.payload1= float1;
    payload.payload2= float2;
    payload.payload3= float3;
    payload.payload4= float4;
    payload.payload5= float5;
}

void SensorModuleClass::send_message() {
  uint8_t checksumbyte = 0;
  
  // Framestart byte
  mySerial->write(start_byte);
  checksumbyte += start_byte;
  
  // SM type
  mySerial->write((uint8_t) sensor_module_type_byte); // Sensormodule type
  checksumbyte += (uint8_t) sensor_module_type_byte;
  
  // Length of data
  mySerial->write((uint8_t) sizeof(payload)); // Sensormodule type
  checksumbyte += (uint8_t) sizeof(payload);
  
  // Payload
  mySerial->write((uint8_t*) &payload, sizeof(payload));
  
  uint8_t* payloadPtr = (uint8_t*) &payload;
  for (uint8_t k=0;k<sizeof(payload);k++)
  {
    checksumbyte += payloadPtr[k];
  }
  
  checksumbyte = 0xFF - checksumbyte; // such that is sums up to 0xFF
  mySerial->write(checksumbyte);
}

void SensorModuleClass::set_serial(Stream &serialPort) {
  mySerial = &serialPort;
} 

void SensorModuleClass::set_led_pin(int pin) {
  led_pin = pin;
  pinMode(led_pin, OUTPUT);
  digitalWrite(led_pin, LOW);
}

void SensorModuleClass::set_debug_pin(int pin) {
  debug_pin = pin;
  pinMode(debug_pin, INPUT);
}

void SensorModuleClass::blink(int n) {
  if (debug_enabled()) {                  // Check debugging switch
    for (int i=0; i<n; i++) {             // Blink LED n times
      digitalWrite(led_pin, HIGH);
      delay(10);
      digitalWrite(led_pin, LOW);
      delay(50);
    }
  }
}


bool SensorModuleClass::debug_enabled(){
  return digitalRead(debug_pin);
}

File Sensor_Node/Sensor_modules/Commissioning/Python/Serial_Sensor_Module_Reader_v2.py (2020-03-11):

#################################################################
# Python serial sensor module reader                            #
#                                                               #
# This scripts reads the serial output form a sensor module and #
# translates the output to human readable form                  #
# Author: Mario Frei mario.frei@arch.ethz.ch                    #
#                                                               #
# Date: 10.11.2016                                              #
#################################################################


import time
import serial
import struct

SerialPort = 'COM8'

print('Python serial sensor module reader')
print('')

# configure the serial connections (the parameters differs on the device you are connecting to)
ser = serial.Serial(
    port=SerialPort,
    baudrate=9600,
    parity=serial.PARITY_NONE,
    stopbits=serial.STOPBITS_ONE,
    bytesize=serial.EIGHTBITS
)

ser.isOpen()

try:
    while 1:
        if ser.inWaiting()>0:
            # Framestart byte
            framestart_byte = ser.read(1)
            myCheckSum = 0
            myCheckSum += struct.unpack('B', framestart_byte)[0]
            print('Framestart byte:\t', framestart_byte)
            
            # Sensor module type
            sensor_module_type = ser.read(1)
            sensor_module_type = struct.unpack('B', sensor_module_type)[0]
            print('Sensor module type:\t', sensor_module_type)
            myCheckSum += sensor_module_type
            
            # Number of payload bytes
            number_of_payloads = ser.read(1)
            number_of_payloads = struct.unpack('B', number_of_payloads)[0]
            print('Number of payload bytes:', number_of_payloads)
            myCheckSum += number_of_payloads          

            # Payloads & values
            number_of_values = int(number_of_payloads/4)
            value = []
            for i in range(0, number_of_values):
                n = i+1
                payload = ser.read(4)
                myCheckSum += payload[0]
                myCheckSum += payload[1]
                myCheckSum += payload[2]
                myCheckSum += payload[3]
                value.append(struct.unpack('f', payload)[0])
                print('payload', n, ':\t\t', payload, 'value', n, ': ', value[i])
            
            # checksum
            checksum = ser.read(1)
            checksum = struct.unpack('B', checksum)[0]
            last_byte = (myCheckSum >>0) & 0xFF   # get last byte of myChecksum
            myCheckSum = 255-last_byte            # subtract last byte from 0xff
            if checksum == myCheckSum:
                print('Checksum OK')
            else:
                print('Checksum not OK')
            print('\n\n')
        else:
            time.sleep(0.1)
except KeyboardInterrupt:
    ser.close()
    print('bye')

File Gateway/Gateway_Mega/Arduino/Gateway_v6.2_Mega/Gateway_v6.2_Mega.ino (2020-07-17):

/***************************************************
 * Gateway Arduino Sketch v6.2                     *
 * Author: Mario Frei                              *
 * Year: 2019                                      *
 * Sources: FONA library FONAtest sketch           *
 *          Xbee library example sketch            *
 *          SD library example sketch              *
 *          RTC library example sketch (Sparkfun)  * 
 ***************************************************/

// Improvement from 6.1
//  - Add fona RSSI readout               ()
//  - Add fona battery readout            ()
//
// To Do:
//  - Add heart beat message              ()
//  - Add input parameters to send2server ()
//  - Add input parameters to write2sd    ()

int gatewayID = 0;                                                   // Set this accordingly
String serverURL = "http://[your webserver]/wsn/gateway2mysql/gateway2mysql.php?token=";  // Insert the url to your web server here
float heartbeat_interval = 0.5;                                      // Heartbeat interval in hours
bool resetFlag = true;

// Libraries
#include "Adafruit_FONA.h"     // FONA
#include <SoftwareSerial.h>    // FONA
#include <XBee.h>              // Xbee
#include <avr/wdt.h>           // Reset: Remember USB-Serial doesn't work after first reset.
#include <SparkFunDS1307RTC.h> // RTC
#include <Wire.h>              // RTC
#include <SPI.h>               // SD card
#include <SD.h>                // SD card
#include <PayloadClass.h>      // Payload class library

// Debugging
#define LED_PIN 3
int counter = 0;
long timestamp = 0;

// FONA
#define FONA_RX 2
#define FONA_TX 10   
#define FONA_RST 22  
#define FONA_RI 53
//("gprs.swisscom.ch", "gprs", "gprs");  // Configure a GPRS APN, username, and password.
#define APN F("gprs.swisscom.ch")        // Change this according to your providers instructions
#define APN_USR F("gprs")                // Change this according to your providers instructions
#define APN_PWD F("gprs")                // Change this according to your providers instructions 
SoftwareSerial fonaSS = SoftwareSerial(FONA_TX, FONA_RX);
SoftwareSerial *fonaSerial = &fonaSS;
Adafruit_FONA fona = Adafruit_FONA(FONA_RST);// Use this one for FONA 3G: //Adafruit_FONA_3G fona = Adafruit_FONA_3G(FONA_RST);
uint8_t readline(char *buff, uint8_t maxbuff, uint16_t timeout = 0);

// Xbee
XBee xbee = XBee();
XBeeResponse response = XBeeResponse();
// create reusable response objects for responses we expect to handle 
ZBRxResponse rx = ZBRxResponse();
ModemStatusResponse msr = ModemStatusResponse();

// SD card
const int chipSelect = 8;

// Other
String payload;
bool sd_ignore_flag = 0;
int gprs_fail_counter = 0;


/*********************
 * Setup             *
 *********************/
void setup() {
// Initialize serial connection --------------------------------------------------------
  Serial.begin(9600);
  Serial.println("Serial initialized");
  
// Initialize Xbee ---------------------------------------------------------------------
  Serial3.begin(9600);
  xbee.setSerial(Serial3);
  Serial.println("Xbee initialized");
  
// Initialize Fona ---------------------------------------------------------------------
  fonaSerial->begin(4800);
  if (! fona.begin(*fonaSerial)) {
    Serial.println("FONA not OK");
    while (1);
  }
  Serial.println("FONA OK");
  Serial.println("Wait for Call Ready & SMS Ready messages");
  delay(14000); // Wait for "Call Ready" & "SMS Ready" messages
  while (fona.available()) {
      Serial.write(fona.read());
  }
  // turn GPRS on
  startGPRS();
  Serial.println("FONA initialized");

// Initialize RTC  --------------------------------------------------------------------
  rtc.begin(); // Call rtc.begin() to initialize the library
  rtc.set24Hour(); // Use rtc.set24Hour to set to 24-hour mode
  Serial.println("RTC initialized.");

// Initialize SD card  ----------------------------------------------------------------
  if (!SD.begin(chipSelect)) {
    Serial.println("SD card failed, or not present");
    sd_ignore_flag = 1;
  } else {
    Serial.println("SD card initialized.");
  }

// Debugging
  Serial.println("End Setup");
  blink(10);
}


/*********************
 * Loop              *
 *********************/
void loop() {
// Debugging ---------------------------------------------------------------------------
  timestamp = millis()/1000;
  Serial.print(counter++);
  Serial.print(": ");
  Serial.println(timestamp);
  delay(1500);
  blink(2);
  
// If Xbee message available, retrieve it-----------------------------------------------
  xbee.readPacket();
  if (xbee.getResponse().isAvailable()) {// got something
    if (xbee.getResponse().getApiId() == ZB_RX_RESPONSE) {// got a zb rx packet
      payload = getXbeePacket();
//  -> send to webserver ---------------------------------------------------------------
      send2Server();
      resetFlag = false;
      blink(5);
//  -> Write to SD card ----------------------------------------------------------------
      write2SD();
      }
  }

// If it is time send heartbeat message
  if (timestamp>(heartbeat_interval*3600)){
    heartbeat();
    Serial.println("Send heartbeat message");
  }
  
// Reset: If send2Server failed more than 100 times reset gateway.
//        If running for longer than 24 hours
  if (gprs_fail_counter>5){
    Serial.print("gprs_fail_counter =");
    Serial.println(gprs_fail_counter);
    reset();
  }
  if (timestamp>24*3600){
    Serial.print("millis()=");
    Serial.println(millis());
    reset();
  }
}


/*********************************************
 * Retrieve Xbee packet                      *
 *********************************************/
String getXbeePacket(){
    // now fill our zb rx class
    xbee.getResponse().getZBRxResponse(rx);   
    unsigned char payload[rx.getDataLength()];      
    for (int i = 0; i < rx.getDataLength(); i++) {
      payload[i] = char(rx.getData()[i]);
    }
    char payloadCharArray[sizeof(payload)*3+1];
    for (int i=0; i < sizeof(payload); i++){
      hex2char(payloadCharArray, i*3, byte(payload[i]));
      payloadCharArray[i*3+2] = '.';
    }
    payloadCharArray[sizeof(payloadCharArray)-1] = '\0';
    return payloadCharArray;
}
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

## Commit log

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2017-03-30 Added eagle files and source code for heat flux sensor module
    [heatflow.brd, heatflow.sch]
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2017-04-18 Added lots of files
    - Added Arduino scripts
    - Added Eagle schematics and layouts
    - Added PHP files
    - New name scheme for folders and files
    [Communication_Module_v2.brd, Communication_Module_v2.sch, Router-Node_v4.prt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]
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2017-05-01 Revert "Changed something"
    This reverts commit e7fad535a0aed3b7ca3650d1b08948d39ff050b6.
    [Sensor_Board_0x02_Temperature_Humidity_SHT31_v1.sch]
2017-05-01 Changes on SensModule TSL2561
    - removed R11
    - added pogohead programming connector
    [Sensor_Board_0x04_Luminosity_TSL2561_v1.brd, Sensor_Board_0x04_Luminosity_TSL2561_v1.sch]
2017-05-01 Changes on SensModule SHT31
    - removed R4
    - added pogopin programming connector
    [Sensor_Board_0x02_Temperature_Humidity_SHT31_v1.brd, Sensor_Board_0x02_Temperature_Humidity_SHT31_v1.sch]
2017-05-01 Changes on SensModule TSL2561
    - minor changes on schema
    [Sensor_Board_0x04_Luminosity_TSL2561_v1.sch]
2017-05-01 Changes on SensModule 2xDS18B20
    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
    [Sensor_Board_0x08_Dual_Temperatures_2xDS18B20_v1.brd, Sensor_Board_0x08_Dual_Temperatures_2xDS18B20_v1.sch]
2017-05-01 Changes on SensModule CO2 S8
    - added poppin programming connector
    - moved communication connectors closer together
    - turned C3
    [Sensor_Board_0x06_CO2_S8_v1.brd, Sensor_Board_0x06_CO2_S8_v1.sch]
2017-05-01 Changes on SensModule Pulse
    - moved connectors closer together
    - turned various components
    - removed digital input jumper and put digi_input 1 and 2 directly to
    PD2, PD3
    - put wakeup on PC1
    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
    [Sensor_Board_0x09_0x10_Pulse_v1.brd, Sensor_Board_0x09_0x10_Pulse_v1.sch]
2017-05-02 Changes on all boards
    - added capacitor on reset-path
    - changed order of pogopin programmer pins
    Pulse-Board:
    - Deleted input-jumper. Currently one interrupt-pin missing, so print is
    not yet routed.
    [Sensor_Board_0x02_Temperature_Humidity_SHT31_v1.brd, Sensor_Board_0x02_Temperature_Humidity_SHT31_v1.sch, Sensor_Board_0x04_Luminosity_TSL2561_v1.brd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]
2017-05-04 Changed SensorBoard SHT31
    - changed pogopin-programmer to FTDI
    - connection with comboard is now over software serial instead of
    hardware serial
    [Sensor_Board_0x02_Temperature_Humidity_SHT31_v1.brd, Sensor_Board_0x02_Temperature_Humidity_SHT31_v1.sch]
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2017-05-09 Changed some SensorBoards
    SHT31
    - new routing
    PULSE
    - pogopin programmer now over FTDI
    - interrupt to comboard now comes from atmega
    TSL2561
    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
    [Sensor_Board_0x02_Temperature_Humidity_SHT31_v1.brd, Sensor_Board_0x04_Luminosity_TSL2561_v1.brd, Sensor_Board_0x04_Luminosity_TSL2561_v1.sch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]
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2017-05-15 Finished some boards.
    - Minor changes on all boards except
    [Sensor_Board_0x02_Temperature_Humidity_SHT31_v1.brd, Sensor_Board_0x04_Luminosity_TSL2561_v1.brd, Sensor_Board_0x06_CO2_S8_v1.brd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]
2017-05-16 Changes on Sensor Modules
    - Finished SensModule-Prototype
    - Changed some pin-descriptions on SensModule CO2
    [Sensor_Board_0x06_CO2_S8_v1.brd, Sensor_Board_0x06_CO2_S8_v1.sch, Sensor_Board_0xXX_Prototyping_v1.brd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]
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2017-06-19 Update U-Value board, Added Readme for sensor boards
    [Sensor_Board_U-Value.brd, Sensor_Board_U-Value.sch]
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2017-07-24 Changes Library & TSL2561
    - moved reset path a bit around
    - corrected faulty connector in library and on print
    [Sensor_Board_0x04_Luminosity_TSL2561_v1.brd, Sensor_Board_0x04_Luminosity_TSL2561_v1.sch]
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2017-08-02 Removed gap between connectors to commBoard, added power jack
    [Sensor_Board_0x06_CO2_S8_v1.brd, Sensor_Board_0x06_CO2_S8_v1.sch]
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2017-08-06 SHT31
    - reset path
    - sensor connector footer
    [Sensor_Board_0x02_Temperature_Humidity_SHT31_v1.brd, Sensor_Board_0x02_Temperature_Humidity_SHT31_v1.sch]
2017-08-06 TSL2561
    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
    [Sensor_Board_0x04_Luminosity_TSL2561_v1.brd, Sensor_Board_0x04_Luminosity_TSL2561_v1.sch]
2017-08-06 Pulse-Board
    - Reset path
    - Various small things
    [Sensor_Board_0x09_0x10_Pulse_v1.brd, Sensor_Board_0x09_0x10_Pulse_v1.sch]
2017-08-06 CO2-Board
    - some small changes
    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
    [Sensor_Board_0x06_CO2_S8_v1.brd, Sensor_Board_0x06_CO2_S8_v1.sch]
2017-08-06 DS18B20 - Board
    - adjusted reset path
    - minor changes in layout
    [Sensor_Board_0x08_Dual_Temperatures_2xDS18B20_v1.brd, Sensor_Board_0x08_Dual_Temperatures_2xDS18B20_v1.sch]
2017-08-06 Prototype - Board
    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
    [Sensor_Board_0xXX_Prototyping_v1.brd, Sensor_Board_0xXX_Prototyping_v1.sch]
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2017-09-12 Error TSL2561
    Rotated the sensor connector by 180 deg.
    [Sensor_Board_0x04_Luminosity_TSL2561_v1.brd]
2017-10-26 Changed Sensorboard TSL2561
    - adjusted connector of comboard to a consistent distance
    [Sensor_Board_0x04_Luminosity_TSL2561_v1.brd]
2017-11-03 Update SensorBoard TSL2561
    new reference print - updated all placements, defined positions of
    connectors and improved routing.
    [Sensor_Board_0x04_Luminosity_TSL2561_v1.brd, Sensor_Board_0x04_Luminosity_TSL2561_v1.sch]
2017-11-06 Changes on PulseBoard
    - startet replacement and rerouting
    - corrected faulty VCC-Connection
    [Sensor_Board_0x09_0x10_Pulse_v1.brd, Sensor_Board_0x09_0x10_Pulse_v1.sch]
2017-11-06 Finished Changes on PulseBoard
    Pulseboard:
    - tidied up routing and placement
    TSL2561:
    - tidied up some connections
    [Sensor_Board_0x04_Luminosity_TSL2561_v1.brd, Sensor_Board_0x09_0x10_Pulse_v1.brd, Sensor_Board_0x09_0x10_Pulse_v1.sch]
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2017-11-15 Update SHT31
    - only descriptions missing
    [Sensor_Board_0x02_Temperature_Humidity_SHT31_v1.brd, Sensor_Board_0x02_Temperature_Humidity_SHT31_v1.sch]
2017-11-16 Finished SHT31 and CO2-Board
    - finished tidying SHT31
    - added FTDI-connector to CO2-Sensorboard
    - tidied CO2-Sensorboard
    [Sensor_Board_0x02_Temperature_Humidity_SHT31_v1.brd, Sensor_Board_0x04_Luminosity_TSL2561_v1.brd, Sensor_Board_0x06_CO2_S8_v1.brd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]
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2018-01-10 Added CAD files for cable reel
    The cable reels helps keeping the sensor cables tidy.
    [cable_reel_v1.prt, cable_reel_v1.stl]
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2018-01-20 Changes CO2 and combined mask.
    - added combined mask of all new PCBs
    - rotated a cap on CO2-Board by 90°
    [SensorBoards_Combined_Mask_20_01_2018.brd, Sensor_Board_0x06_CO2_CCS811_v2.brd]
2018-01-20 Corrected mistake on C02-Board
    -Connected enable-pin of sensor to GND
    [Sensor_Board_0x06_CO2_CCS811_v2.brd, Sensor_Board_0x06_CO2_CCS811_v2.sch]
2018-01-20 Various changes
    - updated two masks
    - changed combined mask again
    - tiedied up CO2 sensor a bit
    - used another footprint for TSL2561-sensor
    [SensorBoards_Combined_Mask_20_01_2018.brd, Sensor_Board_0x04_Luminosity_TSL2561_v2.brd, Sensor_Board_0x04_Luminosity_TSL2561_v2.sch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]
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2018-02-01 Fixed chamfer of battery box cad file
    [battery_box_v2.prt, battery_box_v2.stl]
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2018-02-04 added missing chamfer
    [battery_box_v2.prt, battery_box_v2.stl]
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2018-03-12 Opened new Projekt for Heat Flux v2
    - should be based on Atmega
    [Sensor_Board_0x07_Heat_Flux.brd, Sensor_Board_0x07_Heat_Flux.sch, Sensor_Board_0x07_Heat_Flux_v2.brd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]
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2018-05-23 Added new Gateway versions (with improved integrety against signal interference)
    [WSN_Gateway_v4.1.brd, WSN_Gateway_v4.1.sch, WSN_Gateway_v4.2.brd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]
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2018-08-03 Rename files
    Rename file names from sensor board / communication board to sensor modules / main modules
    [BOM_Sensor_Module_0x02_Temperature_Humidity_SHT31_v2.xlsx, BOM_Sensor_Module_0x04_Luminosity_TSL2561_v2.xlsx, BOM_Sensor_Module_0x05_0x09_0x10_0x11_Pulse_v1.xl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]
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2019-01-12 CAD: Reed switch lock iteration for right tolerance
    [Reed_switch_transport_lock_v1.1.stl, Reed_switch_transport_lock_v1.10.stl, Reed_switch_transport_lock_v1.11.stl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]
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2019-03-29 fix pins of arduino mkr
2019-05-08 Update mysql database structure
    A database updated required to define the the default values in the tables. Otherwise, insertions were no longer possible.
2019-05-08 Shorten directory names and file names
    [Sensor_Module_0x02_TH_SHT31_v1.brd, Sensor_Module_0x02_TH_SHT31_v1.sch]
2019-05-08 Shorten file names
    [BOM_Sensor_Module_0x02_TH_SHT31_v2.xlsx, Sensor_Module_0x02_TH_SHT31_v2.brd, Sensor_Module_0x02_TH_SHT31_v2.sch]
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2019-12-12 Add main_module_v4.8
    // Improvements from v4.7
    // - Check debug switch only once in the setup function (tested)
    // - Remove debug_mode_has_been_switched_off (tested)
    // - Implement universal coordinator address (tested)
    // - Replace THIS_CM_ID by MAIN_MODULE_ID (tested)
    // - Apply payload class to standard measurement payload (tested)
    // - Improve terminology of Payload class (tested)
    // (message vs payload vs myMessage vs myPayload)
    // - Remove dublicate RTC interrupt settings (tested)
    // - Integrate wakeup and sleep into xbee_transmit_data (tested)
    // - Move extended setup to regular setup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
    [Main_module_v4.8.ino]
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2020-03-11 fix python 3 compatibility issues (probably)
    [Serial_Sensor_Module_Reader_v2.py]
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

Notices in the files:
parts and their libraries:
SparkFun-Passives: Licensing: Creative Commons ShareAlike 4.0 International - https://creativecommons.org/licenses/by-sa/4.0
